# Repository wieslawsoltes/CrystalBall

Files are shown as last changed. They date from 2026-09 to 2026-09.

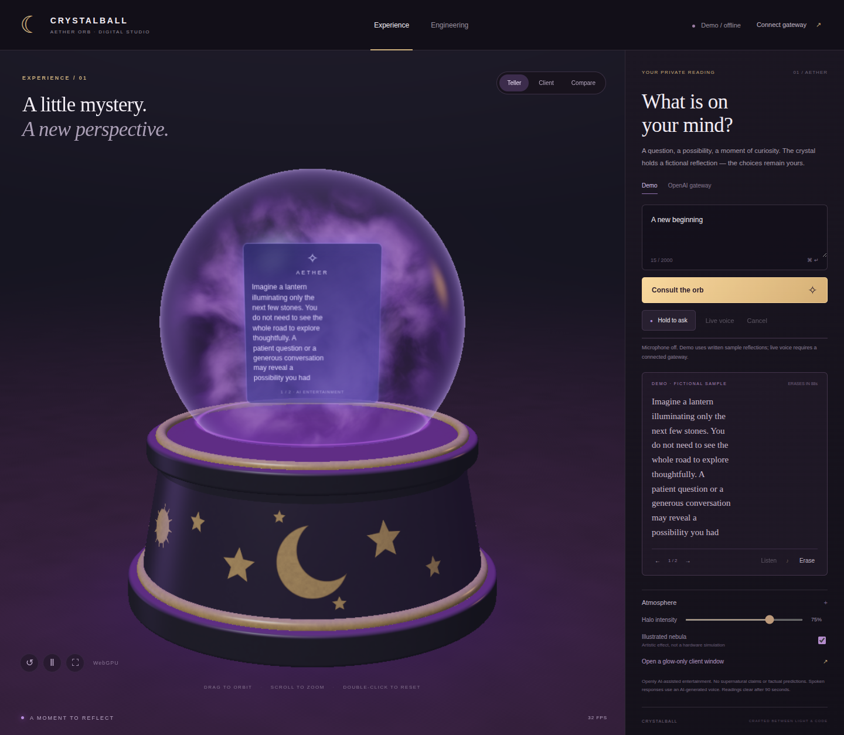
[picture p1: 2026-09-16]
verification/pages/teller.png

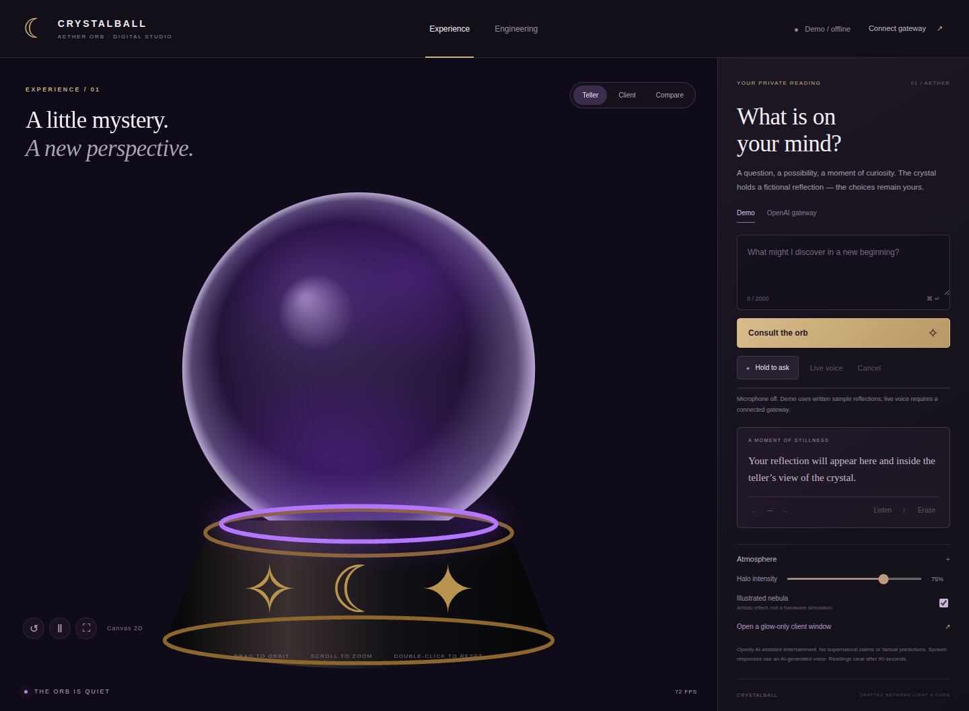
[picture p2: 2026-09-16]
verification/browser/06-fallback.png

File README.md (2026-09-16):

# CrystalBall

**Aether Orb — hardware, firmware, manufacturing engineering and a WebGPU digital studio.**

A tabletop AI-assisted entertainment prop with a hollow optical globe, an operator-facing reflected display, push-to-talk audio and a decorative illuminated base. The browser recreates the concept's sphere, purple illumination, black/gold celestial base and private teller display; the Engineering view loads the actual CAD tessellation.

**Release: engineering candidate. Not approved for production manufacture or sale.** Physical fit, optical privacy/readability, supplier selection, thermal/electrical qualification, production security and market compliance remain release gates. The browser's volumetric nebula is artistic, not a claim that LEDs create a cloud inside an empty globe. Exact visual identity has not been accepted.

## Browser prototype online

**[Open CrystalBall on GitHub Pages](https://wieslawsoltes.github.io/CrystalBall/)** — offline demo by default, including the WebGPU experience and CAD inspector. The Python gateway is hosted separately. [Pages deployment and pairing](docs/github-pages.md) explains the repository-path checks, publication manifest and CORS configuration.

## Rendering and input hardening

The renderer now caps surface area and adapter dimensions, allows only one outstanding GPU frame, suspends redundant paused/CAD submissions, and adapts resolution with hysteresis. Device loss/disposal releases GPU resources and aborts stale initialization or CAD uploads. Two-finger pinch, focused-canvas arrow keys, +/- zoom and Home reset complement mouse controls. See [resource ownership and validation](docs/renderer-lifecycle.md). These are bounded-work/resource improvements, not measured hardware FPS claims.

## Start the browser without an API key

```sh
git clone https://github.com/wieslawsoltes/CrystalBall.git
cd CrystalBall
python -m http.server 8088 --directory web
```

Open `http://localhost:8088`. No build or CDN dependencies are needed. Demo readings are explicitly fictional samples. WebGPU is preferred; Canvas 2D is a fallback. The application includes teller/client/comparison modes, orbit/zoom, a separate glow-only client window, a CAD part inspector with explosion/isolation, text paging, cancellation and timed erasure. The client display mode is a presentation feature, not an authentication boundary.

## Use your OpenAI key for text and voice

The project API key stays on your trusted gateway host. The browser receives a separate device token; it does not ask for or persist an OpenAI project key.

```sh
python factory/configure_gateway.py --unit orb-0001 --url https://orb-gateway.home.arpa --speech
cd gateway
docker compose up --build -d
```

The tool prompts for the project key without echo and creates `gateway/.env` plus `factory/private/orb-0001.json` with restrictive POSIX permissions. It refuses to overwrite existing credentials. Windows deployments need corresponding NTFS ACLs.

Configure LAN DNS to point `orb-gateway.home.arpa` at the gateway machine. The supplied Caddy configuration uses a local CA: export and explicitly trust its **public root certificate** on your clients. Do not disable certificate verification or distribute CA private keys. Open the HTTPS site, select **Connect gateway**, enter its origin and the device token from the private JSON, then ask a question or hold the microphone button.

Text generation, transcription and synthesized speech use paid OpenAI APIs. Set model names in `.env` for models available to your account. No live paid provider test has been performed in this repository's CI. Speech requires `--speech`; the voice is disclosed as AI-generated. Experimental native WebRTC voice additionally requires `--realtime`. Leave it disabled for production until live provider/device and fault-injection qualification is completed. Known calls now have durable SQLite lifecycle recovery; ambiguous creates block new voice admission until an operator reconciles them. See [recovery and cancellation design](docs/runtime-recovery.md).

The gateway runs as UID 10001 on a read-only root filesystem, uses a persistent SQLite request-admission database, enforces bounded requests and permits a single worker. Request quotas are not exact monetary caps. The browser unlocks Web Audio in the user gesture, stops microphone tracks on cancellation and uses no local/session storage for credentials or transcripts. Actual Safari/iPhone audio and microphone behavior still require representative-device testing.

## Engineering and manufacturing files

| Area | Entry point |
|---|---|
| Manufacturing handbook | [Editable guide](manufacturing/handbook.md) / [PDF](manufacturing/generated/CrystalBall-RevB-Handbook.pdf) / [HTML](manufacturing/generated/handbook.html) |
| BOM, harness, inspection and fixture tables | [Generated manufacturing package](manufacturing/generated/) |
| Native KiCad CAM | [cam-native](manufacturing/cam-native/) — read the hold notice; do not mix export sets |
| ECAD project | [KiCad project](hardware/aether-carrier.kicad_pro), [PCB](hardware/aether-carrier.kicad_pcb), [schematic](hardware/aether-carrier.kicad_sch) |
| Mechanical source | [CadQuery generator](mechanical/model.py), [Rev B assembly STEP](mechanical/Aether_Orb_RevB_Assembly.step), individual [STEP](mechanical/step/) and [STL](mechanical/stl/) |
| Firmware | [ESP-IDF project](firmware/) |
| Gateway and browser | [gateway](gateway/) / [web](web/) |
| Commissioning | [Factory tools](factory/) |
| Release evidence gate | [Requirements](manufacturing/release-plan.json) / [checker](factory/release_gate.py) / [signed evidence](factory/evidence.py) |
| First-article data evaluator | [Draft plan](manufacturing/qualification-plan.json) / [measurement tool](factory/measurements.py) |
| Test provenance | [Verification notes](verification/README.md) and [validated screenshots](preview/validated/) |

The original **63 Rev A files** are preserved byte-for-byte at commit `f430900c5269cbada520c0550a1a0a9df75eb3ed`, checked by `provenance/reva/SHA256.json`. Subsequent revisions are separate commits. `parameters.json` is generated documentation; edit the mechanical generator's `P` dictionary, not that JSON, to change geometry.

## Build firmware and provision a development unit

Use ESP-IDF **v5.5.2** with the specified ESP32-S3-DevKitC-1-N8R8. Copy only your gateway's trusted public CA certificate to `firmware/main/gateway_ca.pem` and then:

```sh
cd firmware
idf.py set-target esp32s3
idf.py build
```

Before connecting DevKit USB: remove product power, allow and verify discharge, then **remove the DevKit from both carrier sockets**. Removing the RUN shunt alone does not isolate signal paths. Do not dual-power an installed DevKit.

```sh
# From repository root, in an activated ESP-IDF environment:
python factory/provision.py --device factory/private/orb-0001.json --generate
# Explicit NVS-only flash, with the DevKit already removed from both sockets:
python factory/provision.py --device factory/private/orb-0001.json --flash --port /dev/ttyUSB0 --devkit-detached
```

Use one provisioning invocation for a unit: the tool deliberately refuses to reuse its private output folder. The passphrase is prompted without echo. NVS offsets come from the checked-in partition table. **This is plaintext development provisioning, not production secure storage.** No eFuses are automatically changed. Production signing/encryption, key custody, recovery and update policy require an approved security workflow. The three network-capable CI profiles use disposable build-only CAs and are not deployable customer firmware. The separate offline diagnostic artifact below needs no CA, but remains bench-only and physically unqualified.

## Offline first-article diagnostics

The fourth firmware profile, **factory-diagnostics**, has a separate entry point and does not initialize application networking or read device credentials. It provides ten button-driven pages: instructions, optical alignment grid, black, white, RGB bars, checkerboard, gray ramp, a 16-pixel RGB walk, a held-button 1 kHz test tone and microphone digital statistics. Capture is not saved or uploaded. Driver success and digital levels never become automatic manufacturing passes.

Read [the complete bench procedure](docs/bench-diagnostics.md) before using the diagnostic build. The same detached-DevKit programming rule applies. From an activated ESP-IDF 5.5.2 environment, in `firmware/`:

```sh
idf.py -B build-diagnostics \
  -D SDKCONFIG="$PWD/build-diagnostics/sdkconfig" \
  -D SDKCONFIG_DEFAULTS="sdkconfig.defaults;sdkconfig.diagnostics" \
  -D IDF_TARGET=esp32s3 build
```

CI inspects the linked diagnostic image and exact flash-image addresses before producing **factory-diagnostics-bench-only-NOT-CUSTOMER-FIRMWARE**. That artifact contains only the bootloader, partition table, diagnostic application, flashing metadata and a source/hash manifest. No NVS provisioning image, gateway CA or credential is included. Do not flash it to a security-enrolled production controller or mistake it for an approved customer release.

## Verify and regenerate

```sh
python -m pip install './gateway[test]' reportlab
python -m pytest gateway/tests factory/tests -q
npm --prefix web test
python tools/manufacturing.py
python factory/release_gate.py --output manufacturing/generated/release-status.json
```

The final command currently exits **1 / BLOCKED** because physical qualification and owner approvals are absent. That is intentional. Without a trust policy it validates structure only. With an independently pinned reviewer policy, it verifies Ed25519 signatures, scoped reviewer quorums, expiry/revocation and both source and manufacturing-output fingerprints. No trusted reviewer ships with the project. Neither mode certifies the product or authorizes production. See [signed evidence and measured qualification](docs/qualification-evidence.md).

GitHub Actions also compiles all four firmware profiles, runs KiCad 9.0.9 ERC/DRC/schematic parity, exports native CAM, tests a read-only Docker deployment and exercises the browser on a software WebGPU adapter with mocked OpenAI responses. See [Actions](https://github.com/wieslawsoltes/CrystalBall/actions) for the exact commit under test. Archived evidence is dated, not automatically promoted to cover later design changes.

The [bench/renderer batch record](verification/bench-renderer/summary.json) links the exact engineering, browser and public Pages runs and distinguishes their source commits. It is an engineering evidence index, not a signed release authorization.

## Remaining production gates

The handbook and generated tables distinguish selected ordering codes from unresolved suppliers, proposed assembly lengths/torques/acceptance limits from measured limits, and envelope models from real components. Optical viewing-volume tests, a fitted first article, power/inrush/fault/thermal tests, radio/EMC/ESD and market assessment, secure provisioning/recovery, real OpenAI/mobile-device validation, assembly capability and transport qualification are still required. No conformity mark or production authorization is implied by this repository.

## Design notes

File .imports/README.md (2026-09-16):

# Byte-identical Rev A baseline import

These seven consecutive binary pieces constitute an XZ-compressed tar of the supplied engineering source files, cached PCB routes, original reports, SHA-256 manifest, and STEP presentation records. This is a file-transfer container, not encrypted content. Combined archive SHA-256: `1949999319f49bb6eb79f5541bd68453d9aae72ab17f88fe3aad5c4ecf256c3f`.

`ci/import_reva.py` extracts only regular in-repository paths, runs the supplied deterministic PCB/schematic/CAD generators, restores the original STEP timestamp and presentation ordering, and verifies all 63 original files against their SHA-256 hashes. The workflow refuses to commit on any mismatch. Local reconstruction of the STEP was checked byte-for-byte: SHA-256 `f9fd1863567ffd259ce29d91b40138dd55b617014c063486c2b0213de5262db6`.

Reconstruction is only transport normalization. The original Rev A design and original validation limitations are unchanged; this is not a new production release. Subsequent engineering changes belong in separate commits.

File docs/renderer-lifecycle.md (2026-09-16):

# Browser rendering and resource ownership

The browser keeps the existing crystal/glass WGSL and artistic design. This change is resource scheduling/input hardening, not a claim of measured hardware FPS or exact physical optics.

A surface is bounded by 1.2 million pixels, 1000 px height, DPR 1.5 and the adapter's texture limit. This prevents ultra-wide or high-DPI windows from allocating unbounded swap/depth surfaces. Dynamic resolution uses submission-completion latency with hysteresis, from quality 1.0 down to 0.5; it is not a GPU timestamp-query measurement. At most one frame is outstanding. Paused scenes and stationary CAD do not submit redundant GPU frames. Scene time excludes pauses and hidden-tab intervals and clamps large scheduler discontinuities.

Renderer initialization, device acquisition, queue completion and CAD upload carry a generation identity. Disposal invalidates that generation, aborts outstanding fetches and removes observers/listeners. A late acquired device is destroyed. Lost-device fallback releases GPU buffers/textures, replaces the formerly WebGPU-bound canvas, and installs input on the replacement. Concurrent CAD requests share one transaction. Bounded streaming reads and full structural validation precede allocation; partial allocation failures destroy every owned resource. Uploaded meshes retain only metadata, GPU buffers and reusable uniforms rather than the large source geometry arrays.

Pointer capture supports orbit and two-touch pinch zoom. Cancellation/lost capture stops the gesture. Wheel units are normalized, keyboard arrows orbit, +/- zoom, and Home resets. These controls apply only to the focused canvas, preserving normal form keyboard behavior. Ctrl/Alt/Meta modified keys are not intercepted. Motion pause state is reflected in the accessible button label.

The engineering viewer renders actual tessellation in opaque/transparent passes. Its simple material shading is not a physically refractive CAD optical solver; transparent meshes are not depth-sorted per triangle. Low-resolution adaptive beauty rendering is a tradeoff, not a substitute for physical-device performance qualification.

Validation includes network-free policy/input/lifetime tests plus an actual Chromium WebGPU fixture for concurrent upload, idle redraw suppression, keyboard control, deliberate device loss and idempotent disposal. The fixture uses shipped modules with the production CSP active. The separate integration suite covers text/audio through a mocked provider, and Pages tests exercise `/CrystalBall/` before public SHA-256 verification.

Browser GPU contract: https://www.w3.org/TR/webgpu/ (reviewed 2026-09-16).

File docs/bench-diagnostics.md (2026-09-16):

# Offline first-article bench diagnostics

The `factory-diagnostics` ESP32-S3 profile runs the real display, LED and audio drivers without loading device credentials, initializing the application network, or contacting any gateway. It is **bench-only engineering firmware, not customer firmware or a manufacturing acceptance pass**. Existing automatic release gates remain blocked pending independently reviewed physical evidence.

## Power and programming boundary

Disconnect carrier power and **remove the DevKit from both carrier sockets before connecting either DevKit USB connector**. Do not attempt in-circuit USB programming or dual-power the controller. Program the removed development board, disconnect its USB cable, reinstall with the marked orientation and only then power the carrier from the reviewed 5 V source. Use the already defined current-limited first-power procedure. Do not attach a UART fixture to an unknown or powered interface. This mode deliberately needs no host serial connection while installed.

The image is for ESP32-S3-DevKitC-1-N8R8 and the Rev B module wiring. It does not burn eFuses, encrypt NVS, sign production firmware, override secure boot, or establish hardware safety. Do not use an unsigned bench image on a controller already enrolled in an irreversible production security policy. Never use a power adapter or PD jumper configuration that could deliver more than the specified input voltage.

## Build without a gateway certificate

Use ESP-IDF 5.5.2 and a clean, isolated build/config directory. From `firmware/`:

```bash
. "$IDF_PATH/export.sh"
idf.py -B build-diagnostics \
  -D SDKCONFIG="$PWD/build-diagnostics/sdkconfig" \
  -D SDKCONFIG_DEFAULTS="sdkconfig.defaults;sdkconfig.diagnostics" \
  -D IDF_TARGET=esp32s3 build
```

No `main/gateway_ca.pem` is required for this profile. `CONFIG_ORB_FACTORY_DIAGNOSTICS=y` selects a separate `factory_main.c`, excluding `app_main.c`, `network.c`, `config.c` and the CA embedding from the application. Framework dependency discovery remains unconditional because ESP-IDF expands component requirements before Kconfig values are available. Link-time checks inspect the actual ELF for absence of the application network/configuration functions and `esp_wifi_start`; this is not a claim that the SDK dependency graph contains no Wi-Fi components.

Review the generated `flasher_args.json` and all image addresses before using the standard IDF flash command, with the board physically removed as above. Do not invoke `erase-flash`: bench programming should not intentionally erase a separately provisioned NVS partition. The diagnostic application never reads that NVS content, but leaving it present does not provide confidentiality. Reinstall the intended application and requalify its provisioning before returning a board to use.

The CI bench artifact contains only the bootloader, partition table and diagnostic application, with exact addresses, a source commit and SHA-256 hashes. It contains **no NVS image, API key, gateway token, Wi-Fi password or CA**. Verify the artifact provenance and hashes before use. The hashes detect mismatched files; they do not replace a firmware-signing policy or physical inspection.

## Local controls and ten pages

Release both buttons after boot. **PAGE** advances one page per debounced press. **TALK** activates the selected LED, tone or microphone test. A held button at boot cannot trigger sound. Releasing and pressing again is required to repeat an action; none of the tests auto-repeat.

| Page | Operation | Required human observation |
|---|---|---|
| Help | Instructions; microphone and amplifier off | Correct boot/profile, legible text |
| Optical grid | Existing asymmetric orientation/calibration chart | Teller orientation, readable viewing zone, client-side leakage |
| Black | Exact RGB565 zero field, decorative pixels off | Leakage, lit/stuck pixels, ambient reflections |
| White | Exact RGB565 `0xffff`, no overlay text | Uniformity, dark/stuck pixels, optical contamination |
| Color bars | Eight vertical 40-pixel RGB565 bars | RGB/BGR assignment, column order, uniform color |
| Checker | Eight-pixel black/white cells | Pixel addressing, edge sharpness, interference patterns |
| Gray ramp | 32 horizontal intensity steps | Clipping, banding and contrast |
| Pixel walk | TALK advances one of 16 pixels in red, green then blue | Correct physical index, GRB wiring and missing/swapped pixels |
| Test tone | Hold TALK; release cancels | Speaker path, buzz/rattle, qualified acoustic measurements |
| Microphone | Hold TALK to capture; release displays statistics | Record indicator, usable signal and clipping with controlled stimulus |

Flat fields deliberately have no labels that would invalidate a uniformity/black-level test. The physical LCD's configured optical mirror transform still applies. PAGE extinguishes the pixel walk before leaving it. Driver success only means the driver accepted/completed the operation; the firmware has no optical or acoustic feedback sensor that could confirm a visible or audible pass.

The pixel walk uses one active channel at 12/255, further bounded by the global 32/255-per-channel driver cap. It is not a full-brightness power/thermal test. The 1 kHz tone is synthesized from a 24-sample table at nominal 24 kHz, with a peak digital amplitude of 2048/32768 and 10 ms start/end ramps. At most 24,000 tone frames are queued; the driver loop also checks a one-second monotonic deadline. Cancellation is checked at bounded write boundaries (100 ms write timeout), not by an independent hardware safety interrupt. Keep the speaker away from ears. Actual frequency, sound pressure, latency and amplifier startup behavior require instruments; none are certified by the digital sample values.

Microphone capture uses the same selected channel, configured sample shift, settling interval and high-pass processing as the application. The result shows sample count, integer RMS including residual DC, absolute peak, signed mean, rail-clipped sample count, zero crossings and free internal heap. These are **post-processing digital counts**, not raw converter values, dB SPL or calibrated microphone sensitivity. A zero clipping count cannot prove that the analog microphone or earlier digital stages did not saturate. The maximum retained sample count is 128,000 (eight seconds at 16 kHz), plus the driver's initial settling interval. Silence and malformed/short capture never become automatic passes. Captured WAV and scratch statistics are wiped and freed after display; no audio is saved or transmitted by this mode.

## Evidence, qualification and remaining scope

Record the exact source/artifact hash, unit serial, component lots, test setup, environment, instrument IDs, calibration status, uncertainty and observation in the existing first-article records. Use a controlled acoustic stimulus rather than customer speech. Do not store sensitive microphone recordings in repository artifacts. The factory first-article evaluator and externally authenticated release-evidence tooling remain the acceptance mechanisms; this diagnostic image only makes measurements and observations possible.

Host C tests exercise exact color pixels, bounds/canaries, PCM sign extension, RMS/peak/clipping arithmetic, and tone frequency/envelope using AddressSanitizer/UndefinedBehaviorSanitizer. CI additionally compiles the real ESP32-S3 diagnostic target without a CA and checks the linked symbol/flash-image contract. These checks do not establish actual display SPI timing, microphone I2S alignment, power integrity, optics, EMC, acoustic output, or first-article acceptance.

References reviewed 2026-09-16:
- ESP-IDF 5.5.2 build system: https://docs.espressif.com/projects/esp-idf/en/v5.5.2/esp32s3/api-guides/build-system.html
- ESP-IDF 5.5.2 I2S blocking APIs/timeouts: https://docs.espressif.com/projects/esp-idf/en/v5.5.2/esp32s3/api-reference/peripherals/i2s.html
- DevKitC-1 v1.1 mutually exclusive power options: https://docs.espressif.com/projects/esp-dev-kits/en/latest/esp32s3/esp32-s3-devkitc-1/user_guide_v1.1.html

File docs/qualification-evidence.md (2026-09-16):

# Signed release evidence and measured first articles

These tools close software integrity/authentication gaps. They do not close the product's physical, supplier, regulatory or production-security qualification gates. The repository contains no trusted reviewer, no physical measurement results and no manufacturing approval. Test keys and values are ephemeral/synthetic test fixtures only.

## Prepare a measured unit record

```sh
python factory/measurements.py template --serial orb-0001 --out factory/private/orb-0001-measurements.json
```

The generated record is `NOT_TESTED`; every value is null. The six checkpoints in `manufacturing/qualification-plan.json` are explicitly **DRAFT** and are not safety standards. Qualify the fixture, test method, instruments, operating conditions, viewing grid, numerical limits and uncertainty budget before marking a controlled plan approved. A single nominal contrast reading is not a viewing-volume privacy assessment.

Enter actual decimal values as strings, a strictly positive expanded uncertainty U, declared coverage factor k, instrument ID and its calibration validity interval, fixture ID/revision, UTC acquisition time, and an in-project relative path plus SHA-256 for the raw acquisition file. Unit conversion is deliberately not implicit. Mark the acquisition `MEASURED` only for real measurements, never to promote synthetic examples.

```sh
python factory/measurements.py evaluate --run factory/private/orb-0001-measurements.json --out factory/private/orb-0001-evaluation.json
```

The evaluator uses decimal arithmetic with bounded magnitudes/exponents. It returns PASS only when `[value-U,value+U]` lies entirely inside the declared specification interval, FAIL when disjoint, and INDETERMINATE for overlap. This is an explicit numerical guard-band decision rule, not a guarantee about a distribution or coverage probability. Any missing/duplicate reading, nonfinite value, zero uncertainty, invalid calibration interval, wrong unit, future/stale acquisition, changed plan/source fingerprint, altered attachment, draft plan or synthetic record blocks the run. Valid numerical results remain `WITHIN_DECLARED_LIMITS_REQUIRES_REVIEW`, not production approval.

## Enroll reviewers outside the source repository

Install the security extra in the controlled quality-station environment:

```sh
python -m pip install './gateway[security]'
python factory/evidence.py keygen --private-key factory/private/reviewer-a.private.pem --public-key factory/private/reviewer-a-public.json
python factory/evidence.py policy-template --out factory/private/reviewer-policy.json
```

Key generation prompts for an encryption passphrase, produces encrypted PKCS8 Ed25519 private material with restrictive POSIX permissions, and refuses replacement. Key files must be excluded from commits and distribution packages. Windows needs equivalent NTFS ACLs. Python memory copies, swap/core dumps and the operator workstation require separate security controls; encrypted files do not solve endpoint compromise. Public keys are not secret but must be authenticated during enrollment.

The policy template has **zero keys** and a two-reviewer threshold per requirement; it cannot approve anything. An authorized release authority must independently verify each reviewer's identity/public key, assign narrow requirement scopes, set UTC key validity dates and revocation state, and approve the policy through the organization's quality process. One enrolled key entry has the following shape:

```json
{
  "key_id": "SHA256_OF_RAW_PUBLIC_KEY",
  "public_key": "BASE64_OF_RAW_32_BYTE_PUBLIC_KEY",
  "reviewer": "Independently verified reviewer identity",
  "requirements": ["optical_readability_privacy"],
  "revoked": false,
  "not_before_utc": "2026-09-16T00:00:00Z",
  "expires_utc": "2026-12-16T00:00:00Z"
}
```

Those strings are placeholders, not an enrolled reviewer. Preserve the reviewed policy's exact-file SHA-256 in an independent trusted release configuration; reading a hash from beside an untrusted replacement policy is not pinning. A policy with no keys, missing requirement thresholds, duplicate key IDs or invalid scope/lifetime is rejected. Quorums count distinct enrolled reviewer identities, not how many keys one person owns.

## Bind and sign a review statement

Freeze the evaluated source checkout and regenerated manufacturing outputs before collecting approvals. Obtain both fingerprints:

```sh
python factory/release_gate.py --fingerprint
python factory/release_gate.py --materials-fingerprint
```

Create one review record per requirement with `requirement`, `status`, `reviewer`, `reviewed_utc`, `valid_until_utc`, `source_fingerprint`, `materials_fingerprint`, and `report` containing relative `path` and file `sha256`. A PASS must reflect the reviewer's actual assessment. Failed or unperformed reviews must not be rewritten as PASS. Include raw acquisition and calibration references in the reviewed report under the quality-system retention policy.

```sh
python factory/evidence.py sign --record factory/private/optics-review.json --private-key factory/private/reviewer-a.private.pem --out factory/private/optics-a.signed.json
python factory/evidence.py sign --record factory/private/optics-a.signed.json --private-key factory/private/reviewer-b.private.pem --out factory/private/optics-ab.signed.json
```

The second command adds a distinct reviewer's signature to the same immutable payload. Each signature is Ed25519 over a domain-separated restricted canonical JSON payload bound to product, revision and release-plan hash. This project encoding is explicitly **not RFC 8785/JCS**: it uses sorted keys, ASCII escapes, no floats, no duplicate keys. Decimal measurements belong in hash-bound attachments or string-valued fields. Do not swap encoding implementations without a versioned migration.

Assemble a JSON array containing exactly one completed signed envelope per requirement. Verify it against the independently pinned policy:

```sh
python factory/release_gate.py --evidence factory/private/release-envelopes.json --trust-policy factory/private/reviewer-policy.json --policy-sha256 INDEPENDENTLY_PINNED_64_HEX_DIGEST --output factory/private/signed-release-status.json
```

Invalid signatures, unauthorized/revoked/expired keys, insufficient quorums, duplicate requirements/signatures, plan/product/revision mismatch, stale source/manufacturing outputs, missing/altered reports or evidence expiry all block the check. Reports cannot be empty, exceed 64 MiB, escape the controlled root, or traverse symbolic links. Design fingerprints include build files, container configuration, factory tools and CI workflows; material fingerprints separately cover CAD, native CAM and generated manufacturing documents.

Without a pinned policy, the checker labels its result unauthenticated. Even `AUTHENTICATED_EVIDENCE_COMPLETE_REQUIRES_AUTHORIZED_SIGNOFF` is not authorization to manufacture: an authorized owner must complete the separate controlled release process. Signatures attest to who signed a statement; they do not make false data true, qualify instruments or confer certification.

References reviewed 2026-09-16: the cryptography Ed25519/PKCS8 serialization documentation, Python decimal documentation, and the project's explicit interval decision rule. No regulatory decision rule is claimed.

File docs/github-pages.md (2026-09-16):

# GitHub Pages browser deployment

The public address is `https://wieslawsoltes.github.io/CrystalBall/` after the Pages deployment succeeds. This is the HTML/JavaScript/WebGPU application, not the Python gateway or a device-control server. It opens in explicitly labeled offline demo mode and makes no AI API calls until the operator pairs a gateway and chooses a live feature.

The Pages workflow stages only tracked `web/index.html`, `web/style.css` and allowed source/assets, never the whole repository. It scans for obvious key material, writes a source-commit and per-file SHA-256 manifest to `build.json`, runs JavaScript tests and eight browser checks at `/CrystalBall/`, then publishes through the official Pages artifact/deployment actions. CSP remains enabled. No service worker, transcript persistence, analytics or third-party frontend CDN is installed. The scanner is a secondary guard, not a substitute for source review.

## Pairing a gateway from Pages

For a new gateway installation, the commissioning tool can configure the explicit Pages origin:

```sh
python factory/configure_gateway.py --unit orb-0001 --url https://orb-gateway.home.arpa --speech --browser-origin https://wieslawsoltes.github.io
```

It prompts for your project key without echo and refuses to replace existing credentials. On an already configured gateway, update only `CORS_ORIGINS` in its private environment file; do not regenerate the device token accidentally.

Deploy the gateway at an HTTPS origin with a certificate your browser trusts. Add exactly `https://wieslawsoltes.github.io` to the gateway's `CORS_ORIGINS` environment setting and restart it. The CORS entry is an **origin**: do not add `/CrystalBall/` or a trailing slash, and do not use `*`. Keep your API project key in the gateway environment. Use the separate device token in the browser's Connect gateway dialog. CORS is not authentication; bearer-token validation still applies. All projects on this GitHub Pages hostname share an origin. Use the gateway-hosted application on a dedicated trusted origin for sensitive operation.

Pages cannot host Python, keep an API key secret, reach a private gateway on behalf of a remote visitor, or bypass browser private-network/mixed-content restrictions. For a LAN gateway, the client device must be on the appropriate network and explicitly trust its public CA; browsers may require a local-network permission. Never disable TLS or browser security. When the browser's network policy prevents cross-origin LAN pairing, open the gateway-hosted HTTPS application instead.

## Repository configuration

The repository's Pages source must be **GitHub Actions**. The workflow uses `pages: write` and an OIDC deployment token, not a project API key. If Pages has never been enabled, an owner/maintainer must select Settings > Pages > Build and deployment > Source > GitHub Actions. Normal workflow tokens cannot enable a previously disabled Pages site. Then run **Publish browser to GitHub Pages** from Actions. Subsequent changes under `web/` trigger testing and deployment automatically.

The test evidence uses Chromium's software WebGPU adapter; it does not qualify actual mobile graphics performance or physical optics. The generated `build.json` identifies the actual published source independently of the newer project `main` commit.

References: GitHub's custom Pages workflow documentation and `actions/starter-workflows/pages/static.yml` (reviewed 2026-09-16).

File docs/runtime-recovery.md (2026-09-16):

# Live voice: durable lifecycle and cancellation

## Persistence and the ambiguous-create boundary

Live voice remains opt-in and requires a writable durable journal. Set `REALTIME_DATABASE=/var/lib/orb/voice.sqlite`. For existing environments without that variable, the gateway uses `BUDGET_DATABASE + '.realtime'`. Preserve the same file and mounted volume across upgrades. Do not change paths to make a cleanup warning disappear.

Before a provider POST, the supervisor commits a `RESERVED` record. After receiving a valid OpenAI call-resource Location header, it commits `ACTIVE` with the provider ID before reading the SDP response. Metadata only is stored: local handle, unit ID, provider ID, timestamps, state and cleanup status. SDP, audio, transcripts and credentials are not journaled. SQLite uses WAL and `synchronous=FULL`; the actual filesystem/storage must honor sync operations. A kernel-owned process lock rejects a second worker and releases on process exit.

After restart, every known unfinished call is sent to provider hangup before new voice admission. An interrupted reservation without a provider ID becomes `UNKNOWN`, never a retry of create. A server cannot atomically commit a local database and a remote API transaction: a crash between provider creation and receipt/persistence of its ID is fundamentally ambiguous without a provider-supported reconciliation contract. We do not assume undocumented idempotency or call-list APIs. Those records stay blocked until an operator investigates provider-side termination and records an explicit reconciliation.

Hangup attempts are serialized per call. Only HTTP 200/204 confirms cleanup. In particular, 404/410 are not automatically treated as proof of termination. Failed known cleanup stays on disk, blocks new voice admission and is retried by the running supervisor every five seconds with three bounded attempts per sweep. A storage fault latches admission closed. Text and push-to-talk do not depend on voice readiness. Authenticated capabilities include counts and reason flags, not provider call IDs.

A monotonic timer bounds the intended running voice interval; provider/network outages can prevent remote hangup. Neither this timer nor persistent request admission is an exact spending cap. Pending unresolved records are never age-deleted; closed/reconciled operational records older than seven days are pruned at startup.

## Offline operator workflow

Stop the gateway; the CLI deliberately takes the same exclusive worker lock. In the activated gateway Python environment:

```sh
PYTHONPATH=gateway python -m app.voice_admin --database /path/to/voice.sqlite inspect
```

Investigate the listed provider sessions externally. Save a nonempty report of the investigation. Reconcile one known local handle only after provider termination has been confirmed:

```sh
PYTHONPATH=gateway python -m app.voice_admin --database /path/to/voice.sqlite reconcile \
  --handle LOCAL_HANDLE_FROM_INSPECTION \
  --reviewer 'Named operator' \
  --report /path/to/termination-review.txt \
  --confirmed-provider-closed
```

The journal retains the reviewer, timestamp and report SHA-256, not its contents. This command records an operator attestation, not an independent provider observation or cryptographically authenticated release review. Keep the report under the organization's audit policy. Restart the gateway against the SAME journal. Do not delete SQLite/WAL/SHM/lock files as a recovery procedure.

## Browser cancellation ownership

Each `LiveVoice` attempt owns its media tracks, peer connection, data channel, text buffer, timer and a gateway-credential snapshot. Every awaited boundary checks that the attempt is still current. Late microphone permission, SDP response, remote-description completion and data-channel callbacks cannot reactivate an erased session. A late successful create is terminated using the original gateway credentials, even after the UI is paired elsewhere.

Local cancellation closes capture immediately. The bounded setup request may finish solely to acquire a cleanup handle; it cannot send user audio after tracks are closed. A page/process crash falls back to the durable server lifecycle. The client is still not a financial or optical-privacy security boundary.

## Verification scope

Fault-injection tests exercise persistent reservations, known/unknown restart paths, failed SDP download, malformed provider IDs, worker exclusion, disk failure, concurrent hangup/admission and missing provider confirmation. JavaScript lifecycle tests control each async boundary and assert no stale text or media restoration. Provider traffic is mocked. Actual OpenAI WebRTC connectivity, network failure behavior, Safari/iPhone media policy and physical hardware remain acceptance gates.

## Primary implementation references (accessed 2026-09-16)

- OpenAI Realtime create-call contract: https://developers.openai.com/api/reference/resources/realtime/subresources/calls/methods/create
- OpenAI Realtime hangup: https://developers.openai.com/api/reference/resources/realtime/subresources/calls/methods/hangup
- SQLite synchronous/WAL durability semantics: https://www.sqlite.org/pragma.html#pragma_synchronous

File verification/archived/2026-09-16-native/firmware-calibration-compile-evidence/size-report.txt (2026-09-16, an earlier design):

Executing action: size
Running ninja in directory /__w/CrystalBall/CrystalBall/firmware/build
Executing "ninja all"...
[1/4] cd /__w/CrystalBall/CrystalBall/firmware/build/esp-idf/esptool_py && /opt/esp/python_env/idf5.5_py3.12_env/bin/python /opt/esp/idf/components/partition_table/check_sizes.py --offset 0x8000 partition --type app /__w/CrystalBall/CrystalBall/firmware/build/partition_table/partition-table.bin /__w/CrystalBall/CrystalBall/firmware/build/aether_orb.bin
aether_orb.bin binary size 0x3b930 bytes. Smallest app partition is 0x300000 bytes. 0x2c46d0 bytes (92%) free.
[2/4] Performing build step for 'bootloader'
[1/1] cd /__w/CrystalBall/CrystalBall/firmware/build/bootloader/esp-idf/esptool_py && /opt/esp/python_env/idf5.5_py3.12_env/bin/python /opt/esp/idf/components/partition_table/check_sizes.py --offset 0x8000 bootloader 0x0 /__w/CrystalBall/CrystalBall/firmware/build/bootloader/bootloader.bin
Bootloader binary size 0x57e0 bytes. 0x2820 bytes (31%) free.
[3/4] No install step for 'bootloader'
[4/4] Completed 'bootloader'
Running ninja in directory /__w/CrystalBall/CrystalBall/firmware/build
Executing "ninja size"...
[0/1] cd /__w/CrystalBall/CrystalBall/firmware/build && /opt/esp/tools/cmake/3.30.2/bin/cmake -D "IDF_SIZE_TOOL=/opt/esp/python_env/idf5.5_py3.12_env/bin/python;-m;esp_idf_size" -D MAP_FILE=/__w/CrystalBall/CrystalBall/firmware/build/aether_orb.map -D OUTPUT_JSON= -P /opt/esp/idf/tools/cmake/run_size_tool.cmake
                            Memory Type Usage Summary                             
┏━━━━━━━━━━━━━━━━━━━━━┳━━━━━━━━━━━━━━┳━━━━━━━━━━┳━━━━━━━━━━━━━━━━┳━━━━━━━━━━━━━━━┓
┃ Memory Type/Section ┃ Used [bytes] ┃ Used [%] ┃ Remain [bytes] ┃ Total [bytes] ┃
┡━━━━━━━━━━━━━━━━━━━━━╇━━━━━━━━━━━━━━╇━━━━━━━━━━╇━━━━━━━━━━━━━━━━╇━━━━━━━━━━━━━━━┩
│ Flash Code          │       105668 │          │                │               │
│    .text            │       105668 │          │                │               │
│ DIRAM               │        70131 │    20.52 │         271629 │        341760 │
│    .text            │        54159 │    15.85 │                │               │
│    .data            │        11988 │     3.51 │                │               │
│    .bss             │         3984 │     1.17 │                │               │
│ Flash Data          │        55676 │          │                │               │
│    .rodata          │        55420 │          │                │               │
│    .appdesc         │          256 │          │                │               │
│ IRAM                │        16384 │    100.0 │              0 │         16384 │
│    .text            │        15356 │    93.73 │                │               │
│    .vectors         │         1028 │     6.27 │                │               │
│ RTC SLOW            │           32 │     0.39 │           8160 │          8192 │
│    .force_slow      │           32 │     0.39 │                │               │
│ RTC FAST            │           24 │     0.29 │           8168 │          8192 │
│    .rtc_reserved    │           24 │     0.29 │                │               │
└─────────────────────┴──────────────┴──────────┴────────────────┴───────────────┘

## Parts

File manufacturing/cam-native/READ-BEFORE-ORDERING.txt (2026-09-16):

ENGINEERING CAM CANDIDATE. NOT RELEASED FOR PRODUCTION.
Native KiCad exports: do not mix with hardware/fabrication custom exports.
Hand assembly only. Position data is a reference, not a qualified placement recipe.
Verify supplier footprints, copper weight, polarity, drill plating, legend and tolerances.

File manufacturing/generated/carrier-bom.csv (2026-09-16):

Reference | Qty | Value | Candidate ordering code | Fitted | Footprint | Qualification | Notes | Source
J1 | 1 | DevKitC-1 socket J1 | Samtec SSQ-122-03-G-S | True | Aether:Socket_1x22_P2.54_J1 | CANDIDATE; supplier drawing/FAI required | Use genuine ESP32-S3-DevKitC-1-N8R8 v1.1. Remove module before USB flashing. | https://docs.espressif.com/projects/esp-dev-kits/en/latest/esp32s3/esp32-s3-devkitc-1/user_guide_v1.1.html
J2 | 1 | DevKitC-1 socket J3 | Samtec SSQ-122-03-G-S | True | Aether:Socket_1x22_P2.54_J2 | CANDIDATE; supplier drawing/FAI required | Use genuine ESP32-S3-DevKitC-1-N8R8 v1.1. Remove module before USB flashing. | https://docs.espressif.com/projects/esp-dev-kits/en/latest/esp32s3/esp32-s3-devkitc-1/user_guide_v1.1.html
J3 | 1 | 5V INPUT | Phoenix Contact 1729128 | True | Aether:Terminal_1x02_P5.08_J3 | CANDIDATE; supplier drawing/FAI required | 5.08 mm 2-position terminal; 5 V only. + pin 1; - pin 2. Verify exact holder body. | https://www.phoenixcontact.com/en-us/products/pcb-terminal-block-mkds-15-2-508-1729128
F1 | 1 | PTC 2.5A | Littelfuse RXEF250 | True | Aether:PTC_P5.08_F1 | CANDIDATE; supplier drawing/FAI required | Thermal resettable fuse, not a precise electronic current limiter. Check hold-current derating. | https://www.littelfuse.com/products/polyswitch-resettable-ptcs/radial-leaded/rxef
Q1 | 1 | AO3401A | AO3401A | True | Aether:SOT-23_Q1 | CANDIDATE; supplier drawing/FAI required | P-channel reverse-input protection. Pin 1 G, pin 2 S, pin 3 D. NOT reverse-current blocking while on. | https://www.aosmd.com/res/data_sheets/AO3401A.pdf
R1 | 1 | 100k | RC0805FR-07100KL | True | Aether:R_0805_2012Metric_R1 | CANDIDATE; supplier drawing/FAI required
C1 | 1 | 1000uF 10V | Panasonic EEU-FR1A102 | True | Aether:CP_Radial_D10_P5_C1 | CANDIDATE; supplier drawing/FAI required | Polarized; + pin 1. Measure PD startup/inrush with this bulk capacitance. | https://industrial.panasonic.com/ww/products/pt/aluminum-cap/models/EEUFR1A102
JP1 | 1 | RUN POWER | Samtec TSW-102-07-G-S + 2.54mm shunt | True | Aether:PinHeader_1x02_P2.54_JP1 | CANDIDATE; supplier drawing/FAI required | Fitted shunt for RUN. Remove DevKit completely for USB flashing; do not dual-power.
J4 | 1 | LCD | JST B8B-XH-A(LF)(SN) | True | Aether:XH_1x08_P2.50_J4 | CANDIDATE; supplier drawing/FAI required | Vertical keyed XH header; pin 1 is square; qualify exact supplier drawing. | https://www.jst-mfg.com/product/pdf/eng/eXH.pdf
R2 | 1 | 33R | RC0805FR-0733RL | True | Aether:R_0805_2012Metric_R2 | CANDIDATE; supplier drawing/FAI required
R3 | 1 | 33R | RC0805FR-0733RL | True | Aether:R_0805_2012Metric_R3 | CANDIDATE; supplier drawing/FAI required
J5 | 1 | MIC 3V3 | JST B6B-XH-A(LF)(SN) | True | Aether:XH_1x06_P2.50_J5 | CANDIDATE; supplier drawing/FAI required | Vertical keyed XH header; pin 1 is square; qualify exact supplier drawing. | https://www.jst-mfg.com/product/pdf/eng/eXH.pdf
J6 | 1 | AMP 5V | JST B6B-XH-A(LF)(SN) | True | Aether:XH_1x06_P2.50_J6 | CANDIDATE; supplier drawing/FAI required | Vertical keyed XH header; pin 1 is square; qualify exact supplier drawing. | https://www.jst-mfg.com/product/pdf/eng/eXH.pdf
R4 | 1 | 10k | RC0805FR-0710KL | True | Aether:R_0805_2012Metric_R4 | CANDIDATE; supplier drawing/FAI required
U1 | 1 | SN74AHCT1G125 | SN74AHCT1G125DBVR | True | Aether:SOT-23-5_U1 | CANDIDATE; supplier drawing/FAI required | 5V TTL input buffer; /OE grounded. Qualify TI DBV footprint before ordering. | https://www.ti.com/lit/ds/symlink/sn74ahct1g125.pdf
C2 | 1 | 100nF | GRM21BR71H104KA01L | True | Aether:C_0805_2012Metric_C2 | CANDIDATE; supplier drawing/FAI required
R5 | 1 | 100k | RC0805FR-07100KL | True | Aether:R_0805_2012Metric_R5 | CANDIDATE; supplier drawing/FAI required
R6 | 1 | 330R | RC0805FR-07330RL | True | Aether:R_0805_2012Metric_R6 | CANDIDATE; supplier drawing/FAI required
J7 | 1 | RING 5V | JST B3B-XH-A(LF)(SN) | True | Aether:XH_1x03_P2.50_J7 | CANDIDATE; supplier drawing/FAI required | Vertical keyed XH header; pin 1 is square; qualify exact supplier drawing. | https://www.jst-mfg.com/product/pdf/eng/eXH.pdf
J8 | 1 | PTT | JST B2B-XH-A(LF)(SN) | True | Aether:XH_1x02_P2.50_J8 | CANDIDATE; supplier drawing/FAI required | Vertical keyed XH header; pin 1 is square; qualify exact supplier drawing. | https://www.jst-mfg.com/product/pdf/eng/eXH.pdf
J9 | 1 | PAGE | JST B2B-XH-A(LF)(SN) | True | Aether:XH_1x02_P2.50_J9 | CANDIDATE; supplier drawing/FAI required | Vertical keyed XH header; pin 1 is square; qualify exact supplier drawing. | https://www.jst-mfg.com/product/pdf/eng/eXH.pdf
J10 | 1 | REC LED | JST B2B-XH-A(LF)(SN) | True | Aether:XH_1x02_P2.50_J10 | CANDIDATE; supplier drawing/FAI required | Vertical keyed XH header; pin 1 is square; qualify exact supplier drawing. | https://www.jst-mfg.com/product/pdf/eng/eXH.pdf
R7 | 1 | 1k | RC0805FR-071KL | True | Aether:R_0805_2012Metric_R7 | CANDIDATE; supplier drawing/FAI required
R8 | 1 | 10k | RC0805FR-0710KL | True | Aether:R_0805_2012Metric_R8 | CANDIDATE; supplier drawing/FAI required
R9 | 1 | 10k | RC0805FR-0710KL | True | Aether:R_0805_2012Metric_R9 | CANDIDATE; supplier drawing/FAI required
C3 | 1 | 100nF | GRM21BR71H104KA01L | True | Aether:C_0805_2012Metric_C3 | CANDIDATE; supplier drawing/FAI required
TP1 | 1 | 5V_SYS | Keystone 5000 test loop | True | Aether:TestPoint_THT_D2_TP1 | CANDIDATE; supplier drawing/FAI required
TP2 | 1 | GND | Keystone 5000 test loop | True | Aether:TestPoint_THT_D2_TP2 | CANDIDATE; supplier drawing/FAI required
TP3 | 1 | 3V3 | Keystone 5000 test loop | True | Aether:TestPoint_THT_D2_TP3 | CANDIDATE; supplier drawing/FAI required
TP4 | 1 | LED_DIN | Keystone 5000 test loop | True | Aether:TestPoint_THT_D2_TP4 | CANDIDATE; supplier drawing/FAI required

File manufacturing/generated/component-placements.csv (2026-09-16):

Reference | X_mm | Y_mm | Rotation_deg | Side | Coordinate convention
J1 | 14.0 | 16 | 0 | TOP | PCB origin upper-left; X right; Y down
J2 | 36.86 | 16 | 0 | TOP | PCB origin upper-left; X right; Y down
J3 | 72 | 82 | 0 | TOP | PCB origin upper-left; X right; Y down
F1 | 57 | 78 | 0 | TOP | PCB origin upper-left; X right; Y down
Q1 | 59 | 67 | 0 | TOP | PCB origin upper-left; X right; Y down
R1 | 54 | 67 | 0 | TOP | PCB origin upper-left; X right; Y down
C1 | 80 | 70 | 0 | TOP | PCB origin upper-left; X right; Y down
JP1 | 42 | 77 | 0 | TOP | PCB origin upper-left; X right; Y down
J4 | 92 | 15 | 0 | TOP | PCB origin upper-left; X right; Y down
R2 | 72 | 21 | 0 | TOP | PCB origin upper-left; X right; Y down
R3 | 72 | 27 | 0 | TOP | PCB origin upper-left; X right; Y down
J5 | 53 | 16 | 0 | TOP | PCB origin upper-left; X right; Y down
J6 | 92 | 44 | 0 | TOP | PCB origin upper-left; X right; Y down
R4 | 81 | 54 | 0 | TOP | PCB origin upper-left; X right; Y down
U1 | 63 | 44 | 0 | TOP | PCB origin upper-left; X right; Y down
C2 | 59 | 40 | 0 | TOP | PCB origin upper-left; X right; Y down
R5 | 57 | 48 | 0 | TOP | PCB origin upper-left; X right; Y down
R6 | 70 | 42 | 0 | TOP | PCB origin upper-left; X right; Y down
J7 | 77 | 40 | 0 | TOP | PCB origin upper-left; X right; Y down
J8 | 9 | 77 | 0 | TOP | PCB origin upper-left; X right; Y down
J9 | 20 | 77 | 0 | TOP | PCB origin upper-left; X right; Y down
J10 | 31 | 77 | 0 | TOP | PCB origin upper-left; X right; Y down
R7 | 48 | 62 | 0 | TOP | PCB origin upper-left; X right; Y down
R8 | 46 | 53 | 0 | TOP | PCB origin upper-left; X right; Y down
R9 | 46 | 58 | 0 | TOP | PCB origin upper-left; X right; Y down
C3 | 54 | 35 | 0 | TOP | PCB origin upper-left; X right; Y down
TP1 | 69 | 61 | 0 | TOP | PCB origin upper-left; X right; Y down
TP2 | 76 | 61 | 0 | TOP | PCB origin upper-left; X right; Y down
TP3 | 46 | 36 | 0 | TOP | PCB origin upper-left; X right; Y down
TP4 | 71 | 49 | 0 | TOP | PCB origin upper-left; X right; Y down

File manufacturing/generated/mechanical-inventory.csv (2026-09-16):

Part | Modeled_qty | Role | Material | Process | BBox_mm | Notes
01_base_shell | 1 | FABRICATED/OPTICAL PART | Black PETG or PA12 | FDM/SLS, no optical surfaces | 148.0 x 137.0 x 65.0 | 3 mm wall; 4.2 mm heat-set pilot must be tuned using fit coupon. No metal-filled finish near antenna.
02_bottom_cover | 1 | FABRICATED/OPTICAL PART | Black PETG / PA12 | FDM/SLS | 147.4 x 136.7 x 9.0 | M3 body screws through counterbores; independent PCB M3x6 self-tap screws enter separate posts from above.
03_optical_deck | 1 | FABRICATED/OPTICAL PART | Black PETG / PA12 | FDM/SLS | 147.4 x 136.7 x 8.8 | Screen plane nominal Z68.5. Display stand-off length is adjustable using washers; measure actual LCD revision.
04_optical_globe | 1 | FABRICATED/OPTICAL PART | Optical PMMA, clear, UV-stabilized | Optical forming/polishing - NOT FDM | 120.0 x 120.0 x 100.0 | 120 OD, 2 nominal wall, cut at 40 mm below centre. Opening OD89.443 / ID84.000. Supplier optical qualification required.
05_globe_bond_flange | 1 | FABRICATED/OPTICAL PART | Clear cast PMMA | CNC/laser cut; supplier-bond to globe | 100.0 x 100.0 x 2.0 | 100 OD / 84 ID / 2 thick. Bond is structural: test pull-off. No cyanoacrylate vapour near clear surfaces.
06_globe_gasket | 1 | FABRICATED/OPTICAL PART | Black silicone, 40-50 Shore A | Die-cut 0.8 mm sheet | 100.0 x 100.0 x 0.8
07_retainer_left | 1 | FABRICATED/OPTICAL PART | Gold-painted PETG / PA12 | FDM/SLS then nonconductive finish | 55.85 x 112.0 x 2.0
08_retainer_right | 1 | FABRICATED/OPTICAL PART | Gold-painted PETG / PA12 | FDM/SLS then nonconductive finish | 55.85 x 112.0 x 2.0
09_mirror_frame | 1 | FABRICATED/OPTICAL PART | Matte black PA12 / PETG | FDM/SLS; smooth glass-contact pads | 74.0 x 49.819 x 69.956 | Glass rests on edge lip with 0.2 mm silicone pads. Rotation 45-55 deg normal use; clamp with M3 pivot screws.
10_mirror_retainer | 1 | FABRICATED/OPTICAL PART | Matte black PA12 / PETG | FDM/SLS | 74.0 x 49.163 x 69.497
11_beamsplitter_OPTICAL | 1 | FABRICATED/OPTICAL PART | 70R/30T coated optical glass, rear AR | Optical fabrication - NOT FDM | 70.0 x 46.705 x 66.106 | 70x80x1 mm, visible band, specify usable incidence 45-55 degrees. Coating uniformity, wedge/ghosting and polarization to vendor review.
12_upright_left | 1 | FABRICATED/OPTICAL PART | Matte black PA12 / PETG | FDM/SLS | 4.0 x 14.0 x 44.0 | M2x6 foot screws, M3 pivot clamp. No overlong screws into LCD envelope.
12_upright_right | 1 | FABRICATED/OPTICAL PART | Matte black PA12 / PETG | FDM/SLS | 4.0 x 14.0 x 44.0 | M2x6 foot screws, M3 pivot clamp. No overlong screws into LCD envelope.
13_halo_rail | 1 | FABRICATED/OPTICAL PART | Black PETG / PA12 | FDM/SLS | 118.0 x 118.0 x 10.0 | Use flexible strip, not a 60 mm rigid ring: that would obstruct the display. Locate the no-LED gap on +Y.
14_halo_diffuser | 1 | FABRICATED/OPTICAL PART | Opal silicone or translucent TPU | Cast/mould or FDM optical trial | 112.4 x 112.4 x 8.0 | Only peripheral glow; no mist, lasers or true volumetric image. Black out operator-facing quadrant after optical calibration.
15_speaker_cradle | 1 | FABRICATED/OPTICAL PART | Black PETG / PA12 | FDM/SLS | 54.5 x 44.0 x 33.0 | 40 mm speaker envelope; strap retention. Mount to matching blind deck holes at (-8,-40) and (37,-38) with M3x6 self-tapping screws. Strap through cradle secures speaker; qualify purchased speaker envelope.
16_pd_module_sled | 1 | FABRICATED/OPTICAL PART | Black PETG / PA12 | FDM/SLS | 26.0 x 31.0 x 6.0 | Tray screws at (19/39,57) to case bosses. Foam tape plus cable tie retains PD board; adjust strip thickness to align USB centre Z32.0 with 12x7 case slot. Vendor PCB hole pattern is NOT claimed exact.
17_fit_coupon | 1 | PROCESS COUPON; not an assembly part | Same material and print profile as enclosure | FDM/SLS | 68.0 x 28.0 x 6.0 | Not an assembly part. Print first. Verify inserts, M2/M3 holes and beamsplitter thickness slots.
REF_carrier_PCB | 1 | REFERENCE ONLY; procure via electrical/module BOM | FR-4 2 oz copper | Purchased PCB | 100.0 x 90.0 x 1.6 | Board outline/mounting holes only. Pads and copper in KiCad/Gerbers.
REF_esp32_devkit | 1 | REFERENCE ONLY; procure via electrical/module BOM | Purchased module | Envelope proxy | 25.4 x 62.74 x 4.6 | Envelope orientation only; board antenna keepout is authoritative in PCB files.
REF_LCD_1770 | 1 | REFERENCE ONLY; procure via electrical/module BOM | Adafruit 1770 | Envelope proxy | 81.28 x 62.484 x 6.1 | LCD optical plane and connector clearance require measurement. Display is 320x240 landscape.
REF_LCD_active | 1 | REFERENCE ONLY; procure via electrical/module BOM | TFT active area | Envelope proxy | 57.6 x 43.2 x 0.2
REF_speaker_40mm | 1 | REFERENCE ONLY; procure via electrical/module BOM | 8 ohm 2W speaker | Envelope proxy | 40.0 x 40.0 x 20.0
REF_amp_module | 1 | REFERENCE ONLY; procure via electrical/module BOM | Adafruit 3006 | Envelope proxy | 20.0 x 18.0 x 2.0
REF_mic_module | 1 | REFERENCE ONLY; procure via electrical/module BOM | Adafruit 3421 | Envelope proxy | 16.7 x 2.0 x 12.7 | Mount bottom acoustic port facing +Y at (-27,60,52), using a 1.3 mm closed-cell foam gasket to panel. Do not cover port with adhesive. Secure board with nonconductive tie through carrier.
18_microphone_clip | 1 | FABRICATED/OPTICAL PART | Black PETG / PA12 | FDM/SLS | 22.0 x 4.5 x 17.0 | Foam tape to panel; guide the microphone port to the 2 mm panel bore. Clip supports board edges, not MEMS package. Insulate back side; no conductive screws near microphone pins.
REF_PD_HUSB238 | 1 | REFERENCE ONLY; procure via electrical/module BOM | Adafruit 5807 | Envelope proxy | 18.0 x 31.5 x 3.4 | USB mouth centre is adjusted to the case Z32 slot with thin foam shims after measuring delivered module. No assumed mounting-hole pattern.

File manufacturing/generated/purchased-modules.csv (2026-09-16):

ID | Qty | Candidate part/specification | Supplier | Qualification notes
M01 | 1 | ESP32-S3-DevKitC-1-N8R8 v1.1 | Espressif | Verify board revision, PSRAM, pinout and seating height
M02 | 1 | 1770 ILI9341 2.8-inch TFT breakout | Adafruit | IM1/IM2/IM3 closed; IM0 open; verify active optical plane
M03 | 1 | 3421 SPH0645 I2S microphone | Adafruit | SEL to ground; microphone port unobstructed
M04 | 1 | 3006 MAX98357A amplifier | Adafruit | BTL speaker pair; neither lead to ground
M05 | 1 | 5807 HUSB238 PD breakout | Adafruit | 5 V jumper closed; 3 A current request; verify unloaded voltage
M06 | 1 | 16 x WS2812B on flexible strip | Supplier selection required | Pitch, width, bend radius and power qualification required
M07 | 1 | 40 mm envelope / 8 ohm / 2 W speaker | Supplier selection required | Exact part, depth, lugs and acoustic response unqualified
M08 | 1 | USB-C external 5 V / 3 A capable supply | Supplier selection required | Market-compliant finished adapter; PD/cable qualification
M09 | 1 | USB-C cable for selected supply | Supplier selection required | Connector, current, bend and strain relief qualification
M10 | 2 | 12 mm nominal panel momentary NO switch | Supplier selection required | Hole 12.2; rear depth and contact quality unqualified
M11 | 1 | M6 nominal panel master switch | Supplier selection required | DC switching rating and contact heating qualification
M12 | 1 | 3 mm red panel recording LED | Supplier selection required | 3.2 hole; colour/current/retention qualification
M13 | 1 | 120 mm OD / 2 mm wall optical PMMA globe | Custom optical supplier | Open-bottom sphere; flange bond and optical quality qualification
M14 | 1 | 70 x 80 x 1 mm visible beamsplitter | Custom optical supplier | Nominal 70R/30T front coating; rear AR; angle/polarization review
M15 | 1 | Optical edge pads / gasket / non-shedding foam | Supplier selection required | Compatibility, compression, ageing and retention qualification

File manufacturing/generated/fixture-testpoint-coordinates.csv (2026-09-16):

TP | Net | PCB_X | PCB_Y_down | Template_X | Template_Y_up | Interface
TP1 | 5V_SYS | 69 | 61 | 79 | 39 | Loop contact; fixture/sleeve selection unqualified
TP2 | GND | 76 | 61 | 86 | 39 | Loop contact; fixture/sleeve selection unqualified
TP3 | 3V3 | 46 | 36 | 56 | 64 | Loop contact; fixture/sleeve selection unqualified
TP4 | LED_DIN | 71 | 49 | 81 | 51 | Loop contact; fixture/sleeve selection unqualified

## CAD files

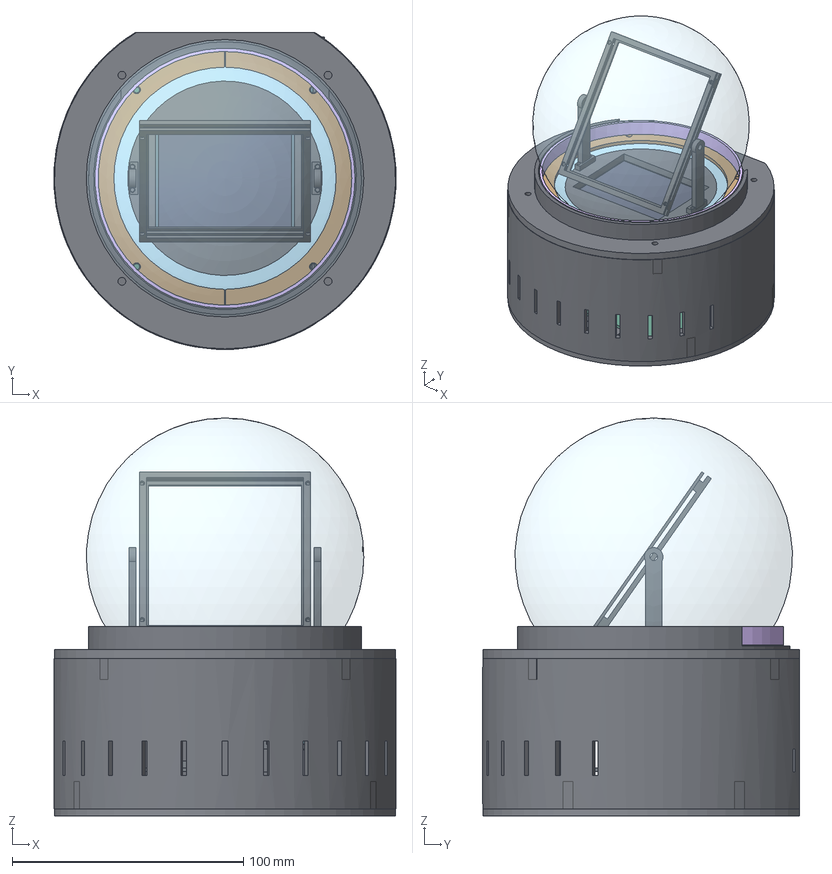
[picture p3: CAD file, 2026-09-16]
mechanical/Aether_Orb_RevB_Assembly.step
147.8 x 137.0 x 172.0 mm
01_base_shell
02_bottom_cover
03_optical_deck
04_optical_globe
05_globe_bond_flange
06_globe_gasket
07_retainer_left
08_retainer_right
09_mirror_frame
10_mirror_retainer
11_beamsplitter_OPTICAL
12_upright_left
12_upright_right
13_halo_rail
14_halo_diffuser
15_speaker_cradle
16_pd_module_sled
REF_carrier_PCB
REF_esp32_devkit
REF_LCD_1770
REF_LCD_active
REF_speaker_40mm
REF_amp_module
REF_mic_module
18_microphone_clip
REF_PD_HUSB238

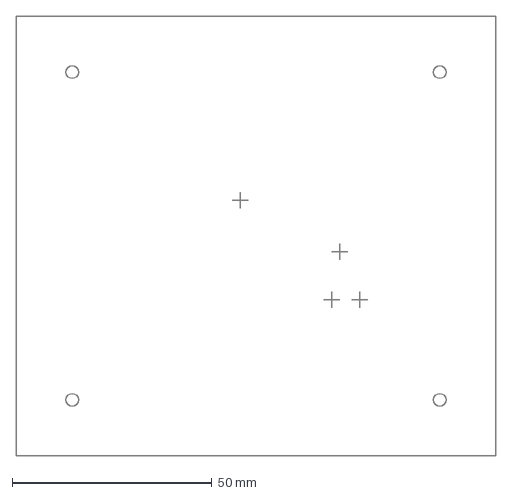
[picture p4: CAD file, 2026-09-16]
manufacturing/generated/fixture-alignment-only.dxf
120.0 x 110.0 mm

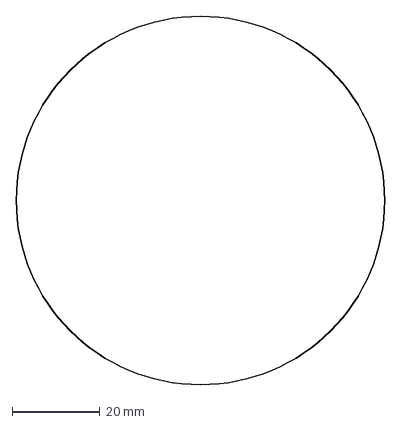
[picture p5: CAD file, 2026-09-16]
mechanical/dxf/globe_flange_100-84-2mm.dxf
84.0 x 84.0 mm

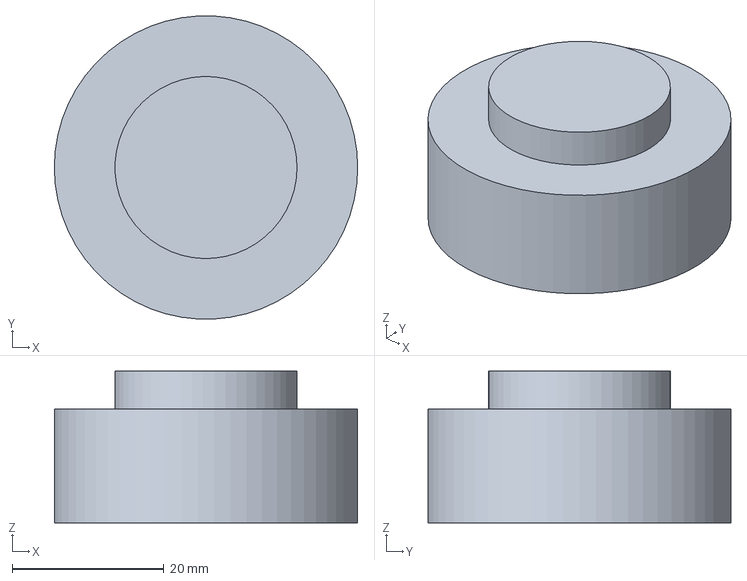
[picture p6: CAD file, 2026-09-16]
mechanical/step/REF_speaker_40mm.step
40.0 x 39.9 x 20.0 mm

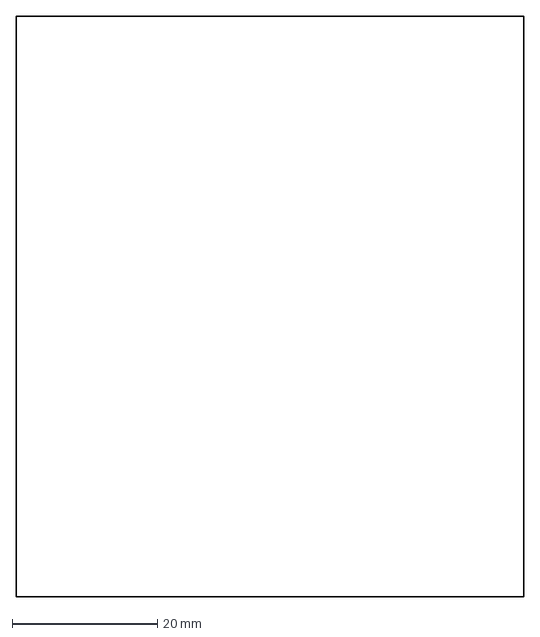
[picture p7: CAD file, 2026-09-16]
mechanical/dxf/beamsplitter_70x80x1mm.dxf
70.0 x 80.0 mm

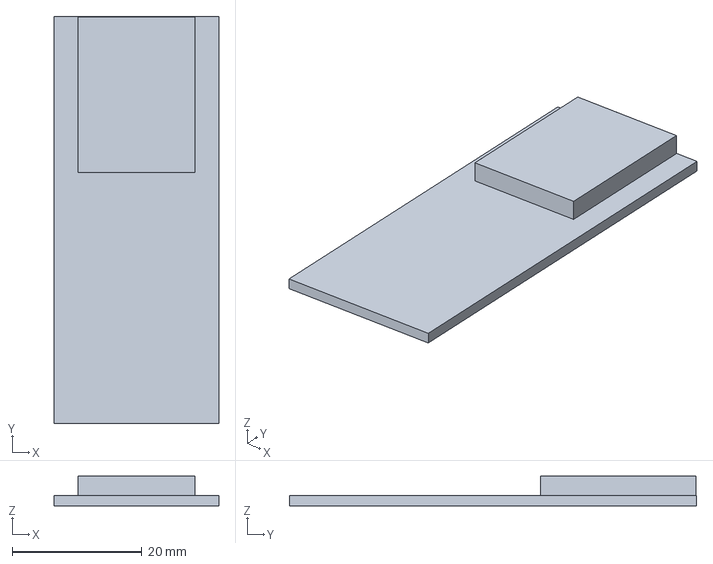
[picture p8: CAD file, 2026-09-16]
mechanical/step/REF_esp32_devkit.step
25.4 x 62.7 x 4.60 mm

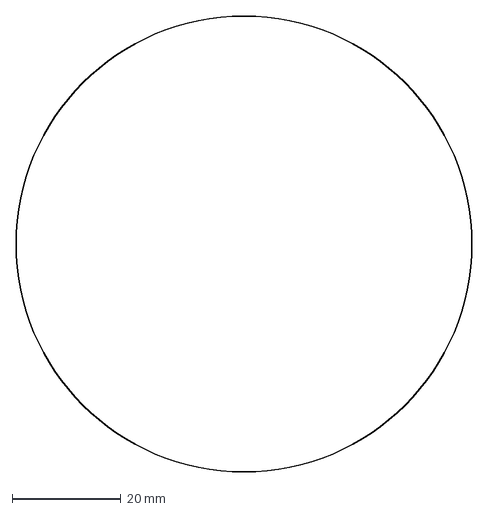
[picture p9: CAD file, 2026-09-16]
mechanical/dxf/globe_gasket_100-84-0.8mm.dxf
84.0 x 84.0 mm

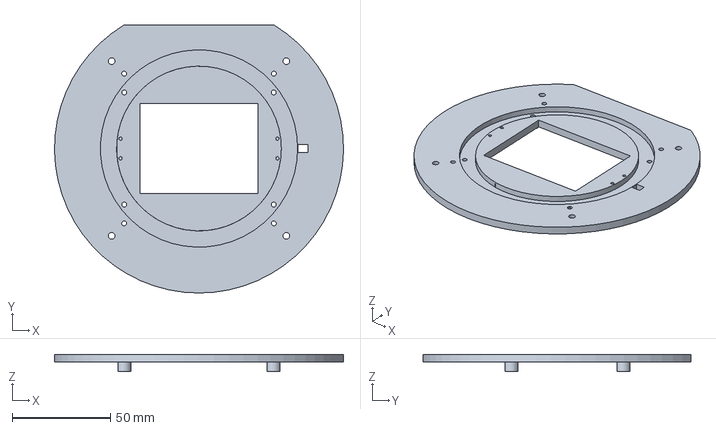
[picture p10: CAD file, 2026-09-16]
mechanical/step/03_optical_deck.step
147.4 x 136.7 x 8.80 mm

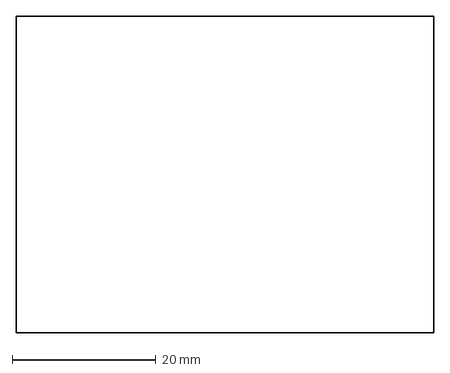
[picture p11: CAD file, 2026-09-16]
mechanical/dxf/LCD_privacy_film_58x44mm.dxf
58.0 x 44.0 mm

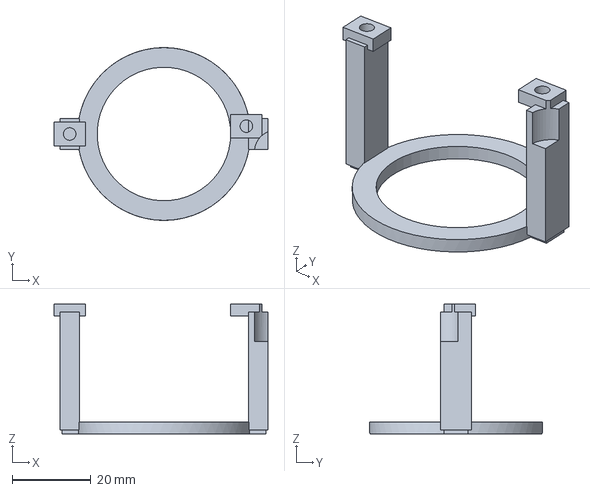
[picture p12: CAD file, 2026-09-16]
mechanical/step/15_speaker_cradle.step
54.5 x 44.0 x 33.0 mm

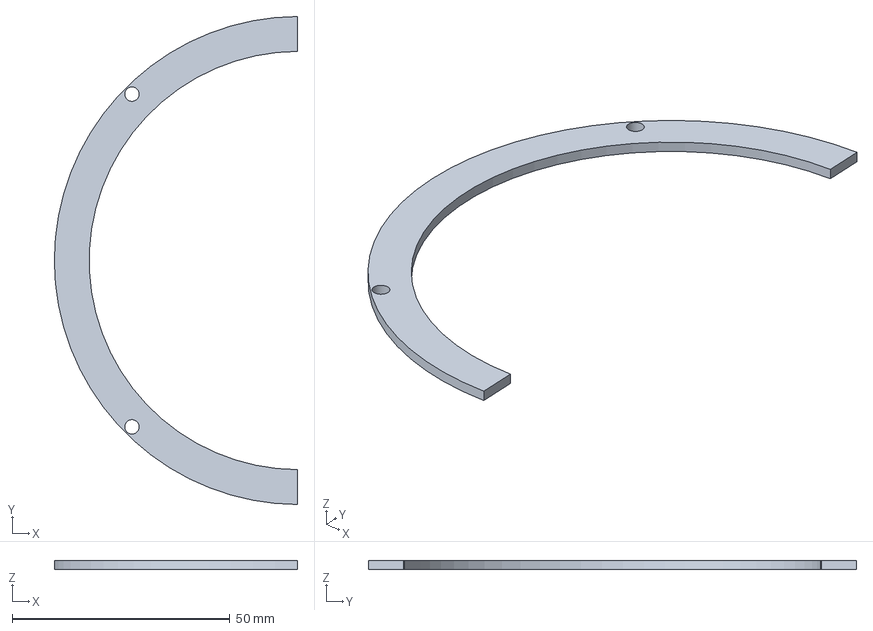
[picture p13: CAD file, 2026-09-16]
mechanical/step/07_retainer_left.step
55.9 x 112.0 x 2.00 mm

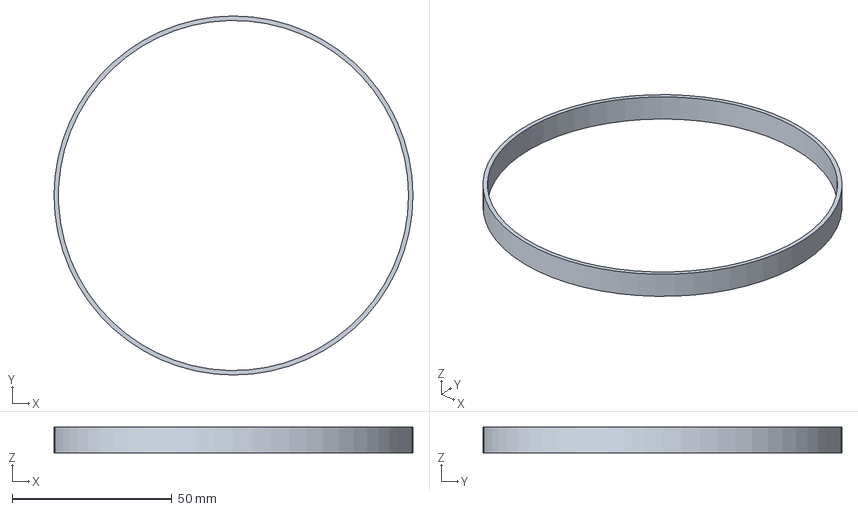
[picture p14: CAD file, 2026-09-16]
mechanical/step/14_halo_diffuser.step
112.4 x 112.4 x 8.00 mm

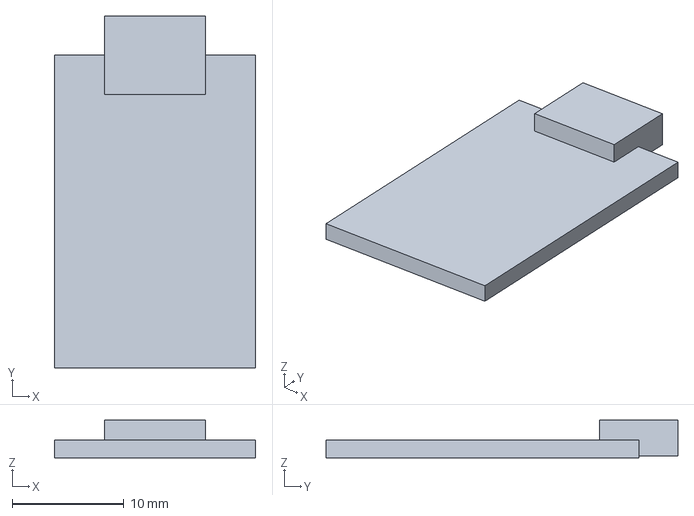
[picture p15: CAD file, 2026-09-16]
mechanical/step/REF_PD_HUSB238.step
18.0 x 31.5 x 3.40 mm

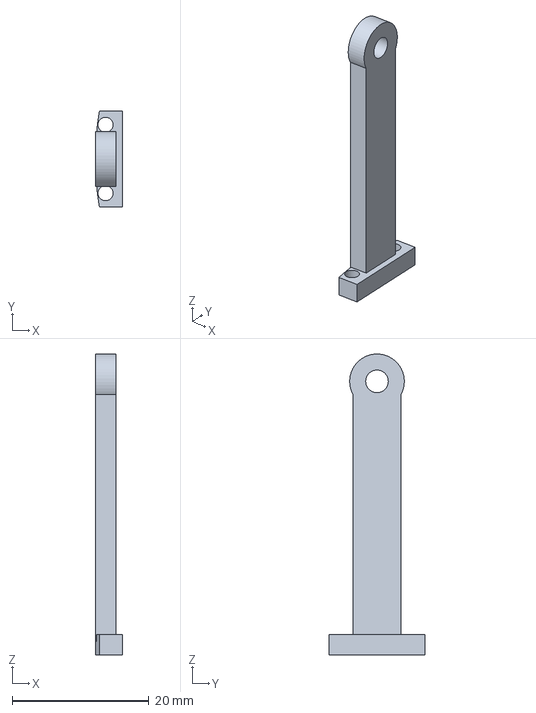
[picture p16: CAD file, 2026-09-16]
mechanical/step/12_upright_left.step
4.00 x 14.0 x 44.0 mm

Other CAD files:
mechanical/step/12_upright_right.step
mechanical/step/REF_mic_module.step
mechanical/step/06_globe_gasket.step
mechanical/step/05_globe_bond_flange.step
mechanical/Aether_Orb_RevA_Assembly.step
mechanical/step/01_base_shell.step
mechanical/step/02_bottom_cover.step
mechanical/step/04_optical_globe.step
mechanical/step/08_retainer_right.step
mechanical/step/09_mirror_frame.step
mechanical/step/10_mirror_retainer.step
mechanical/step/11_beamsplitter_OPTICAL.step
mechanical/step/13_halo_rail.step
mechanical/step/16_pd_module_sled.step
mechanical/step/17_fit_coupon.step
mechanical/step/18_microphone_clip.step
mechanical/step/REF_LCD_1770.step
mechanical/step/REF_LCD_active.step
mechanical/step/REF_amp_module.step
mechanical/step/REF_carrier_PCB.step
mechanical/stl/01_base_shell.stl
mechanical/stl/02_bottom_cover.stl
mechanical/stl/03_optical_deck.stl
mechanical/stl/04_optical_globe.stl
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

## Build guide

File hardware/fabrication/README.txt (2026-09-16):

ENGINEERING FABRICATION CANDIDATE - NOT PRODUCTION RELEASED
100 x 90 mm, 1.60 mm FR-4, 2 layers, 2 oz (70 um) finished outer copper.
Lead-free HASL or ENIG; green mask both sides; white top legend.
Profile is nominal finished outline. Drill units mm, decimal format, common origin lower-left.
PTH holes plated; four 3.20 mm NPTH mounting holes NOT plated. Vias tented.
No controlled impedance. Smallest route 0.30 mm, clearance 0.20 mm.
No stencil included: Rev B is hand-assembled. No panelization or tooling rails authorized.
Run independent KiCad DRC/ERC, supplier footprint review and CAM review before releasing even a prototype order.

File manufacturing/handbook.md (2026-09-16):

# CrystalBall / Aether Orb
## Rev B manufacturing engineering handoff

**Status: ENGINEERING CANDIDATE. Not authorized for production or sale.**

This package is a buildable design and verification starting point, not a certificate of conformity. Native ECAD checks, nominal mechanical checks, firmware compilation and mocked software tests are different evidence classes. None establishes optical privacy, physical fit, safe temperature, radio performance or regulatory compliance. Production requires all requirements in release-plan.json, a qualified bill of materials and an authorized manufacturing release.

The original 63-file Rev A baseline is preserved byte-for-byte at Git commit f430900c5269cbada520c0550a1a0a9df75eb3ed. Rev B changes are separate commits. Do not mix Rev A mechanical parts with Rev B parts. Preserve the full commit identifier and archive SHA-256 with every supplier request, first article and engineering change.

## 1. Product definition and configuration

The device is a tabletop, openly AI-assisted entertainment prop. The operator presses TALK, records up to eight seconds, releases the button and reads a bounded fictional reflection on an LCD reflected through a coated plate inside a hollow globe. The client-facing viewing zone is intended to show a decorative glow rather than legible text. This viewing-zone goal is unvalidated. The design is not an invisible screen, omnidirectionally private display or security boundary.

The physical globe is nominally 120 mm outside diameter, 2 mm wall optical PMMA. A solid acrylic sphere is incompatible with the internal mirror. The base is nominally 148 mm wide, 137 mm deep at the flattened operator panel, with overall product height approximately 172 mm. The curved globe will refract and distort display light. The browser's artistic purple cloud volume is an aesthetic simulation; LEDs in an empty clear globe do not create that volumetric nebula. Use the browser's non-artistic mode when explaining the physical lighting target.

Rev B is a module-based, hand-assembled carrier design. Controller: genuine ESP32-S3-DevKitC-1-N8R8 v1.1. Display: Adafruit 1770 ILI9341 SPI configuration. Microphone: Adafruit 3421 SPH0645. Amplifier: Adafruit 3006 MAX98357A. Input: Adafruit 5807 HUSB238 breakout, explicitly configured for 5 V, 3 A. Illumination: sixteen WS2812B pixels in a perimeter arrangement. Speaker: 40 mm envelope, 8 ohm, 2 W target; exact part has not been qualified.

The external power adapter, cable, speaker, switches, LED strip, inserts, screws, optical supplier and coatings still need exact part numbers and incoming qualification. A generic envelope or material description is not an approved vendor list. Do not substitute DevKit variants, LCD controllers, XH-compatible clones or a different optical plate without engineering review.

## 2. Deliverables and source of truth

hardware/aether-carrier.kicad_pro opens the carrier, its root schematic and three hierarchical child sheets. Project-local Aether.kicad_sym, sym-lib-table, fp-lib-table and Aether.pretty must remain alongside the project. hardware/design.json is the generated component/pad/net contract. tools/design.py is its authoring source. tools/pcb.py and tools/schematic.py regenerate ECAD outputs; cached routes remain under version control.

mechanical/model.py is the parametric mechanical authoring source. Its P dictionary is the input configuration. parameters.json and parts.json are generated documentation, not live configuration files. mechanical/step contains individual assembly-coordinate solids; mechanical/stl contains print-oriented meshes. The assembled Rev B STEP and per-part STEPs are nominal geometry; REF components are purchased-module envelopes, not certified vendor models. Optical DXFs are nominal outlines, not optical-quality fabrication processes.

web/assets/assembly.json is the CAD tessellation used in the Engineering viewer. The Experience renderer is a separate artistic real-time shader, not an optical solver. Firmware pins are generated from the same electrical source. gateway hosts the browser and proxies bounded requests to OpenAI; project API keys never belong in firmware or browser storage.

manufacturing/generated contains machine-readable carrier BOM, component placements, all pad/net connections, harness table, mechanical inventory, fastener schedule, proposed acceptance plan, blank first-article records, and fixture alignment geometry. Native KiCad CAM is produced by the engineering verification workflow and delivered separately as cam-native. Never combine individual layers from different export sets or commits.

## 3. PCB fabrication and incoming inspection

Specify a 100 x 90 mm nominal finished profile, two-layer 1.60 mm FR-4, 2 oz nominal finished outer copper, green solder mask both sides and white top legend. Confirm copper weight, board-thickness tolerance, dielectric grade, surface finish and fabricator capability in writing. ENIG or lead-free HASL must be selected and recorded for the lot; the design does not authorize an arbitrary change after qualification. No controlled impedance is specified. This does not remove the requirement to measure SPI/I2S/LED timing and return-current behavior.

Nominal routing is 0.30 mm signal, 0.50 mm 3.3 V, 0.60 mm GND and 0.80 mm main 5 V, with 0.20 mm minimum clearance and 0.70/0.35 mm via diameter/drill. Actual minimum clearances and connectivity must come from the same revision's native DRC. Trace width alone is not a current-capacity qualification. The design has no continuous ground plane; evaluate return paths, radio coexistence and radiated/conducted behavior before accepting production routing.

There are four 3.20 mm non-plated mounting holes at PCB coordinates (4,4), (96,4), (4,86), (96,86). All coordinates in generated electrical tables are component-side X-right, Y-down, millimetres from the PCB's upper-left origin. The nominal antenna keepout spans X=7..44, Y=0..13.5. Do not put copper, conductive paint, cables, metallic labels or hardware into the antenna region without RF review.

Use native KiCad Gerbers and separate plated/non-plated Excellon drill outputs from one job. Check the Gerber job, outline closure, units, origin, hole plating, mask openings, legend polarity marks and annular rings in an independent CAM viewer. The IPC-D-356 netlist supports bare-board electrical testing. All bare boards require continuity/isolation testing against the released netlist. Supplier DFM review and accepted land-pattern drawings are release inputs, not replaced by ERC/DRC.

Incoming checks: record supplier, purchase order, PCB revision, date/lot, thickness and finish. Inspect under magnification for copper defects, solder-mask slivers, blocked holes and incorrect legend. Dry-fit sockets, terminal and keyed headers before soldering. The custom footprints were generated from the circuit contract; independently compare every pad pitch, pin number, hole diameter and body envelope with the exact purchased part's drawing.

Rev B assembly is manual. No stencil process, placement-machine centroid convention, reflow recipe, panelization, tooling rails or automated optical-inspection programme is qualified. positions-reference.csv is an assembly reference, not permission to run an automated PCBA line. Such a process requires its own NPI validation.

## 4. Carrier assembly and electrical precautions

Work on an ESD-controlled bench. Use an isolated, current-limited low-voltage bench supply for commissioning and a compliant external USB-C adapter for intended operation. Do not construct or modify mains circuitry. Keep the globe and optical coatings away from soldering fumes, adhesive vapour and conductive debris.

Populate SMD resistors/capacitors, U1 and Q1 first; inspect pin orientation, wetting and bridges before adding tall through-hole parts. Q1 AO3401A has gate pin 1, source pin 2, drain pin 3. It provides reverse-input protection only. It is not an eFuse, precise current limiter, overvoltage protector or guaranteed reverse-current blocker while on. F1 RXEF250 is a temperature-dependent resettable fuse; hold-current derating and thermal interaction must be measured. C1 is polarized, 1000 uF, 10 V, positive pin 1. Its inrush can upset a USB-C source and must be tested.

U1 must be SN74AHCT1G125 at 5 V with the specified pinout. Do not replace AHCT with HC: input threshold compatibility is part of the design. R6 limits LED data edge current; it is not LED power protection. The amplifier shutdown pull-down must be present so audio is muted during reset. Both speaker terminals are active bridge outputs. Never connect either speaker wire to ground, USB shield or an earth-referenced oscilloscope clip. Use a suitable differential measurement method.

Install the J1/J2 sockets parallel using an unpowered alignment fixture, then remove the fixture. Verify 22.86 mm row separation and actual seating height. Populate keyed XH headers with square-pad pin 1 matching the harness table. XH pitch is 2.50 mm, not 2.54 mm. Inspect C1, fuse and terminal body clearances. Fit the RUN shunt only when ready for powered carrier tests.

Configure the HUSB238 board for 5 V and a 3 A current request. Keep the 5 V voltage-select jumper closed and follow the manufacturer's current-jumper table. All voltage-select jumpers open is not the specified safe configuration. Independently measure the PD board output, unloaded and under the approved load, before connecting it to J3. A 3 A request does not by itself prove the source or cable can supply 3 A; approved adapter/cable behaviour is an acceptance test.

USB service rule: switch off and unplug product power, allow C1 to discharge and verify it with a meter, then remove the DevKit from BOTH carrier sockets before connecting either DevKit USB port. Removing only JP1 does not isolate signal-pin paths. Never have USB and carrier power connected to the installed DevKit at once. Reinsert only after USB is disconnected and orientation has been checked.

## 5. Harness specification and routing

Use genuine XH housings and compatible contacts qualified to the wire conductor area and insulation diameter. Candidate family: XHP-2/3/6/8 housing and SXH-001T-P0.6 contact; the supplier must validate these against the exact header and crimp drawing. The generated harness table specifies net-to-labelled-module-pad connections, not an assumed order on a generic breakout. Verify labelled pad identity on each purchased module.

Proposed wire: flexible stranded 26 AWG for short signal/module harnesses; 24 AWG for the LED branch; 22 AWG for the PD-to-switch-to-J3 input circuit. These are engineering selections pending contact fit, voltage-drop, temperature and handling tests. Use red for positive supply, black for GND, distinct colours for signal functions. Label both ends with harness ID and pin 1. Record final cut length, strip length and crimp tooling after the first article. The provided lengths are starting estimates with service slack, not released production cut lengths.

Route LCD and microphone/I2S harnesses separately from speaker leads and high-current LED wiring. Keep supply and return conductors adjacent. Keep the speaker pair twisted and away from the microphone. Do not bundle an I2S clock beside the acoustic port. Retain harnesses to the base with nonconductive ties or qualified adhesive mounts; no sharp bends, tension on module solder pads or pinch points under the deck. Respect the RF keepout. Use strain relief on the USB breakout and master switch. A cable must not support the globe or mirror frame.

Harness acceptance: inspect crimp conductor/insulation wings under magnification; confirm terminal latch engagement; perform continuity and pin-to-pin short tests with electronics disconnected; perform supplier-specified pull tests on representative coupons. Do not tin conductors before crimping. Supplier crimp height, strip length and pull-force limits must be recorded; do not invent a universal value.

## 6. Mechanical production, fits and optical assembly

Coordinate datums: +Z is up; +Y is the operator; -Y is the client. The base/bottom interface defines datum A at Z=0; the globe/optical axis defines X=Y=0. PCB conversion is mechanical X=PCB X-50 and mechanical Y=45-PCB Y. PCB underside is at Z=9. The deck top is Z=72. Verify actual assembled heights because sockets, terminals and module connectors are represented incompletely.

Printed structural parts are black PETG for iterative FDM or PA12 for a qualified SLS process. Start FDM trials at 0.20 mm layer height, four perimeters and 35% infill, then determine the final process from strength, creep, fit and thermal coupons. These settings are not validated process parameters. Do not print the optical globe as a transparent FDM part. Gold decoration must remain nonconductive near the antenna. Protect the mirror aperture and acoustic port from paint, flocking fibres and adhesive.

Proposed first-article tolerances, subject to supplier capability approval: general non-optical printed dimensions +/-0.30 mm, drilled/reamed fastener holes +/-0.10 mm, relative optical mounting positions +/-0.20 mm. Do not apply these values blindly to optical curvature, surface finish or coatings. Print the fit coupon before heat-setting inserts. The nominal 4.2 mm insert pilots must be adjusted to the selected insert manufacturer's installation requirements and verified for pull-out and rotation resistance.

The base and deck each use four main fastener locations. Main shell bosses lie on R=67 mm at 30,150,210,330 degrees; deck supports on R=63 mm at 45,135,225,315 degrees. Fastener lengths in the generated schedule are initial selections, not approved engagements. Confirm each screw does not bottom, break through, foul wiring or load an optical element. Establish torque by testing the exact material/insert/screw combination, not a steel fastener table alone.

The LCD mounting pilots are currently round 2.5 mm holes at +/-38.1, +/-28.575 mm. Despite an older model comment about slots, the CAD does not provide an adjustable slot at those pilots. Dry-fit the real LCD board and quantify alignment before modifying geometry. The speaker cradle attaches at (-8,-40) and (37,-38). Rev B relieves its corner around the southeast deck support. The microphone and clip moved to X=-27; do not reuse the earlier X=-37 panel position.

Panel interfaces are nominal envelopes: TALK and PAGE holes diameter 12.2 mm at X=-22 and X=0, Z=39; REC LED diameter 3.2 mm at X=18,Z=39; master switch diameter 6.4 mm at X=-22,Z=22; USB opening 12 x 7 mm centred X=29,Z=32; microphone aperture diameter 2.0 mm at X=-27,Z=52. All are on the +Y operator side. Select actual parts and verify rear body depth, nut access, panel thickness and cable bends before release.

Globe procurement: nominal OD 120 mm, optical PMMA wall 2 mm, concentricity and optical zone to supplier-agreed inspection limits. The nominal spherical cut at Z=72 gives approximately 89.44 mm outside and 84.00 mm inside opening diameter. Bond a separate 100 OD / 84 ID / 2 mm PMMA flange using a supplier-qualified PMMA process. Inspect for crazing, stress, residual solvent, bond integrity and optical contamination. Do not prescribe a generic solvent adhesive without compatibility trials.

Globe support uses the 100/84 mm silicone gasket, nominal 0.8 mm, and split retaining rings. Clamp loads act on the flange/gasket, not on the unsupported sphere. Verify compression and retention under the intended carry/transport cases. Mirror specification: 70 x 80 x 1 mm plate, nominal 70% reflection / 30% transmission in the visible range, front beamsplitter coating and rear antireflection treatment, reviewed at the actual incidence angles and LCD polarization. Supplier quality limits for wedge, scratch/dig, flatness and spectral balance are required before purchase release.

The Rev B mirror frame has relieved pivots and hard stops separating the glass and retainer. Fit qualified compliant edge pads; do not force the plate into a printed pocket or use the glass as a load-bearing spacer. The retainer must not contact optical glass hard-to-hard. Verify actual pad thickness/compression, edge support, thermal expansion allowance and handling retention. Tighten only to the qualified process limit. Wear suitable eye protection when handling thin glass.

## 7. Optical bench acceptance

Begin without the decorative globe or LEDs, using the LCD calibration pattern and matte-black surroundings. Fit the coated face in the direction specified by the optical supplier. Adjust the mirror through its intended 45-55 degree range, set the operator position and record angle, eye distance and eye height. In a simplified central-ray construction, 45 degrees redirects a vertical ray horizontally; 55 degrees gives roughly 20 degrees elevation. That construction does not include globe refraction, off-axis LCD emission or polarization.

Set firmware MIRROR_X/MIRROR_Y from the actual reflected LEFT/RIGHT/TOP pattern, not a photograph of a direct LCD. Check full character legibility, corner clipping, double images and colour fringes. Install the globe and repeat. Then add the diffuser/LEDs gradually and measure contrast. Do not accept a brightness setting that makes the operator strain or exposes legible text to the client zone.

Define operator and client viewing volumes before testing. Proposed characterization grid: distances 0.4,0.6,0.8 m; azimuth steps of 15 degrees around both sides; seated and standing eye heights; ambient illuminance 10,100,500 lux. Record coordinates, meter calibration, displayed randomized strings, readable-character fraction and luminance/contrast for each position. A proposed target is at least 95% operator character recognition and at most 5% client character recognition in the owner-approved zones. Those are engineering goals, not measured results or a universal privacy guarantee.

Direct sight of the upward-facing LCD from standing or side positions may require additional louvers, masking or a revised geometry. Rear-surface reflections, transmitted light, shiny fasteners and globe caustics must be considered. No current software test can close this item. When the target fails, revise the optics and corresponding mechanical model, regenerate the meshes and repeat the whole viewing-volume test. Do not change a report threshold to turn a failed design into a pass.

## 8. Power-up and first-article functional procedure

Before controller installation, inspect polarity and verify supply-to-ground is not shorted after capacitors settle. Record the meter and test method; a charged capacitor can make a resistance reading misleading. Energize through a current-limited 5 V source with a conservative initial limit and no display/LED/amplifier loads. Stop immediately on current limiting, incorrect rail voltage, unexpected heating or smell. Increase load only in planned steps within the source and component ratings.

Proposed rail acceptance targets: 5 V system steady state 4.75-5.25 V; 3.3 V 3.135-3.465 V. Verify at the DevKit and far-end modules during Wi-Fi transmit, full permitted LED pattern, capture and speaker operation. Record startup/inrush and brownout waveforms with appropriate probing; minimum transient voltage must meet the actual module data-sheet requirements. No nominal wattage calculation replaces these measurements.

Test buttons, REC indicator and amplifier shutdown first. The REC indicator should illuminate only during deliberate capture. Confirm the microphone clock stops outside capture. Hold TALK beyond eight seconds: recording must stop and not restart until release/re-press. Hold PAGE during the entire auto-erase interval: text must still be cleared. Disconnect Wi-Fi while an answer is displayed: the previous answer must disappear. Use the calibration firmware to verify SPI orientation and geometry before the operational firmware.

Acquire a known acoustic tone/speech sample and inspect amplitude, polarity, sample alignment, clipping and noise. Default MIC_SHIFT=14 is not qualified by compilation. Validate against the SPH0645 timing and ESP32 receive format on the actual board. Check amplifier mute transitions and pop/noise at power, reset and cancellation. Speaker gain is intentionally limited, but acoustic output must still be measured.

Run at the maximum permitted combination of radio activity, LED brightness and audio. Record ambient temperature and stabilized case/component temperatures, supply current and voltage drop for at least a two-hour engineering soak. A proposed external accessible-surface goal is <=45 C at 25 C ambient; applicable safety requirements and actual intended ambient range must govern final limits. Do not perform destructive short/fault tests without a reviewed method, protected supply and suitable equipment.

## 9. Gateway and browser commissioning

The project key is configured on the trusted gateway host using factory/configure_gateway.py. The tool writes a per-device token file and gateway/.env with restrictive POSIX permissions and refuses overwrite. Browser pairing uses the device token, not the OpenAI project key. On Windows, apply equivalent NTFS ACLs. Keep private files, backups, swap and crash dumps under the owner's security controls. The archive intentionally excludes these files.

Start Docker Compose from gateway. It builds from the repository root using the explicit .dockerignore allowlist, serves the browser and API together, runs the application as UID 10001 with a read-only root filesystem and writes admission metadata to a dedicated SQLite volume. Use a single application worker. The budget is request-admission control, not an exact monetary cap. Provider account limits and operational spending alerts remain necessary.

Configure LAN DNS for the chosen hostname. Caddy uses its local certificate authority in the bundled configuration. Export only the Caddy root certificate to trusted clients and firmware; keep its private signing keys private. Trust that certificate explicitly on each intended device. HTTPS certificate verification must stay enabled. A certificate issued for another hostname will not work. A public deployment requires an independently reviewed authentication, reverse-proxy and TLS configuration.

Speech and Realtime are off unless explicitly enabled. Text and push-to-talk transcription use the gateway key and may incur API charges. Public speech must be disclosed as AI-generated. The browser resumes Web Audio in the button gesture before waiting for the network. Test actual Safari/iPhone audio, mute-switch behavior, microphone permissions, interruption, backgrounding and Bluetooth routing on representative devices. Desktop Chromium software rendering does not prove mobile behavior.

Realtime uses native WebRTC and a server-created session. The gateway limits session duration and active slots and attempts cleanup on close/timeout. The current call ledger is process-local; crash recovery of provider sessions needs further qualification or a durable ledger before enabling it in production. Keep REALTIME_ENABLED=false until that gate is closed. Browser tabs clear stored credentials only in application memory; language-runtime string copies are not a secure-memory guarantee.

## 10. Firmware commissioning and production security

Use ESP-IDF v5.5.2 and the selected N8R8 hardware target. Copy the trusted gateway public root certificate to firmware/main/gateway_ca.pem. Never copy a private CA key into the firmware directory. Build with idf.py set-target esp32s3 and idf.py build. CI uses a disposable one-day test root only to prove compilation; it is not a deployable image and must not be flashed to a customer unit.

The development partition table places NVS at 0x9000, size 0x6000, PHY at 0xf000 and the factory app at 0x10000. factory/provision.py reads the actual table instead of assuming those offsets. It prompts for the Wi-Fi passphrase without echo, generates a correctly quoted NVS CSV and optionally calls the official ESP-IDF generator. Flashing NVS requires an explicit port and --devkit-detached acknowledgement. It does not erase the whole chip, flash an application or alter eFuses.

This NVS path is plaintext development provisioning. Secure Boot v2, flash/NVS encryption, production signing-key custody, anti-rollback/update policy, recovery, credential rotation, debug/JTAG policy and manufacturing station hardening are not completed production features. eFuse operations are irreversible and must be implemented under the owner's approved security workflow on sacrificial qualification units first. Never automate fuse burning merely to obtain a green software gate.

Record firmware source commit, build toolchain, sdkconfig, certificate fingerprint, binary digest, unit serial and provisioning outcome in a private manufacturing record. Do not put raw tokens or passwords in public test evidence. Use a separate non-secret record for the product archive. Initial configuration failure and loss of network must fail visibly, keep the microphone inactive and avoid queueing recordings for later upload.

## 11. Release control, packaging and service

release-plan.json defines eighteen release requirements. factory/release_gate.py computes a source fingerprint and requires one PASS record per requirement, reviewer, timezone-qualified timestamp, matching fingerprint and an accessible report whose SHA-256 matches. Missing, failed, duplicated, stale or altered evidence blocks release. The default mode checks structure only. Supplying an independently pinned reviewer policy enables Ed25519 evidence authentication, per-requirement reviewer quorums, expiry/revocation checks, plan binding and separate manufacturing-output fingerprints. No reviewer keys are trusted by default. Signatures authenticate statements, not the truth of measurements; organizational production sign-off is still mandatory. See docs/qualification-evidence.md for the complete signing and policy-enrollment procedure.

Supplier approval must include exact ordering codes, revision/lot traceability, no-substitution rules, measured fit, crimp process, optical inspection and material/process changes. Establish assembly torque, fixture setup, leak/retention limits if applicable, functional limits and process capability on first articles before freezing the traveler. Keep deviations separate and explicitly dispositioned. Defective units must be quarantined, not silently reworked without a record.

For the target markets, obtain a competent assessment of radio/EMC/ESD, product safety, chemicals/material restrictions, environmental obligations, privacy and labeling. No conformity mark or certificate is authorized by this package. Define intended users, indoor environment, supply specification, duty cycle and handling restrictions before selecting test standards. The external adapter's compliance does not automatically qualify the assembled radio product.

Package the globe supported by its flange/base, not by direct point loads on the optical sphere. Use a clean protective optical sleeve, non-shedding cushioning, no adhesive on coated glass and an inner restraint that prevents the base and globe striking each other. Qualify packaging dimensions, cushioning density and transport/drop procedures with the actual finished unit. Do not ship an assembled globe without retention and transport evidence. Include power/service restrictions and the AI-entertainment/voice disclosure in user instructions.

Unplug before service. Clean only with optical-supplier-approved materials; PMMA and coatings can be damaged by unsuitable solvents. Do not direct sunlight through the globe onto flammable surfaces. Revalidate optical alignment and viewing-zone leakage after any globe, mirror, display, firmware orientation or mechanical change. Retire or reprovision a unit when its per-device token is revoked.

## 12. Measurement evaluation and live-voice recovery

factory/measurements.py creates a blank NOT_TESTED unit record from manufacturing/qualification-plan.json. The six supplied checkpoints are draft engineering limits, not qualified safety or optical acceptance criteria. Record actual values, positive expanded uncertainty, coverage factor, instrument identity, calibrated interval, fixture revision, UTC acquisition time and the hash of a raw acquisition attachment. Missing, stale, synthetic, mismatched or uncalibrated data blocks the evaluator.

A value passes the numerical interval rule only when the entire value-plus/minus-uncertainty interval is within declared limits. A fully disjoint interval fails; overlap is INDETERMINATE. A DRAFT plan blocks acceptance even when all numerical intervals pass. Computational evaluation does not acquire measurements, verify a claimed instrument calibration, establish statistical confidence or authorize manufacture. Expand the plan to every approved operating condition and optical viewing point before qualification.

Experimental browser live voice commits call reservations before the provider request and persists known provider IDs before consuming the SDP answer. On restart, known unfinished calls are terminated before new admission. A lost response without a persisted ID is UNKNOWN and requires operator reconciliation; it is not silently retried or age-deleted. The single-worker process lock, durable journal and cleanup retries are software safeguards, not guaranteed spending caps or proof of real-provider behavior. Keep the same persistent database volume across upgrades and follow docs/runtime-recovery.md for offline inspection/reconciliation.

The GitHub Pages browser is a separate static presentation deployment. Permit only an explicitly approved frontend origin in CORS, retain bearer-token authentication and TLS verification, and never publish project keys in web assets. Prefer the gateway-hosted application on an isolated trusted origin for sensitive operation.

## 13. Primary technical references

The following sources informed interfaces and workflows. Verify the exact part revision and current applicability during supplier qualification; no claim of certification is derived from these links.

- ESP32-S3 DevKitC-1 v1.1: https://docs.espressif.com/projects/esp-dev-kits/en/latest/esp32s3/esp32-s3-devkitc-1/user_guide_v1.1.html
- ESP-IDF 5.5.2 NVS generator: https://docs.espressif.com/projects/esp-idf/en/v5.5.2/esp32s3/api-reference/storage/nvs_partition_gen.html
- Espressif security enablement workflows: https://docs.espressif.com/projects/esp-idf/en/stable/esp32s3/security/security-features-enablement-workflows.html
- ILI9341 display module: https://www.adafruit.com/product/1770
- HUSB238 configuration: https://learn.adafruit.com/adafruit-husb238-usb-type-c-power-delivery-breakout/pinouts
- I2S microphone: https://learn.adafruit.com/adafruit-i2s-mems-microphone-breakout/pinouts
- MAX98357A interfaces: https://learn.adafruit.com/adafruit-max98357-i2s-class-d-mono-amp/pinouts
- TI AHCT buffer: https://www.ti.com/product/SN74AHCT1G125
- KiCad 9 CLI: https://docs.kicad.org/9.0/en/cli/cli.html
- Official KiCad CI images: https://hub.docker.com/r/kicad/kicad
- OpenAI key safety: https://help.openai.com/en/articles/5112595-best-practices-for-api-key-safety
- OpenAI speech output: https://developers.openai.com/api/docs/guides/text-to-speech
- OpenAI Realtime: https://developers.openai.com/api/docs/guides/realtime
- Plate beamsplitter fundamentals: https://www.thorlabs.com/beamsplitter-guide

- Ed25519 signing API: https://cryptography.io/en/latest/hazmat/primitives/asymmetric/ed25519/
- SQLite WAL durability: https://www.sqlite.org/pragma.html#pragma_synchronous

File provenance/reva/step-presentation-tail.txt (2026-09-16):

#39672 = MECHANICAL_DESIGN_GEOMETRIC_PRESENTATION_REPRESENTATION('',(
    #39673),#37169);
#39673 = STYLED_ITEM('color',(#39674),#36981);
#39674 = PRESENTATION_STYLE_ASSIGNMENT((#39675));
#39675 = SURFACE_STYLE_USAGE(.BOTH.,#39676);
#39676 = SURFACE_SIDE_STYLE('',(#39677));
#39677 = SURFACE_STYLE_FILL_AREA(#39678);
#39678 = FILL_AREA_STYLE('',(#39679));
#39679 = FILL_AREA_STYLE_COLOUR('',#39680);
#39680 = COLOUR_RGB('',7.999999887273E-02,7.999999887273E-02,
  8.999999692505E-02);
#39681 = MECHANICAL_DESIGN_GEOMETRIC_PRESENTATION_REPRESENTATION('',(
    #39682),#16156);
#39682 = STYLED_ITEM('color',(#39683),#11950);
#39683 = PRESENTATION_STYLE_ASSIGNMENT((#39684));
#39684 = SURFACE_STYLE_USAGE(.BOTH.,#39685);
#39685 = SURFACE_SIDE_STYLE('',(#39686));
#39686 = SURFACE_STYLE_FILL_AREA(#39687);
#39687 = FILL_AREA_STYLE('',(#39688));
#39688 = FILL_AREA_STYLE_COLOUR('',#39689);
#39689 = COLOUR_RGB('',0.139999997847,0.1599999992,0.199999998682);
#39690 = MECHANICAL_DESIGN_GEOMETRIC_PRESENTATION_REPRESENTATION('',(
    #39691),#28517);
#39691 = STYLED_ITEM('color',(#39692),#27362);
#39692 = PRESENTATION_STYLE_ASSIGNMENT((#39693));
#39693 = SURFACE_STYLE_USAGE(.BOTH.,#39694);
#39694 = SURFACE_SIDE_STYLE('',(#39695));
#39695 = SURFACE_STYLE_FILL_AREA(#39696);
#39696 = FILL_AREA_STYLE('',(#39697));
#39697 = FILL_AREA_STYLE_COLOUR('',#39698);
#39698 = COLOUR_RGB('',7.999999887273E-02,9.999999991362E-02,
  0.130000001093);
#39699 = MECHANICAL_DESIGN_GEOMETRIC_PRESENTATION_REPRESENTATION('',(
    #39700),#37518);
#39700 = STYLED_ITEM('color',(#39701),#37188);
#39701 = PRESENTATION_STYLE_ASSIGNMENT((#39702));
#39702 = SURFACE_STYLE_USAGE(.BOTH.,#39703);
#39703 = SURFACE_SIDE_STYLE('',(#39704));
#39704 = SURFACE_STYLE_FILL_AREA(#39705);
#39705 = FILL_AREA_STYLE('',(#39706));
#39706 = FILL_AREA_STYLE_COLOUR('',#39707);
#39707 = COLOUR_RGB('',7.999999887273E-02,0.309999994343,0.350000000377
  );
#39708 = MECHANICAL_DESIGN_GEOMETRIC_PRESENTATION_REPRESENTATION('',(
    #39709),#20962);
#39709 = STYLED_ITEM('color',(#39710),#20436);
#39710 = PRESENTATION_STYLE_ASSIGNMENT((#39711));
#39711 = SURFACE_STYLE_USAGE(.BOTH.,#39712);
#39712 = SURFACE_SIDE_STYLE('',(#39713));
#39713 = SURFACE_STYLE_FILL_AREA(#39714);
#39714 = FILL_AREA_STYLE('',(#39715));
#39715 = FILL_AREA_STYLE_COLOUR('',#39716);
#39716 = COLOUR_RGB('',0.580000000354,0.389999993588,0.149999997808);
#39717 = MECHANICAL_DESIGN_GEOMETRIC_PRESENTATION_REPRESENTATION('',(
    #39718),#37867);
#39718 = STYLED_ITEM('color',(#39719),#37537);
#39719 = PRESENTATION_STYLE_ASSIGNMENT((#39720));
#39720 = SURFACE_STYLE_USAGE(.BOTH.,#39721);
#39721 = SURFACE_SIDE_STYLE('',(#39722));
#39722 = SURFACE_STYLE_FILL_AREA(#39723);
#39723 = FILL_AREA_STYLE('',(#39724));
#39724 = FILL_AREA_STYLE_COLOUR('',#39707);
#39725 = MECHANICAL_DESIGN_GEOMETRIC_PRESENTATION_REPRESENTATION('',(
    #39726),#19679);
#39726 = STYLED_ITEM('color',(#39727),#19497);
#39727 = PRESENTATION_STYLE_ASSIGNMENT((#39728));
#39728 = SURFACE_STYLE_USAGE(.BOTH.,#39729);
#39729 = SURFACE_SIDE_STYLE('',(#39730));
#39730 = SURFACE_STYLE_FILL_AREA(#39731);
#39731 = FILL_AREA_STYLE('',(#39732));
#39732 = FILL_AREA_STYLE_COLOUR('',#39733);
#39733 = COLOUR_RGB('',0.580000000354,0.819999987296,0.940000008746);
#39734 = MECHANICAL_DESIGN_GEOMETRIC_PRESENTATION_REPRESENTATION('',(
    #39735),#29683);
#39735 = STYLED_ITEM('color',(#39736),#28536);
#39736 = PRESENTATION_STYLE_ASSIGNMENT((#39737));
#39737 = SURFACE_STYLE_USAGE(.BOTH.,#39738);
#39738 = SURFACE_SIDE_STYLE('',(#39739));
#39739 = SURFACE_STYLE_FILL_AREA(#39740);
#39740 = FILL_AREA_STYLE('',(#39741));
#39741 = FILL_AREA_STYLE_COLOUR('',#39698);
#39742 = MECHANICAL_DESIGN_GEOMETRIC_PRESENTATION_REPRESENTATION('',(
    #39743),#20417);
#39743 = STYLED_ITEM('color',(#39744),#19899);
#39744 = PRESENTATION_STYLE_ASSIGNMENT((#39745));
#39745 = SURFACE_STYLE_USAGE(.BOTH.,#39746);
#39746 = SURFACE_SIDE_STYLE('',(#39747));
#39747 = SURFACE_STYLE_FILL_AREA(#39748);
#39748 = FILL_AREA_STYLE('',(#39749));
#39749 = FILL_AREA_STYLE_COLOUR('',#39716);
#39750 = MECHANICAL_DESIGN_GEOMETRIC_PRESENTATION_REPRESENTATION('',(
    #39751),#35942);
#39751 = STYLED_ITEM('color',(#39752),#35290);
#39752 = PRESENTATION_STYLE_ASSIGNMENT((#39753));
#39753 = SURFACE_STYLE_USAGE(.BOTH.,#39754);
#39754 = SURFACE_SIDE_STYLE('',(#39755));
#39755 = SURFACE_STYLE_FILL_AREA(#39756);
#39756 = FILL_AREA_STYLE('',(#39757));
#39757 = FILL_AREA_STYLE_COLOUR('',#39758);
#39758 = COLOUR_RGB('',0.130000001093,0.170000001676,0.199999998682);
#39759 = MECHANICAL_DESIGN_GEOMETRIC_PRESENTATION_REPRESENTATION('',(
    #39760),#19331);
#39760 = STYLED_ITEM('color',(#39761),#16175);
#39761 = PRESENTATION_STYLE_ASSIGNMENT((#39762));
#39762 = SURFACE_STYLE_USAGE(.BOTH.,#39763);
#39763 = SURFACE_SIDE_STYLE('',(#39764));
#39764 = SURFACE_STYLE_FILL_AREA(#39765);
#39765 = FILL_AREA_STYLE('',(#39766));
#39766 = FILL_AREA_STYLE_COLOUR('',#39767);
#39767 = COLOUR_RGB('',0.130000001093,0.149999997808,0.190000001765);
#39768 = MECHANICAL_DESIGN_GEOMETRIC_PRESENTATION_REPRESENTATION('',(
    #39769),#38844);
#39769 = STYLED_ITEM('color',(#39770),#37886);
#39770 = PRESENTATION_STYLE_ASSIGNMENT((#39771));
#39771 = SURFACE_STYLE_USAGE(.BOTH.,#39772);
#39772 = SURFACE_SIDE_STYLE('',(#39773));
#39773 = SURFACE_STYLE_FILL_AREA(#39774);
#39774 = FILL_AREA_STYLE('',(#39775));
#39775 = FILL_AREA_STYLE_COLOUR('',#39776);
#39776 = COLOUR_RGB('',0.120000001395,0.149999997808,0.190000001765);
#39777 = MECHANICAL_DESIGN_GEOMETRIC_PRESENTATION_REPRESENTATION('',(
    #39778),#36613);
#39778 = STYLED_ITEM('color',(#39779),#35961);
#39779 = PRESENTATION_STYLE_ASSIGNMENT((#39780));
#39780 = SURFACE_STYLE_USAGE(.BOTH.,#39781);
#39781 = SURFACE_SIDE_STYLE('',(#39782));
#39782 = SURFACE_STYLE_FILL_AREA(#39783);
#39783 = FILL_AREA_STYLE('',(#39784));
#39784 = FILL_AREA_STYLE_COLOUR('',#39785);
#39785 = COLOUR_RGB('',9.999999991362E-02,0.250000000672,0.329999997244
  );
#39786 = MECHANICAL_DESIGN_GEOMETRIC_PRESENTATION_REPRESENTATION('',(
    #39787),#32925);
#39787 = STYLED_ITEM('color',(#39788),#30407);
#39788 = PRESENTATION_STYLE_ASSIGNMENT((#39789));
#39789 = SURFACE_STYLE_USAGE(.BOTH.,#39790);
#39790 = SURFACE_SIDE_STYLE('',(#39791));
#39791 = SURFACE_STYLE_FILL_AREA(#39792);
#39792 = FILL_AREA_STYLE('',(#39793));
#39793 = FILL_AREA_STYLE_COLOUR('',#39794);
#39794 = COLOUR_RGB('',9.999999991362E-02,0.130000001093,0.170000001676
  );
#39795 = MECHANICAL_DESIGN_GEOMETRIC_PRESENTATION_REPRESENTATION('',(
    #39796),#26994);
#39796 = STYLED_ITEM('color',(#39797),#25980);
#39797 = PRESENTATION_STYLE_ASSIGNMENT((#39798));
#39798 = SURFACE_STYLE_USAGE(.BOTH.,#39799);
#39799 = SURFACE_SIDE_STYLE('',(#39800));
#39800 = SURFACE_STYLE_FILL_AREA(#39801);
#39801 = FILL_AREA_STYLE('',(#39802));
#39802 = FILL_AREA_STYLE_COLOUR('',#39803);
#39803 = COLOUR_RGB('',7.000000150072E-02,7.999999887273E-02,
  9.999999991362E-02);
#39804 = MECHANICAL_DESIGN_GEOMETRIC_PRESENTATION_REPRESENTATION('',(
    #39805),#11931);
#39805 = STYLED_ITEM('color',(#39806),#133);
#39806 = PRESENTATION_STYLE_ASSIGNMENT((#39807));
#39807 = SURFACE_STYLE_USAGE(.BOTH.,#39808);
#39808 = SURFACE_SIDE_STYLE('',(#39809));
#39809 = SURFACE_STYLE_FILL_AREA(#39810);
#39810 = FILL_AREA_STYLE('',(#39811));
#39811 = FILL_AREA_STYLE_COLOUR('',#39812);
#39812 = COLOUR_RGB('',8.999999692505E-02,0.109999998779,0.149999997808
  );
#39813 = MECHANICAL_DESIGN_GEOMETRIC_PRESENTATION_REPRESENTATION('',(
    #39814),#30388);
#39814 = STYLED_ITEM('color',(#39815),#30206);
#39815 = PRESENTATION_STYLE_ASSIGNMENT((#39816));
#39816 = SURFACE_STYLE_USAGE(.BOTH.,#39817);
#39817 = SURFACE_SIDE_STYLE('',(#39818));
#39818 = SURFACE_STYLE_FILL_AREA(#39819);
#39819 = FILL_AREA_STYLE('',(#39820));
#39820 = FILL_AREA_STYLE_COLOUR('',#39821);
#39821 = COLOUR_RGB('',0.709999997415,0.569999999601,0.950000001282);
#39822 = MECHANICAL_DESIGN_GEOMETRIC_PRESENTATION_REPRESENTATION('',(
    #39823),#19478);
#39823 = STYLED_ITEM('color',(#39824),#19350);
#39824 = PRESENTATION_STYLE_ASSIGNMENT((#39825));
#39825 = SURFACE_STYLE_USAGE(.BOTH.,#39826);
#39826 = SURFACE_SIDE_STYLE('',(#39827,#39831));
#39827 = SURFACE_STYLE_FILL_AREA(#39828);
#39828 = FILL_AREA_STYLE('',(#39829));
#39829 = FILL_AREA_STYLE_COLOUR('',#39830);
#39830 = COLOUR_RGB('',0.620000000292,0.850000012718,0.969999999008);
#39831 = SURFACE_STYLE_RENDERING_WITH_PROPERTIES(.NORMAL_SHADING.,#39830
  ,(#39832));
#39832 = SURFACE_STYLE_TRANSPARENT(0.840000003576);
#39833 = MECHANICAL_DESIGN_GEOMETRIC_PRESENTATION_REPRESENTATION('',(
    #39834),#27343);
#39834 = STYLED_ITEM('color',(#39835),#27013);
#39835 = PRESENTATION_STYLE_ASSIGNMENT((#39836));
#39836 = SURFACE_STYLE_USAGE(.BOTH.,#39837);
#39837 = SURFACE_SIDE_STYLE('',(#39838,#39842));
#39838 = SURFACE_STYLE_FILL_AREA(#39839);
#39839 = FILL_AREA_STYLE('',(#39840));
#39840 = FILL_AREA_STYLE_COLOUR('',#39841);
#39841 = COLOUR_RGB('',0.45000000386,0.760000013601,0.879999997771);
#39842 = SURFACE_STYLE_RENDERING_WITH_PROPERTIES(.NORMAL_SHADING.,#39841
  ,(#39843));
#39843 = SURFACE_STYLE_TRANSPARENT(0.59999999404);
#39844 = MECHANICAL_DESIGN_GEOMETRIC_PRESENTATION_REPRESENTATION('',(
    #39845),#30187);
#39845 = STYLED_ITEM('color',(#39846),#29702);
#39846 = PRESENTATION_STYLE_ASSIGNMENT((#39847));
#39847 = SURFACE_STYLE_USAGE(.BOTH.,#39848);
#39848 = SURFACE_SIDE_STYLE('',(#39849));
#39849 = SURFACE_STYLE_FILL_AREA(#39850);
#39850 = FILL_AREA_STYLE('',(#39851));
#39851 = FILL_AREA_STYLE_COLOUR('',#39852);
#39852 = COLOUR_RGB('',7.999999887273E-02,9.999999991362E-02,
  0.139999997847);
#39853 = MECHANICAL_DESIGN_GEOMETRIC_PRESENTATION_REPRESENTATION('',(
    #39854),#25961);
#39854 = STYLED_ITEM('color',(#39855),#20981);
#39855 = PRESENTATION_STYLE_ASSIGNMENT((#39856));
#39856 = SURFACE_STYLE_USAGE(.BOTH.,#39857);
#39857 = SURFACE_SIDE_STYLE('',(#39858));
#39858 = SURFACE_STYLE_FILL_AREA(#39859);
#39859 = FILL_AREA_STYLE('',(#39860));
#39860 = FILL_AREA_STYLE_COLOUR('',#39861);
#39861 = COLOUR_RGB('',5.500000063064E-02,6.500000082754E-02,
  7.999999887273E-02);
#39862 = MECHANICAL_DESIGN_GEOMETRIC_PRESENTATION_REPRESENTATION('',(
    #39863),#35271);
#39863 = STYLED_ITEM('color',(#39864),#34573);
#39864 = PRESENTATION_STYLE_ASSIGNMENT((#39865));
#39865 = SURFACE_STYLE_USAGE(.BOTH.,#39866);
#39866 = SURFACE_SIDE_STYLE('',(#39867));
#39867 = SURFACE_STYLE_FILL_AREA(#39868);
#39868 = FILL_AREA_STYLE('',(#39869));
#39869 = FILL_AREA_STYLE_COLOUR('',#39870);
#39870 = COLOUR_RGB('',3.999999888241E-02,0.36000000506,0.250000000672);
#39871 = MECHANICAL_DESIGN_GEOMETRIC_PRESENTATION_REPRESENTATION('',(
    #39872),#19880);
#39872 = STYLED_ITEM('color',(#39873),#19698);
#39873 = PRESENTATION_STYLE_ASSIGNMENT((#39874));
#39874 = SURFACE_STYLE_USAGE(.BOTH.,#39875);
#39875 = SURFACE_SIDE_STYLE('',(#39876));
#39876 = SURFACE_STYLE_FILL_AREA(#39877);
#39877 = FILL_AREA_STYLE('',(#39878));
#39878 = FILL_AREA_STYLE_COLOUR('',#39879);
#39879 = COLOUR_RGB('',0.180000002302,0.199999998682,0.230000002338);
#39880 = MECHANICAL_DESIGN_GEOMETRIC_PRESENTATION_REPRESENTATION('',(
    #39881),#34554);
#39881 = STYLED_ITEM('color',(#39882),#32944);
#39882 = PRESENTATION_STYLE_ASSIGNMENT((#39883));
#39883 = SURFACE_STYLE_USAGE(.BOTH.,#39884);
#39884 = SURFACE_SIDE_STYLE('',(#39885));
#39885 = SURFACE_STYLE_FILL_AREA(#39886);
#39886 = FILL_AREA_STYLE('',(#39887));
#39887 = FILL_AREA_STYLE_COLOUR('',#39794);
#39888 = MECHANICAL_DESIGN_GEOMETRIC_PRESENTATION_REPRESENTATION('',(
    #39889),#36962);
#39889 = STYLED_ITEM('color',(#39890),#36632);
#39890 = PRESENTATION_STYLE_ASSIGNMENT((#39891));
#39891 = SURFACE_STYLE_USAGE(.BOTH.,#39892);
#39892 = SURFACE_SIDE_STYLE('',(#39893));
#39893 = SURFACE_STYLE_FILL_AREA(#39894);
#39894 = FILL_AREA_STYLE('',(#39895));
#39895 = FILL_AREA_STYLE_COLOUR('',#39896);
#39896 = COLOUR_RGB('',3.499999902211E-02,6.500000082754E-02,
  0.190000001765);
#39897 = MECHANICAL_DESIGN_GEOMETRIC_PRESENTATION_REPRESENTATION('',(
    #39898),#39661);
#39898 = STYLED_ITEM('color',(#39899),#38863);
#39899 = PRESENTATION_STYLE_ASSIGNMENT((#39900));
#39900 = SURFACE_STYLE_USAGE(.BOTH.,#39901);
#39901 = SURFACE_SIDE_STYLE('',(#39902));
#39902 = SURFACE_STYLE_FILL_AREA(#39903);
#39903 = FILL_AREA_STYLE('',(#39904));
#39904 = FILL_AREA_STYLE_COLOUR('',#39707);
ENDSEC;
END-ISO-10303-21;

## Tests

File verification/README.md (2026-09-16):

# Verification provenance

These are executed software/CAD checks, not physical qualification or production authorization.

| Evidence | Tested revision | Run |
|---|---|---|
| Byte-identical 63-file Rev A import | f430900c5269cbada520c0550a1a0a9df75eb3ed | 35095459001 |
| Rev B nominal geometry and native ECAD closure | ee7636b41c1c5ce633bbcd893e3255e46b586d81 | 35102824577 |
| WebGPU/browser: 12 checks, no reported browser errors | be296449f793c9a6d6da068ecc2f755bf9f3d23c | 35122015818 |
| KiCad 9.0.9, native CAM, 3 firmware profiles, units, Docker boot | e75e8cbf9ed599b46090f04b0eb5d466797816f7 | 35122549355 |

Run 35122549355 passed all six jobs: unit tests, KiCad, container and firmware default/public-voice/calibration. Run 35122015818 uses the actual production CSP and a software WebGPU adapter. OpenAI text, STT and TTS are mocked; no live API key was used. Hardware FPS, physical optics, Safari/iPhone behavior and production security are not established.

Earlier browser verification incorrectly allowed a failed process behind `tee` to leave a green job. The pipeline was corrected to use explicit Bash/pipefail, required report/screenshot outputs, and report generation on failure. Do not use run 35119366382 as browser-pass evidence. Later failures led to software-adapter selection and a bounded one-frame GPU submission queue; these checks now pass.

An earlier KiCad job unexpectedly ran KiCad 7 despite a PPA installation. The current job uses `kicad/kicad:9.0.9`, verifies the version and fails rather than silently relaxing CLI or DRC requirements.

`archived/2026-09-16-native/` contains outputs downloaded from run 35122549355. `preview/validated/` contains screenshots and the report from run 35122015818. Each keeps its own tested commit. Do not treat archived reports as evidence for changed design sources without review.

The handoff workflow re-runs Python/JavaScript tests when generating documentation. Source fingerprints and SHA-256 manifests bind the generated files and release records to their inputs. Blank first-article records are deliberately NOT TESTED.

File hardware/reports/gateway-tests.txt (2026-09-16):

.....................                                                    [100%]
21 passed in 0.34s

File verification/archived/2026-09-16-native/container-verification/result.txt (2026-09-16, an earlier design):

PASS: read-only root; UID 10001; SQLite volume; web assets; no paid API calls.

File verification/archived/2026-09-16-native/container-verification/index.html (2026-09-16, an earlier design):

☾CRYSTALBALLAETHER ORB · DIGITAL STUDIO

Demo / offlineConnect gateway ↗

EXPERIENCE / 01

# A little mystery. A new perspective.

TellerClientCompare

✧

AETHER

DRAG TO ORBIT · SCROLL TO ZOOM · DOUBLE-CLICK TO RESET

↺Ⅱ⛶Initializing renderer

THE ORB IS QUIET

AI-ASSISTED ENTERTAINMENT · THE GLOW IS A DIGITAL VISUAL EFFECT

YOUR PRIVATE READING01 / AETHER

## What is on your mind?

A question, a possibility, a moment of curiosity. The crystal holds a fictional reflection — the choices remain yours.

DemoOpenAI gateway

Your question

0 / 2000⌘ ↵

Consult the orb✧

● Hold to askLive voiceCancel

Microphone off. Demo uses written sample reflections; live voice requires a connected gateway.

A MOMENT OF STILLNESS

Your reflection will appear here and inside the teller’s view of the crystal.

←—→Listen ♪Erase

Atmosphere +

Halo intensity 75%Illustrated nebula Artistic effect, not a hardware simulationOpen a glow-only client window ↗

Openly AI-assisted entertainment. No supernatural claims or factual predictions. Spoken responses use an AI-generated voice. Readings clear after 90 seconds.

ENGINEERING / REV B1 : 1 GEOMETRY

## Behind the illusion.

The exact CAD tessellation, in millimetres. Purchased electronics are envelope proxies, not vendor-qualified models.

120mmPMMA globe

55°Mirror angle

148mmBase diameter

172mmOverall height

Exploded assembly 0%

Isolate selectedShow all

Select a component to highlight it. Uncheck to hide.

ENGINEERING VALIDATION BUILD

Digital checks do not qualify optical privacy, component fit, thermal safety, EMC or production readiness. Manufacturing release remains gated.

CRYSTALBALLCRAFTED BETWEEN LIGHT & CODE

×PRIVATE BY DESIGN

## Connect your gateway.

The OpenAI project key belongs on your server, never in this browser or in a public repository. Run the configuration assistant from the repository:

python factory/configure_gateway.py
cd gateway
docker compose up --build

Paste the generated device token below. It is kept only in this tab’s memory and forgotten when the tab closes. Voice and questions are sent to your gateway and OpenAI only after you ask.

Gateway originDevice token Not an OpenAI API key

Forget credentialsConnect securely ↗

For production, deploy behind trusted HTTPS. Localhost HTTP is for local development only. Realtime voice is an opt-in development feature; the 90-second hangup timer is not a guaranteed spending cap.

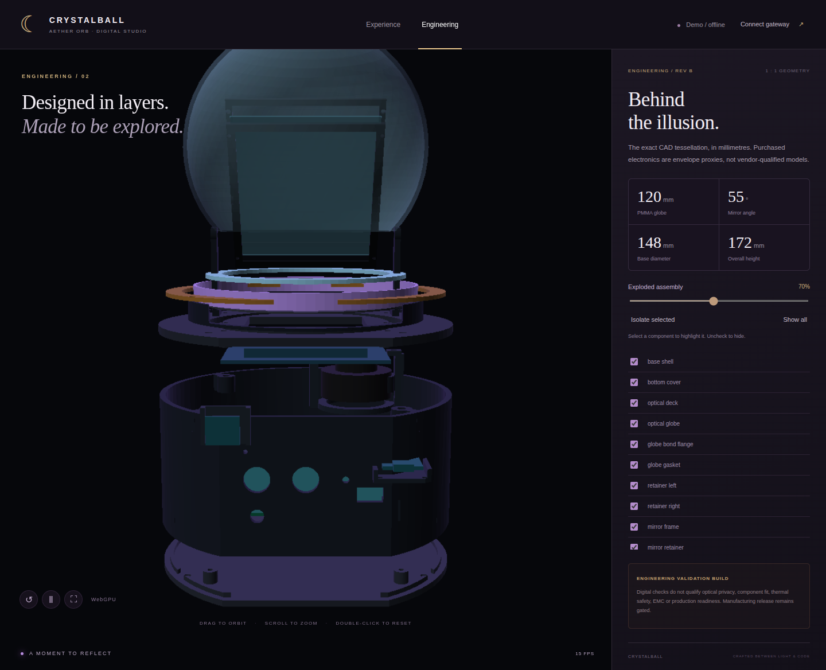
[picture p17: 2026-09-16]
verification/browser/04-cad-exploded.png

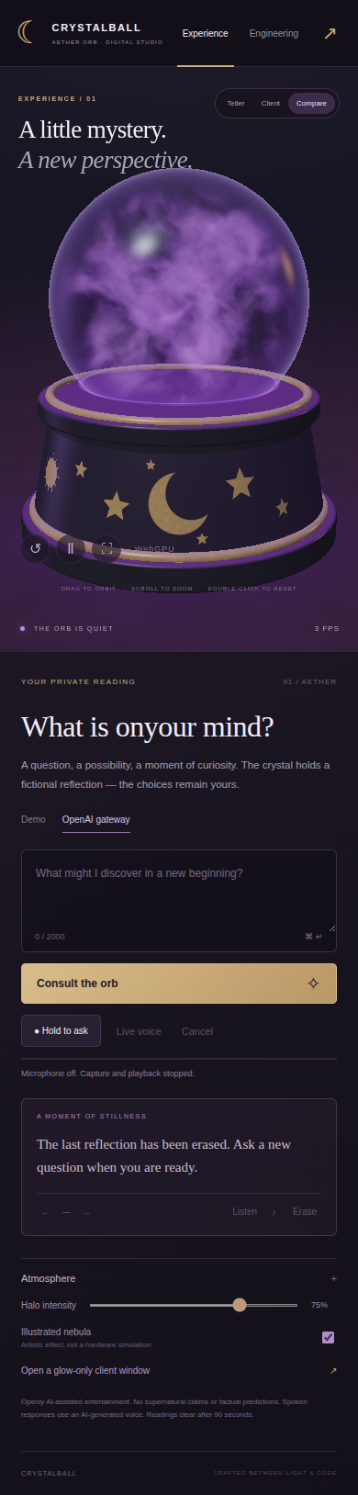
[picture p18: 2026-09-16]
verification/browser/05-mobile.png

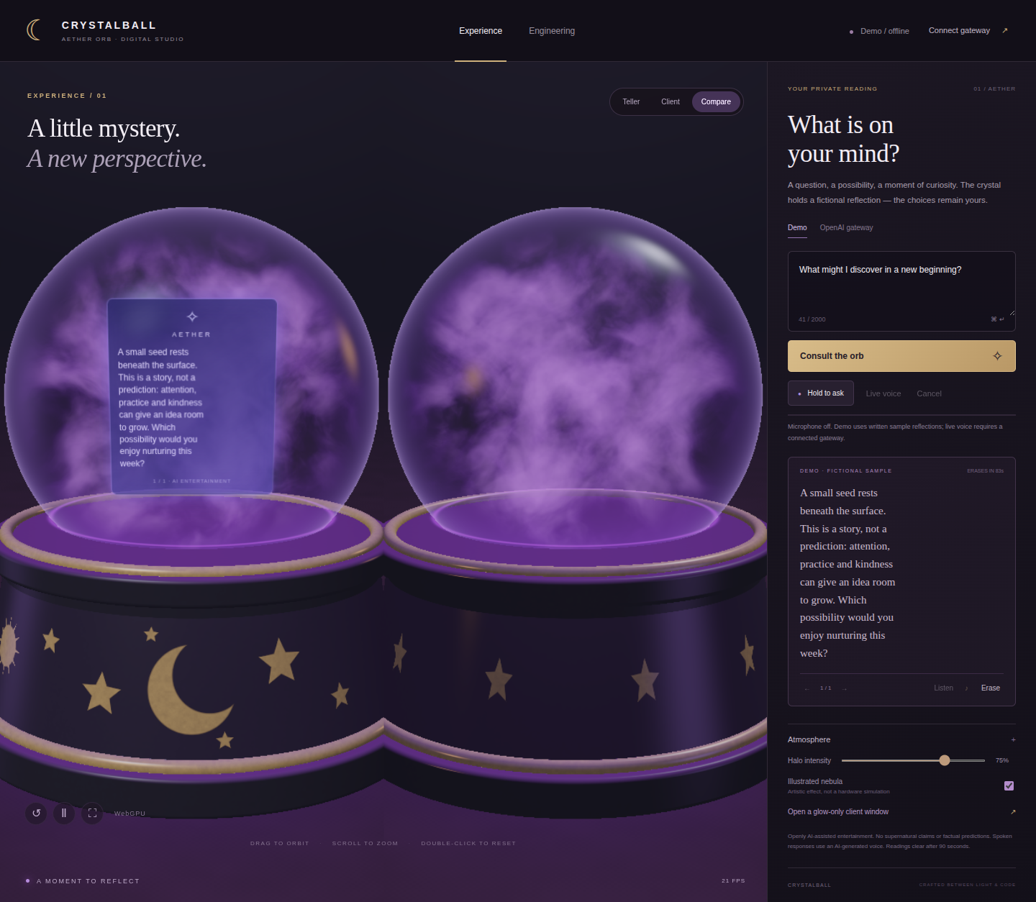
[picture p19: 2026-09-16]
verification/browser/03-compare.png

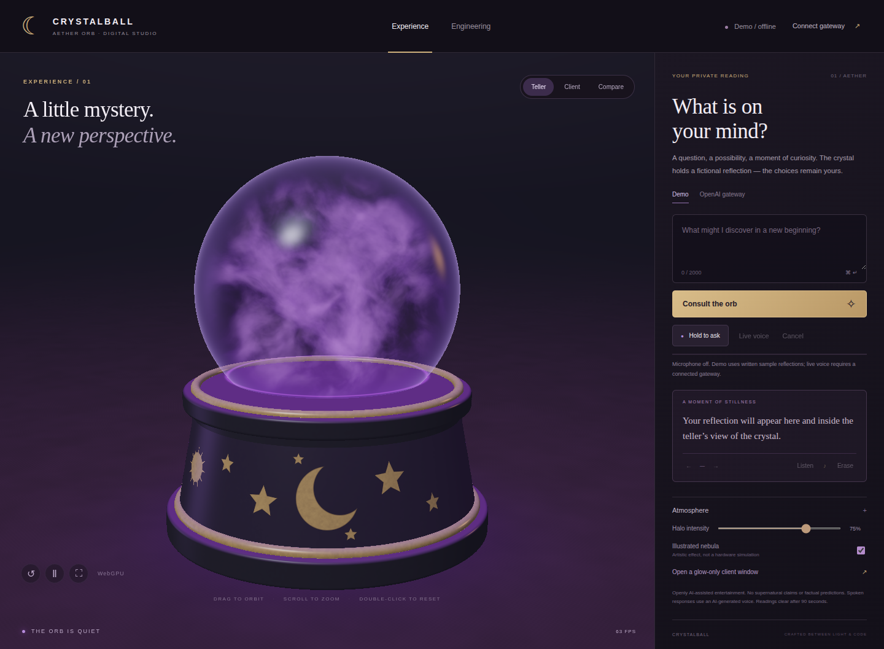
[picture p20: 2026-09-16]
verification/browser/01-studio.png

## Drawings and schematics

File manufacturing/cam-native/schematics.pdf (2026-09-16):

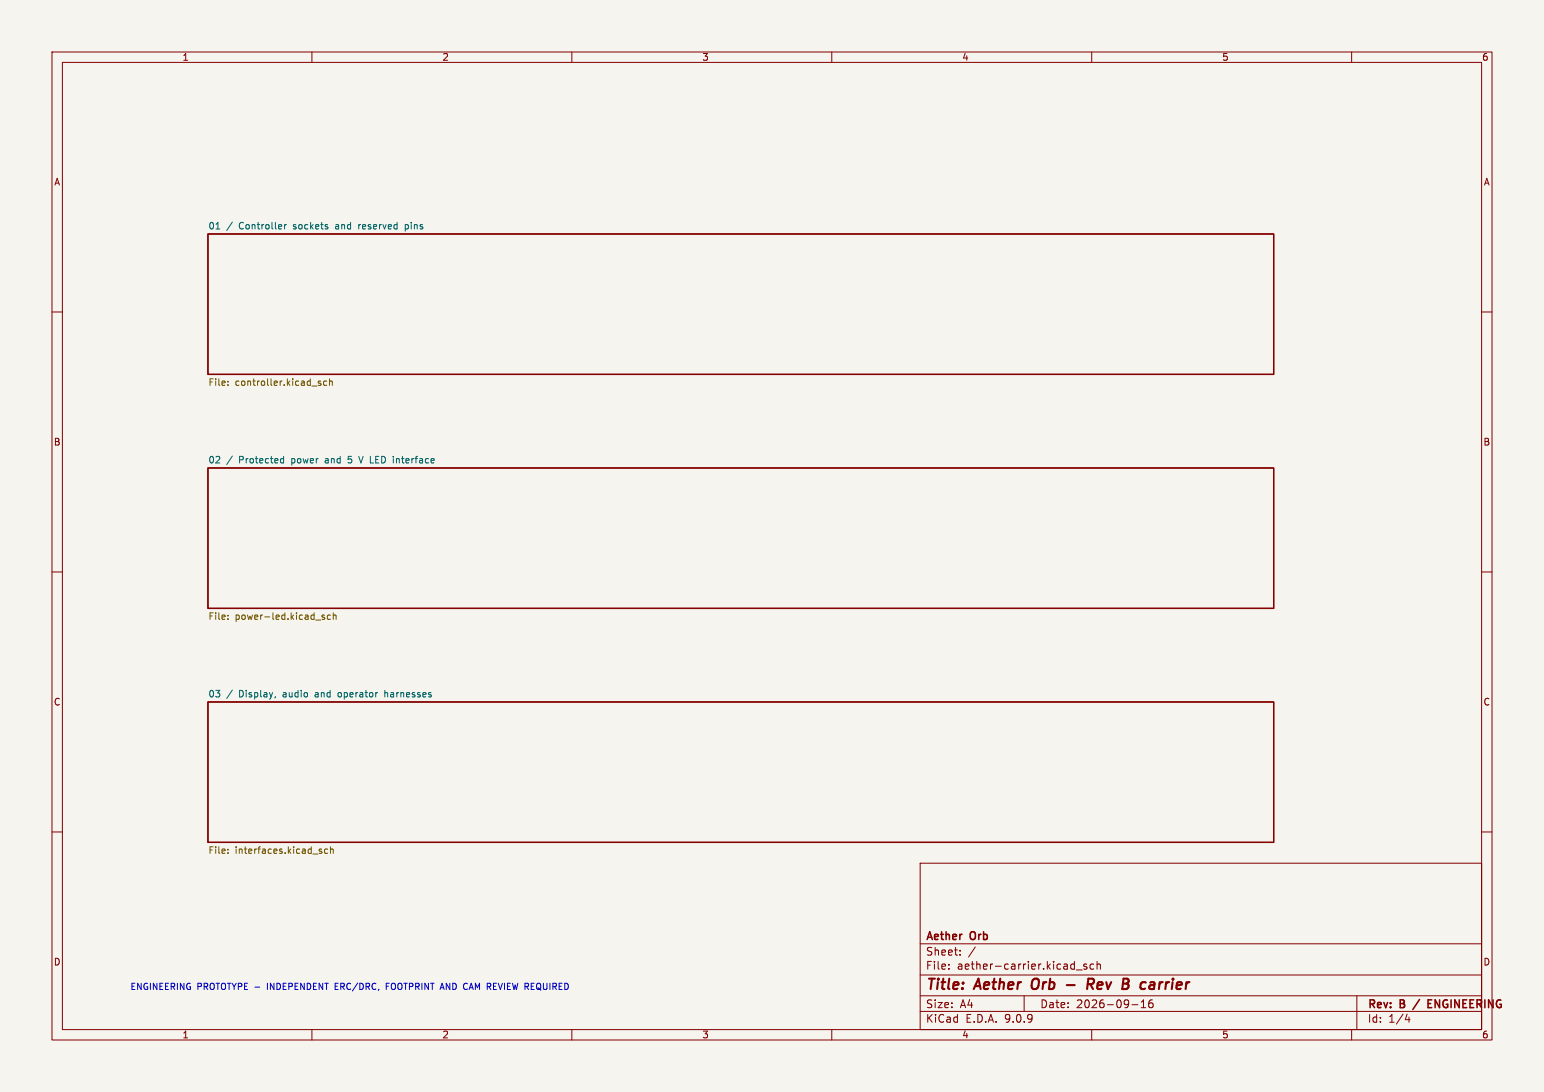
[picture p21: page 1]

Id: 1/4 Title: Aether Orb - Rev B carrier File: aether-carrier.kicad_sch Sheet: / Aether Orb

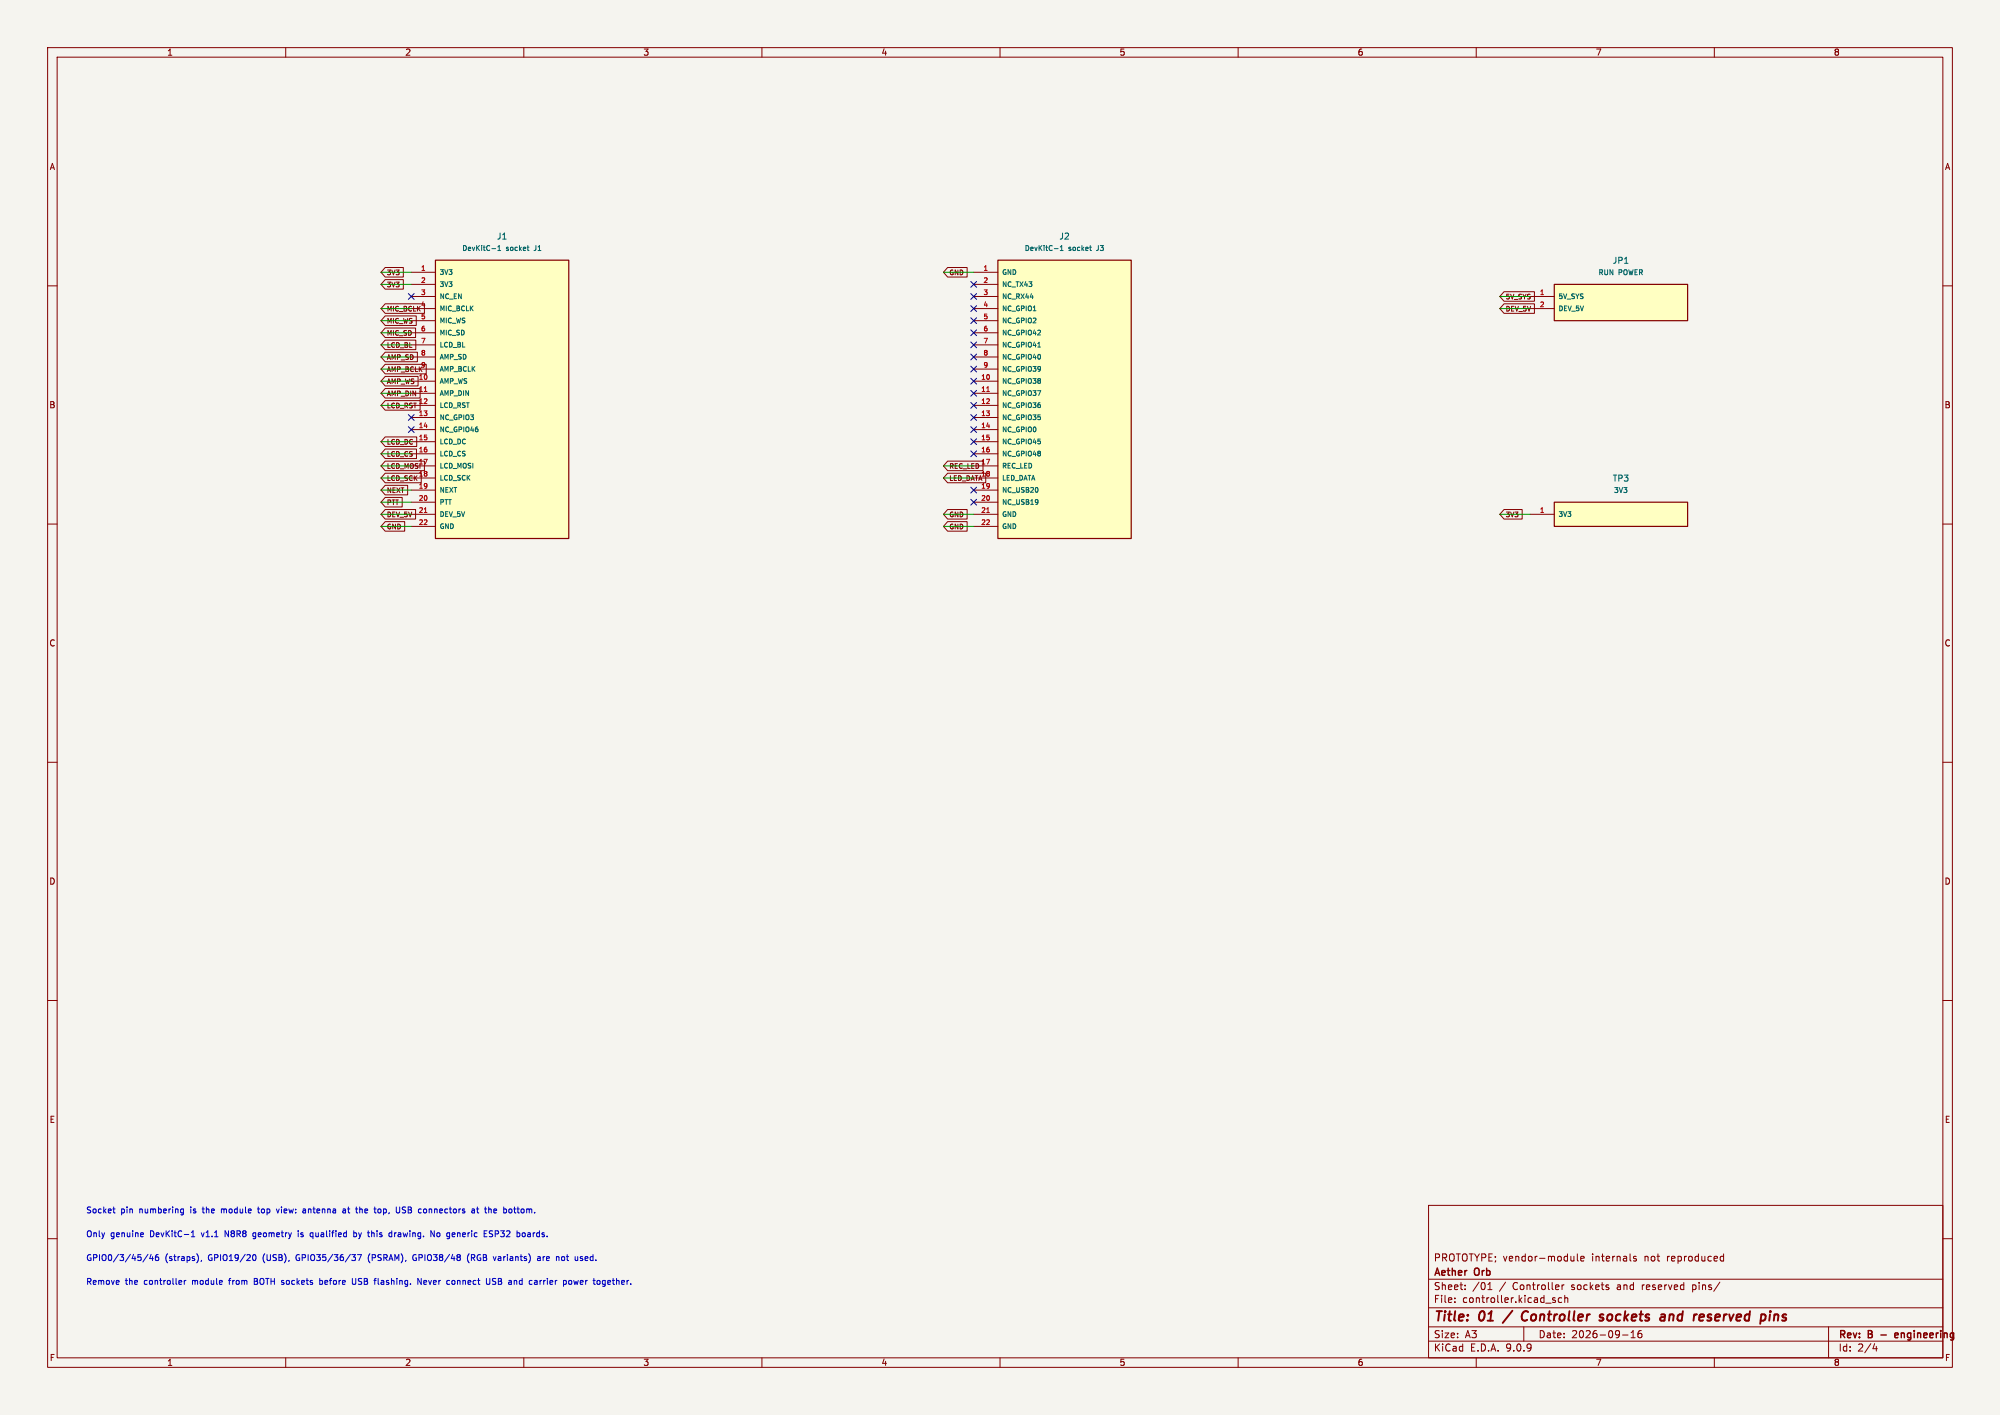
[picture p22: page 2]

Id: 2/4 Title: 01 / Controller sockets and reserved pins

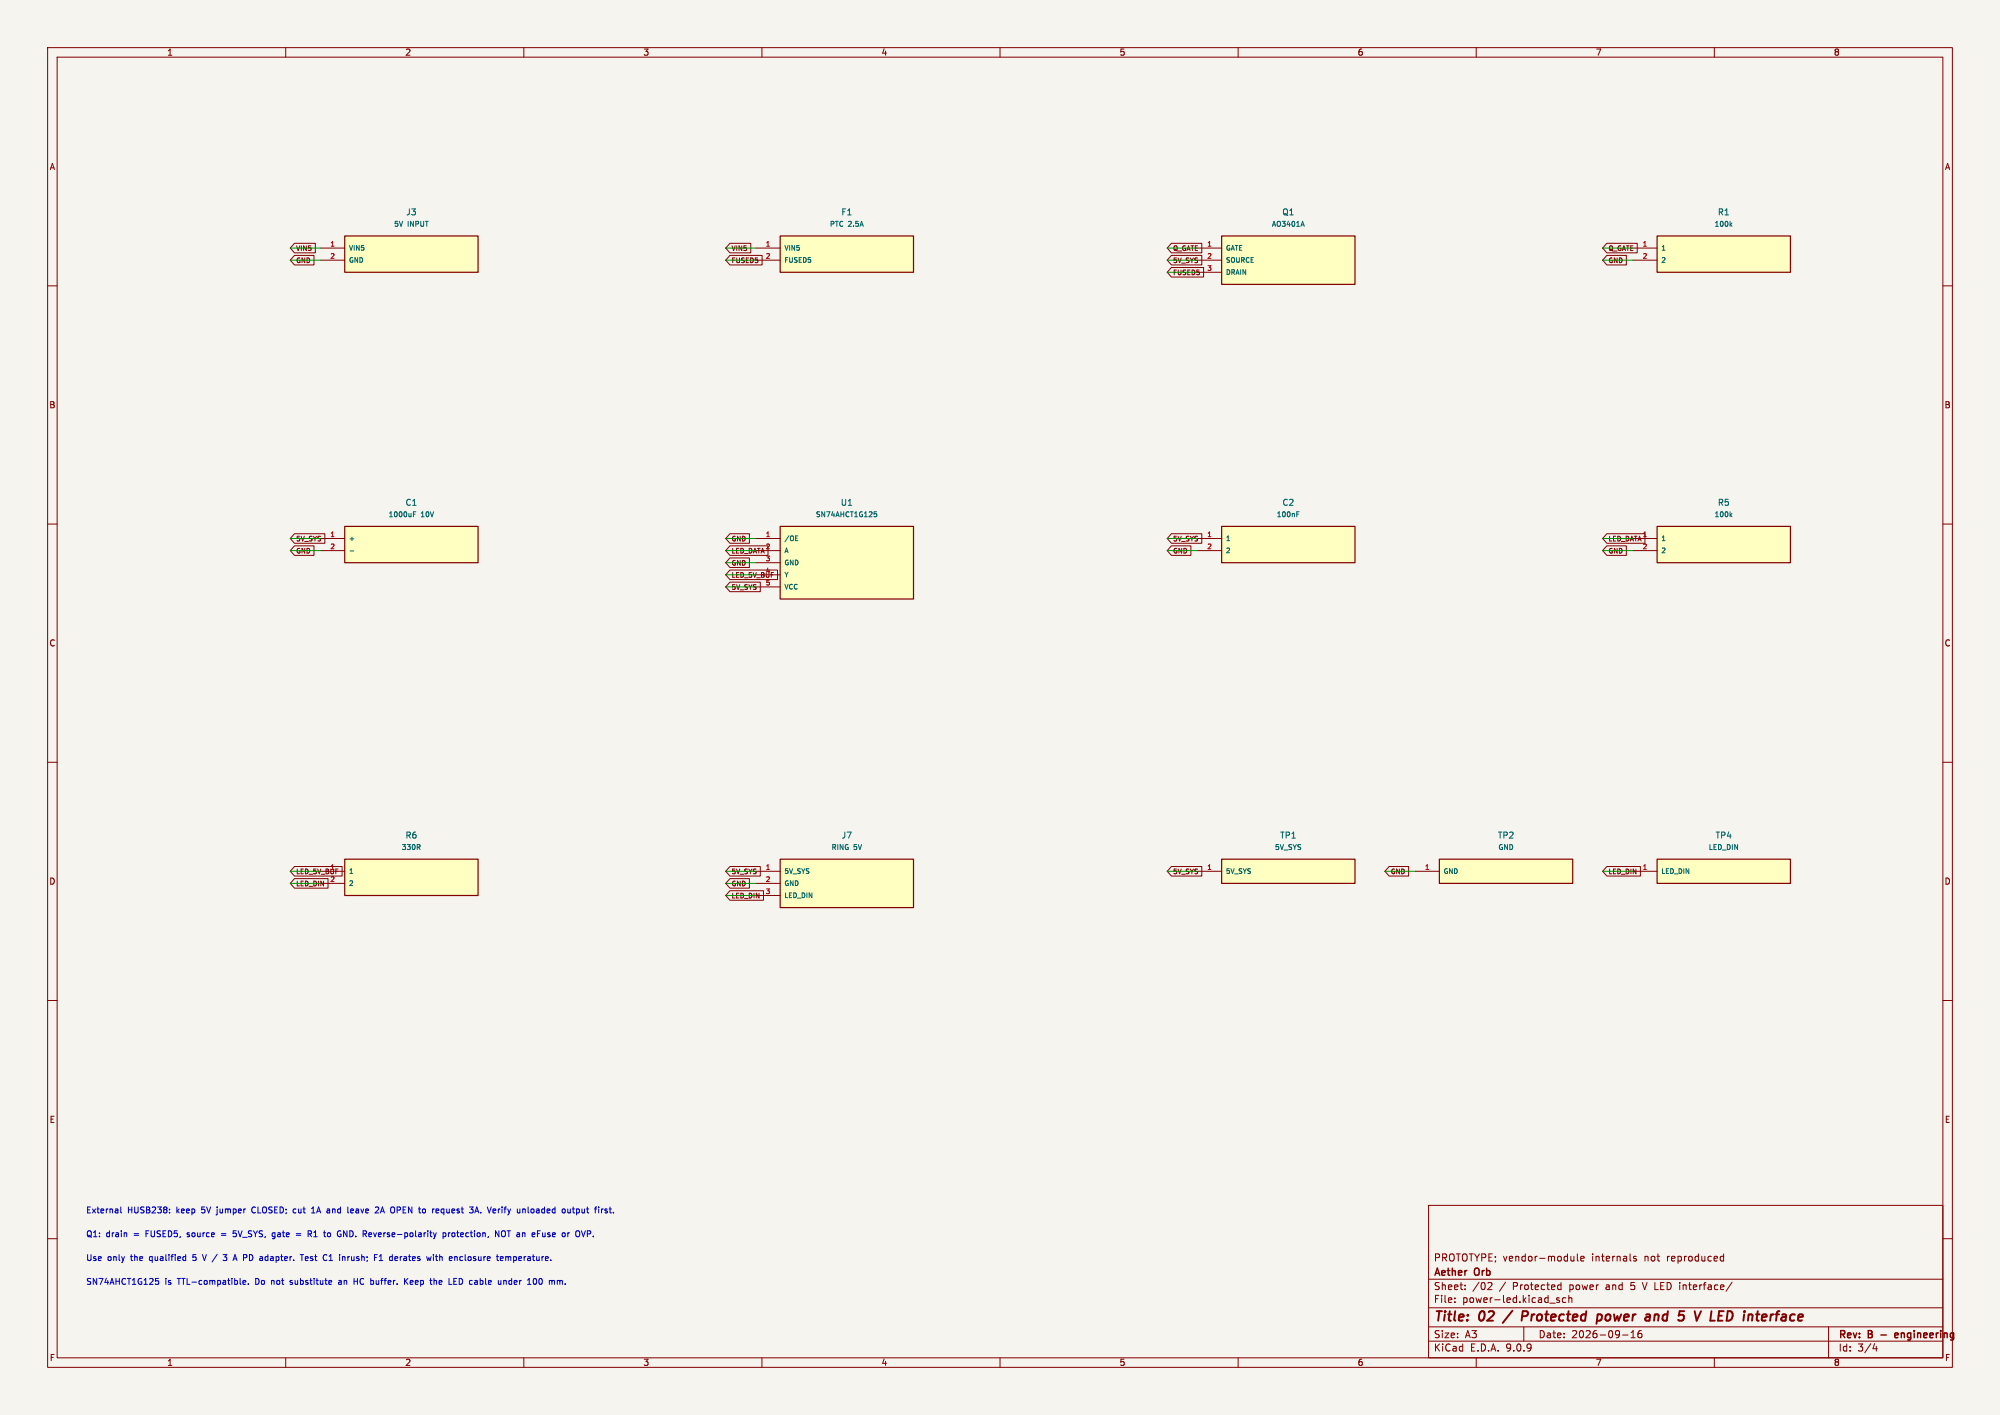
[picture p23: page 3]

Id: 3/4 Title: 02 / Protected power and 5 V LED interface

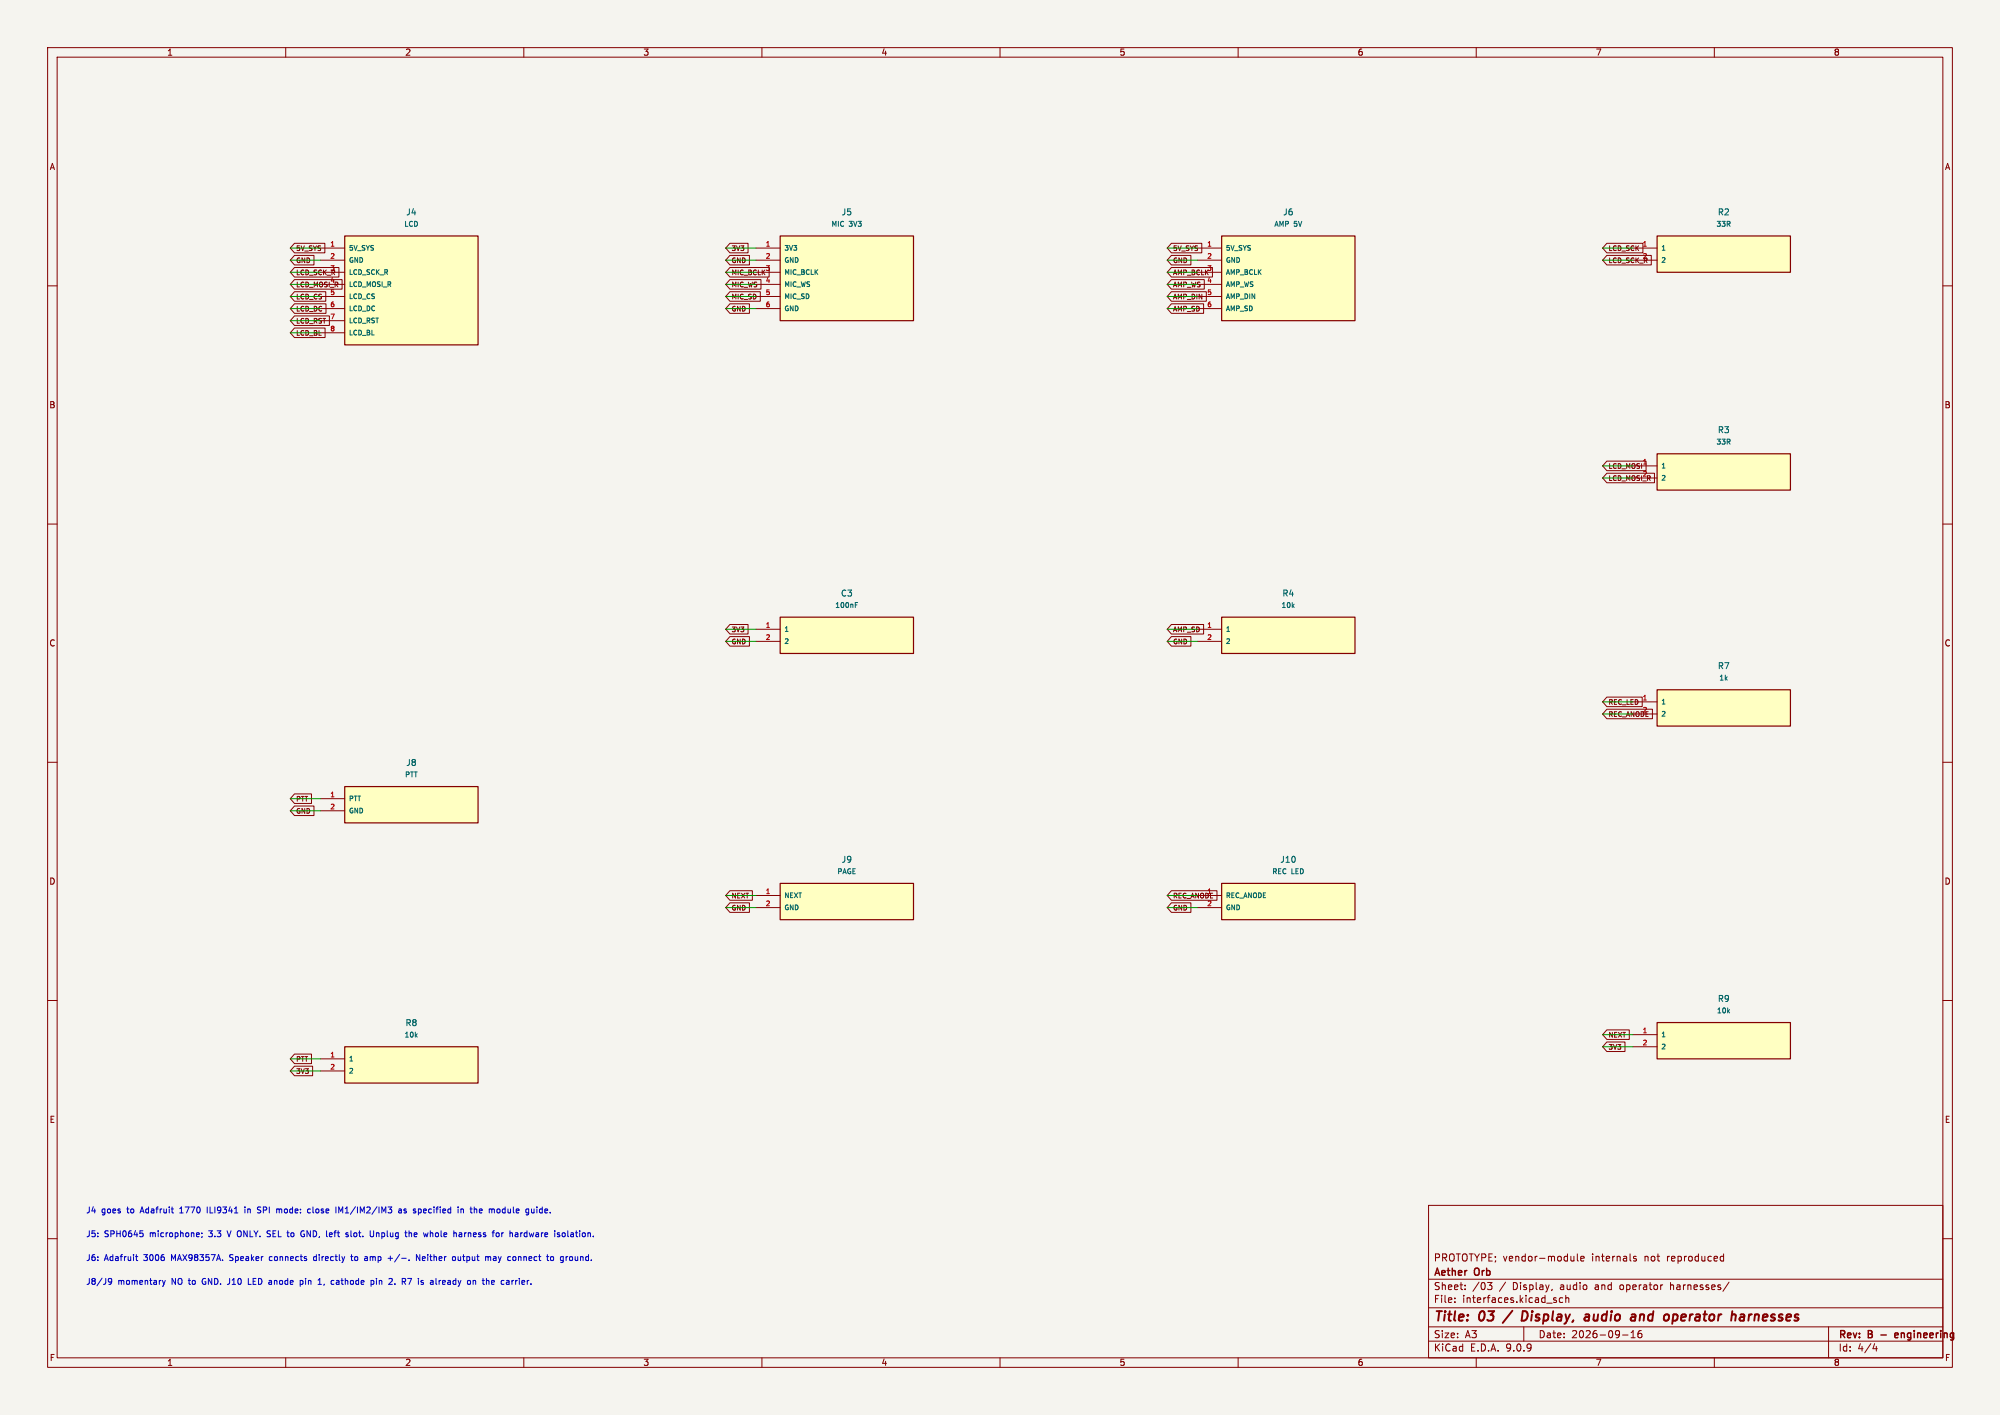
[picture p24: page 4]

Id: 4/4 Title: 03 / Display, audio and operator harnesses

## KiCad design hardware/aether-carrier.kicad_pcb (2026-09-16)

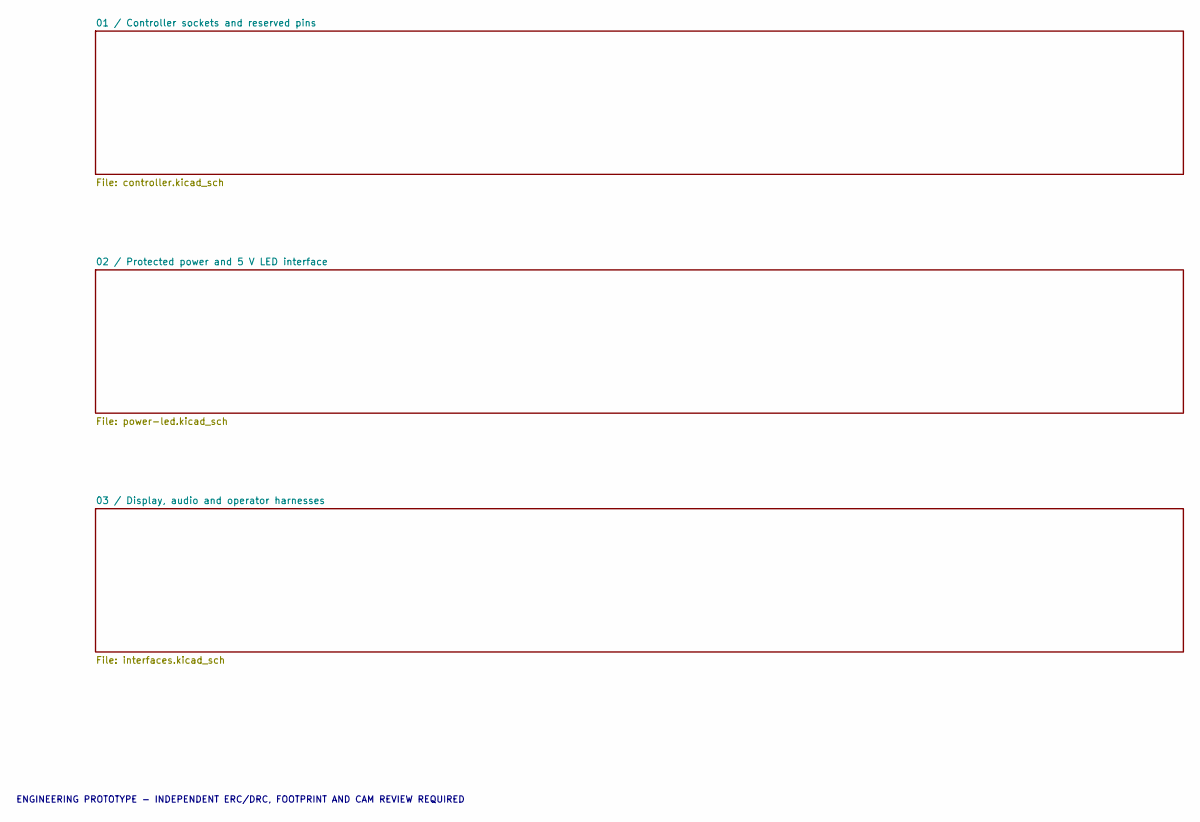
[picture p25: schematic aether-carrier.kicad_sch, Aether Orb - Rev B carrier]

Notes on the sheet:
ENGINEERING PROTOTYPE - INDEPENDENT ERC/DRC, FOOTPRINT AND CAM REVIEW REQUIRED

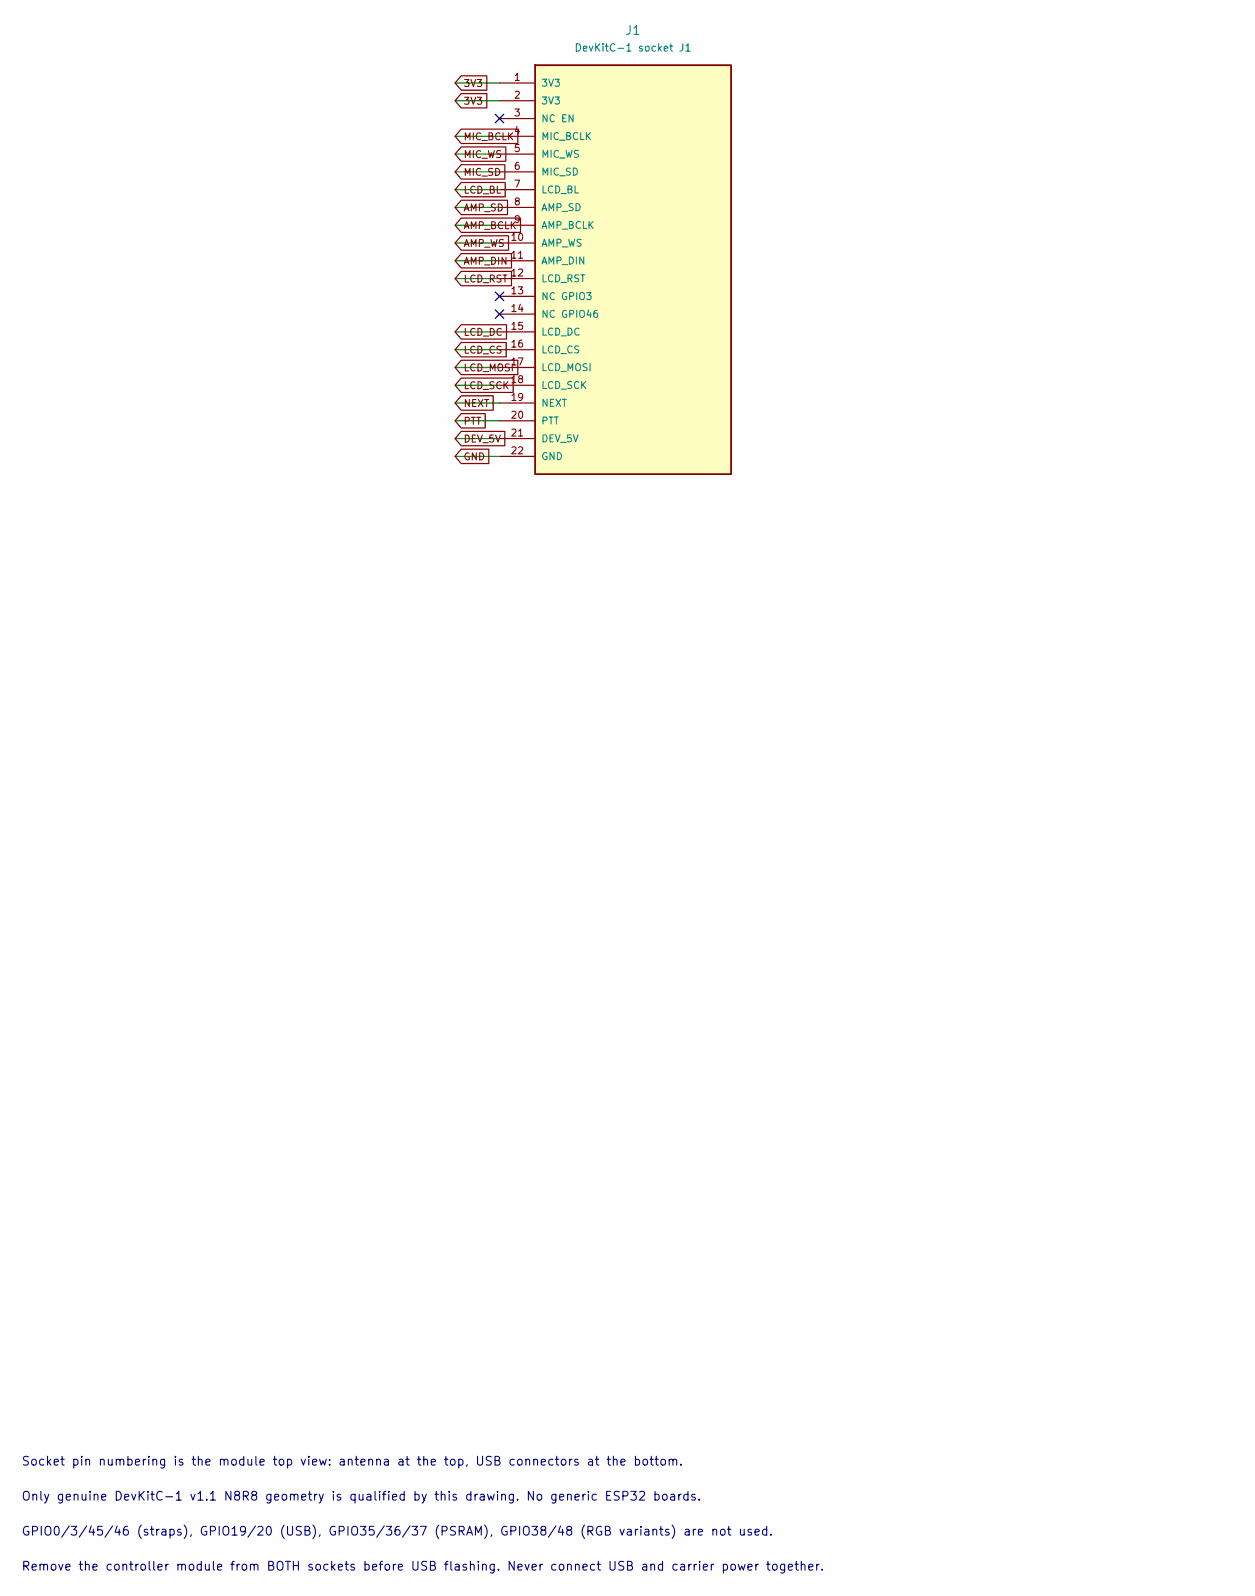
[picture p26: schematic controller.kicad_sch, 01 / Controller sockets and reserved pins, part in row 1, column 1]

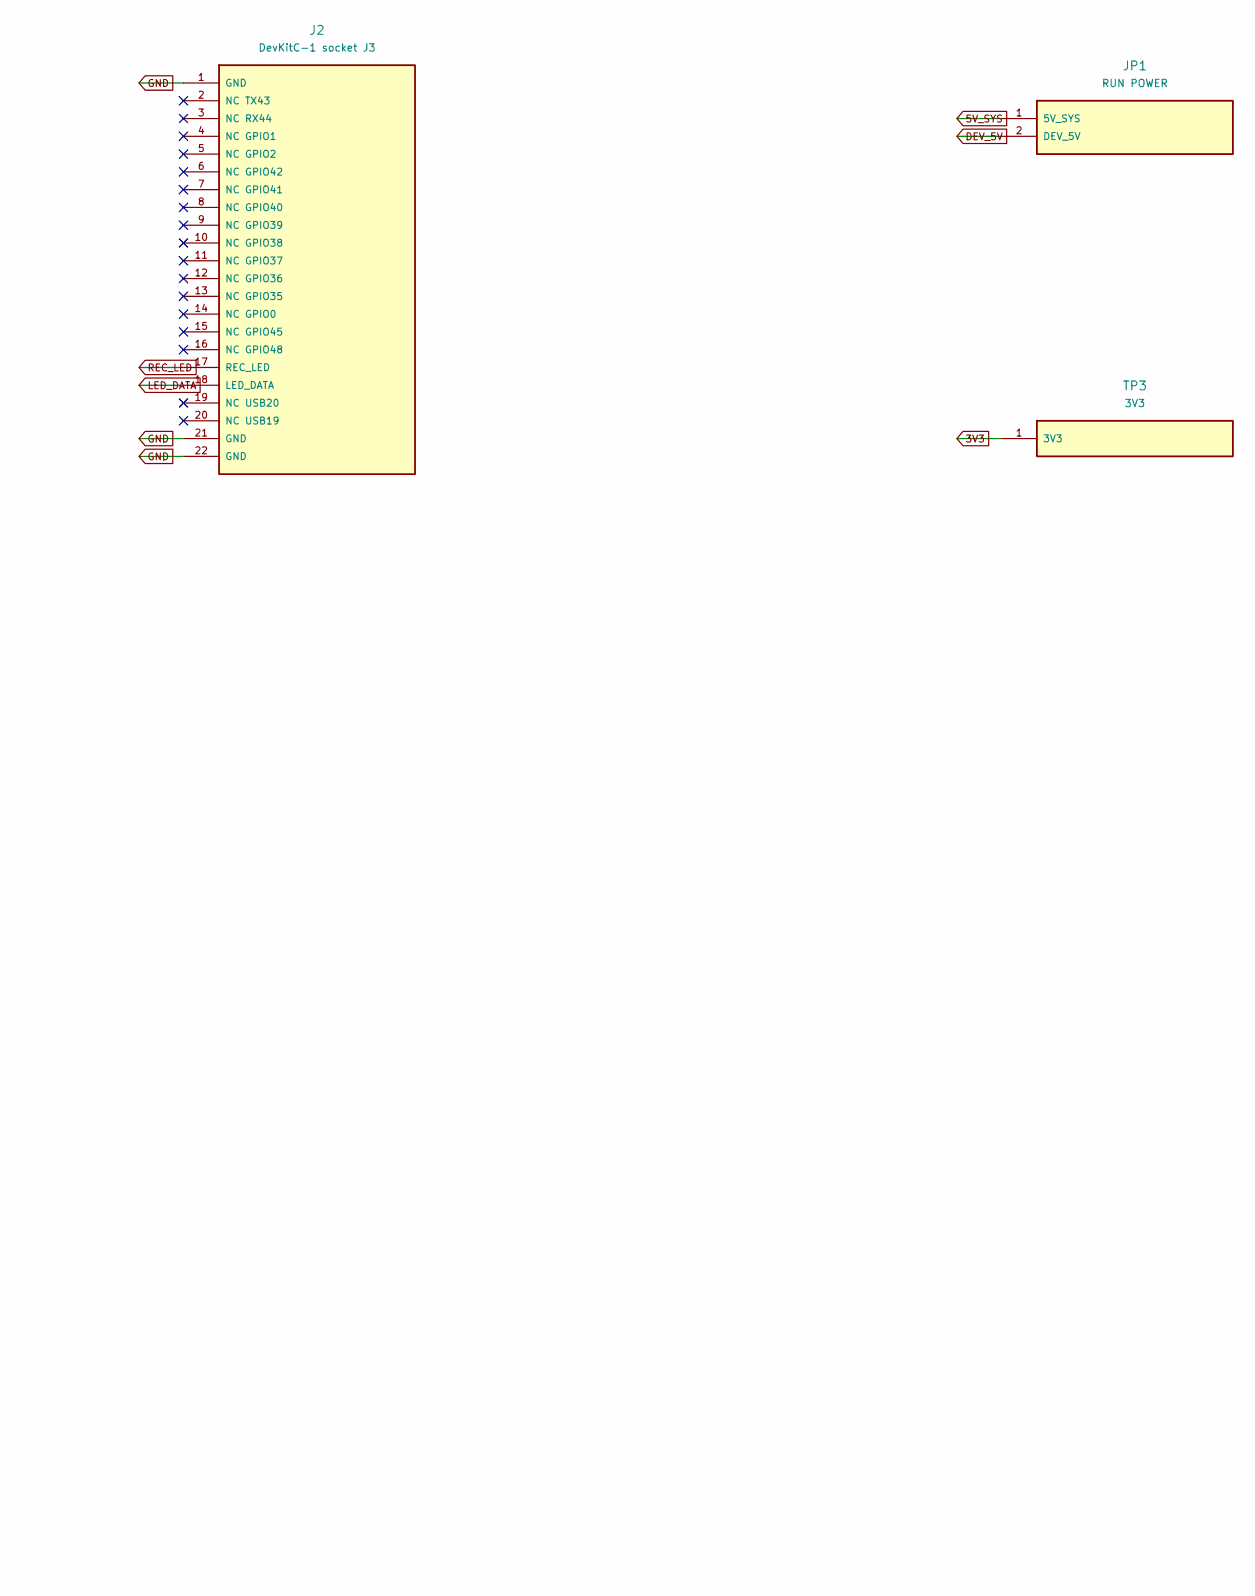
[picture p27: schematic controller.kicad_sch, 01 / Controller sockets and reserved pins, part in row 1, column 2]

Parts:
J1: DevKitC-1 socket J1; Socket_1x22_P2.54_J1
J2: DevKitC-1 socket J3; Socket_1x22_P2.54_J2
JP1: RUN POWER; PinHeader_1x02_P2.54_JP1
TP3: 3V3; TestPoint_THT_D2_TP3

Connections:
3V3: J1.1 (3V3), J1.2 (3V3), TP3.1; also elsewhere on the board
5V_SYS: JP1.1 (5V_SYS); also elsewhere on the board
AMP_BCLK: J1.9 (AMP_BCLK); also elsewhere on the board
AMP_DIN: J1.11 (AMP_DIN); also elsewhere on the board
AMP_SD: J1.8 (AMP_SD); also elsewhere on the board
AMP_WS: J1.10 (AMP_WS); also elsewhere on the board
DEV_5V: J1.21 (DEV_5V), JP1.2 (DEV_5V)
GND: J1.22 (GND), J2.1 (GND), J2.21 (GND), J2.22 (GND); also elsewhere on the board
LCD_BL: J1.7 (LCD_BL); also elsewhere on the board
LCD_CS: J1.16 (LCD_CS); also elsewhere on the board
LCD_DC: J1.15 (LCD_DC); also elsewhere on the board
LCD_MOSI: J1.17 (LCD_MOSI); also elsewhere on the board
LCD_RST: J1.12 (LCD_RST); also elsewhere on the board
LCD_SCK: J1.18 (LCD_SCK); also elsewhere on the board
LED_DATA: J2.18 (LED_DATA); also elsewhere on the board
MIC_BCLK: J1.4 (MIC_BCLK); also elsewhere on the board
MIC_SD: J1.6 (MIC_SD); also elsewhere on the board
MIC_WS: J1.5 (MIC_WS); also elsewhere on the board
NEXT: J1.19 (NEXT); also elsewhere on the board
PTT: J1.20 (PTT); also elsewhere on the board
REC_LED: J2.17 (REC_LED); also elsewhere on the board

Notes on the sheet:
Socket pin numbering is the module top view: antenna at the top, USB connectors at the bottom.
Only genuine DevKitC-1 v1.1 N8R8 geometry is qualified by this drawing. No generic ESP32 boards.
GPIO0/3/45/46 (straps), GPIO19/20 (USB), GPIO35/36/37 (PSRAM), GPIO38/48 (RGB variants) are not used.
Remove the controller module from BOTH sockets before USB flashing. Never connect USB and carrier power together.

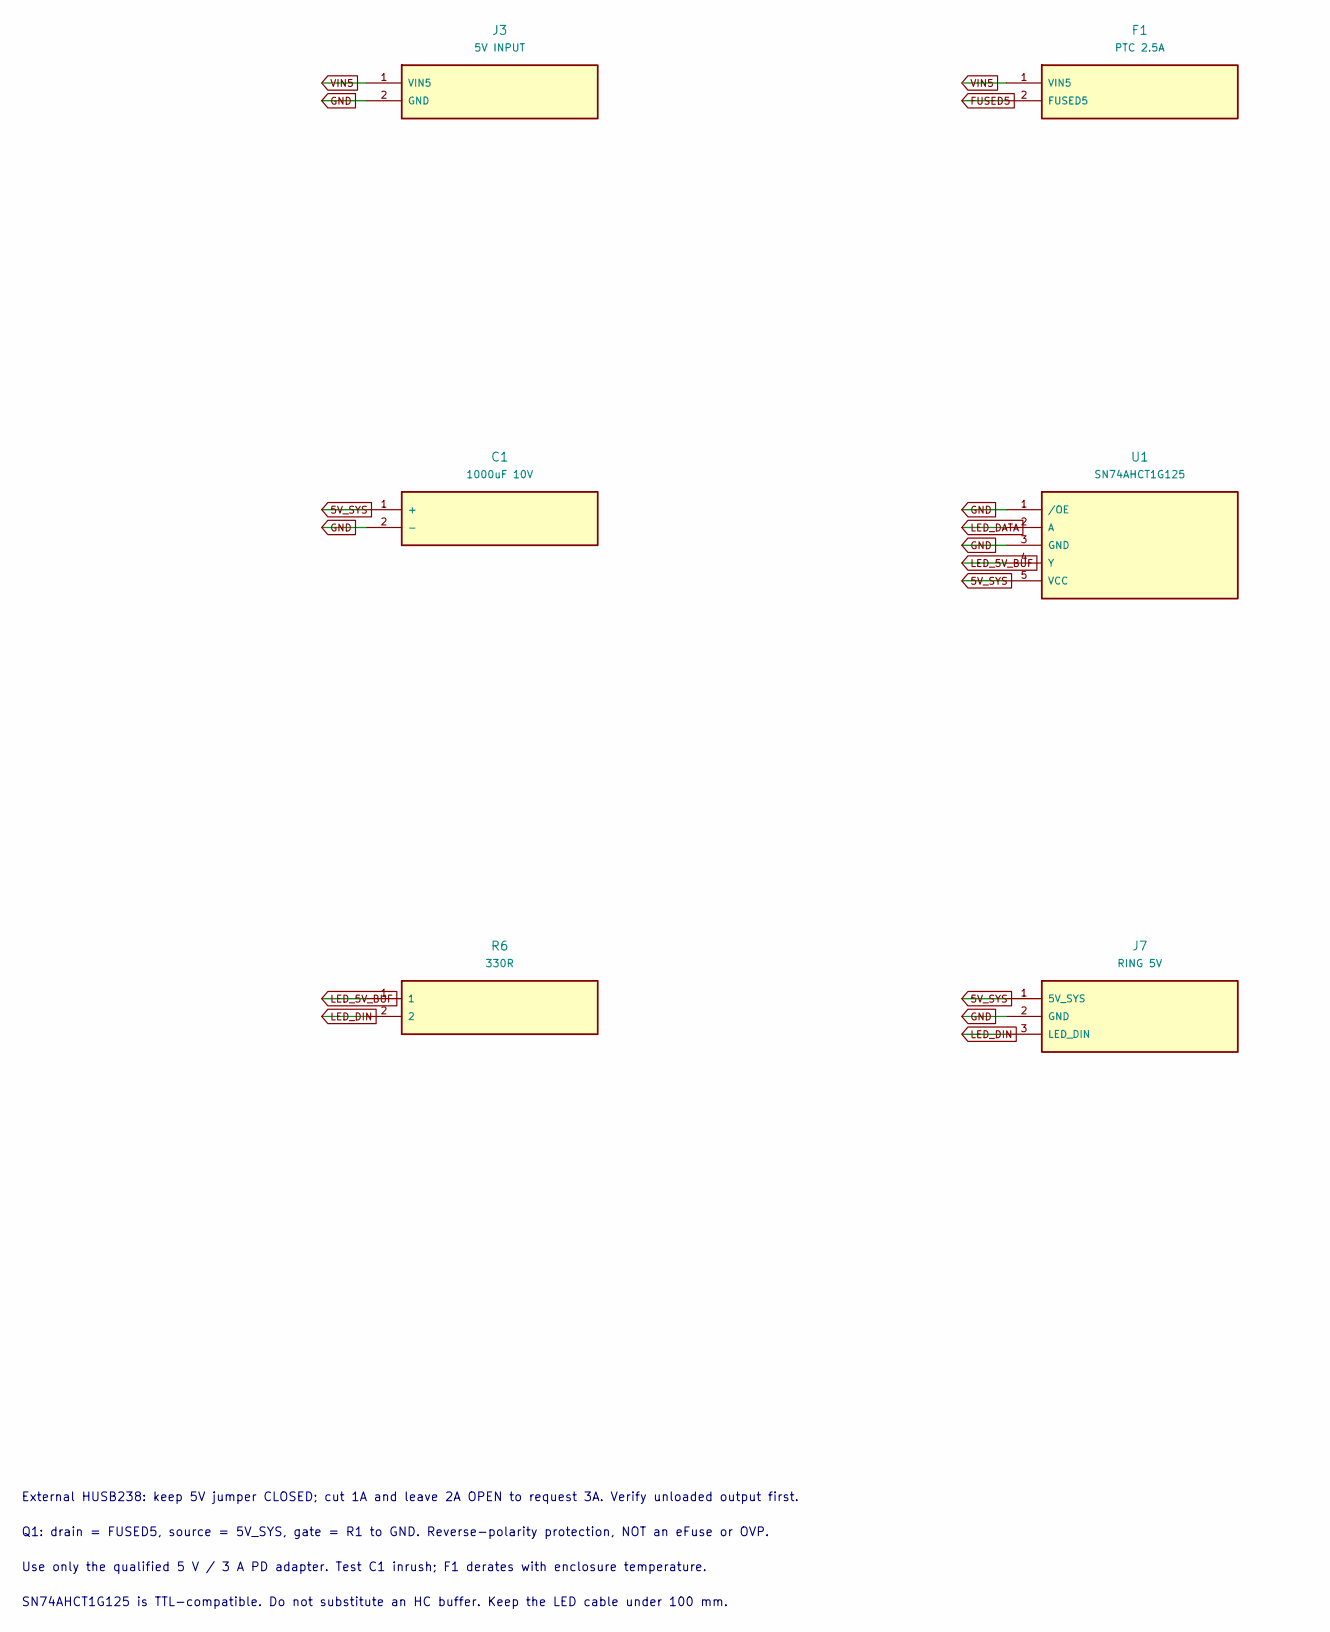
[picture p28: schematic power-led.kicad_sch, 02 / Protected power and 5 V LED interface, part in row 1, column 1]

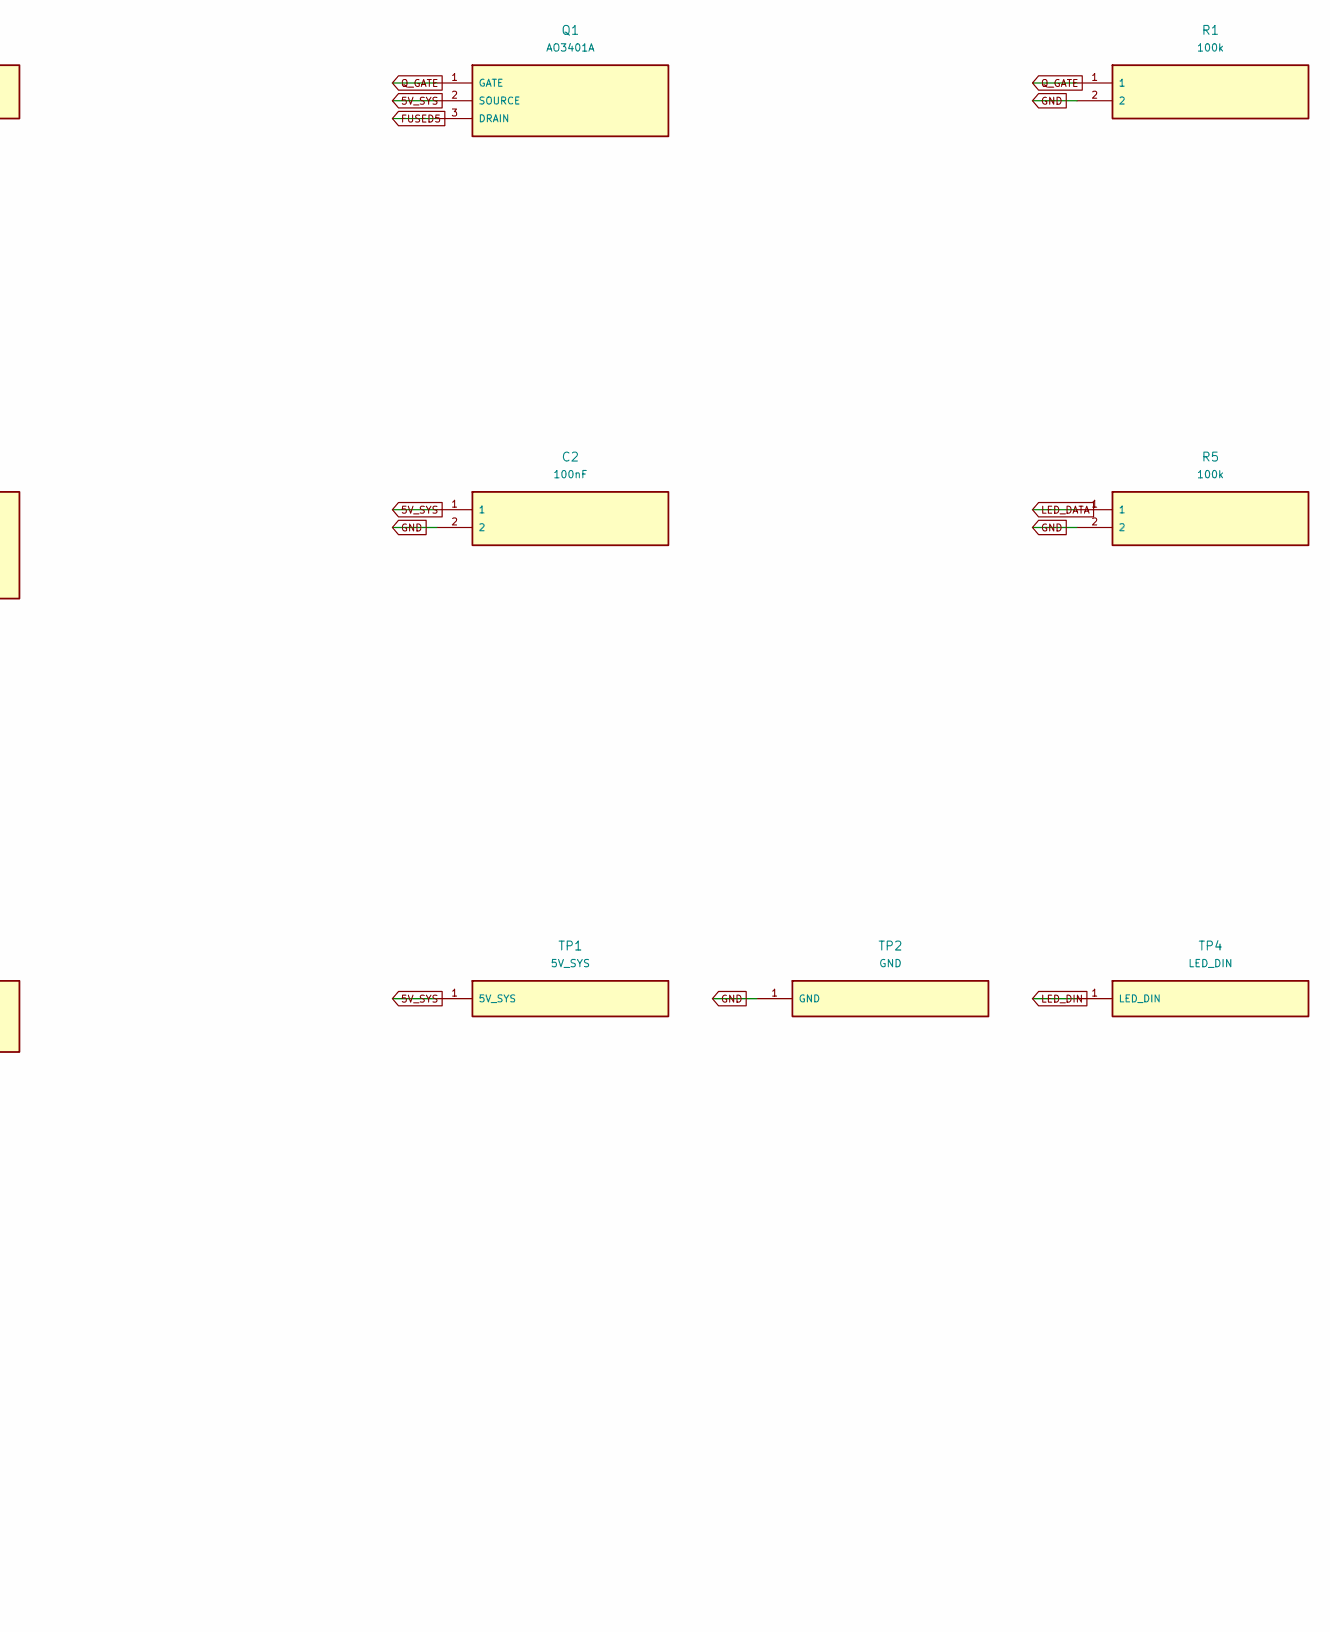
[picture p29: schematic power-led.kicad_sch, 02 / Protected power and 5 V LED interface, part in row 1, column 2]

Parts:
C1: 1000uF 10V; CP_Radial_D10_P5_C1
C2: 100nF; C_0805_2012Metric_C2
F1: PTC 2.5A; PTC_P5.08_F1
J3: 5V INPUT; Terminal_1x02_P5.08_J3
J7: RING 5V; XH_1x03_P2.50_J7
Q1: AO3401A; SOT-23_Q1
R1: 100k; R_0805_2012Metric_R1
R5: 100k; R_0805_2012Metric_R5
R6: 330R; R_0805_2012Metric_R6
TP1: 5V_SYS; TestPoint_THT_D2_TP1
TP2: GND; TestPoint_THT_D2_TP2
TP4: LED_DIN; TestPoint_THT_D2_TP4
U1: SN74AHCT1G125; SOT-23-5_U1

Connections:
5V_SYS: C1.1 (+), C2.1, J7.1 (5V_SYS), Q1.2 (SOURCE), TP1.1, U1.5 (VCC); also elsewhere on the board
FUSED5: F1.2 (FUSED5), Q1.3 (DRAIN)
GND: C1.2 (-), C2.2, J3.2 (GND), J7.2 (GND), R1.2, R5.2, TP2.1, U1.1 (/OE), U1.3 (GND); also elsewhere on the board
LED_5V_BUF: R6.1, U1.4 (Y)
LED_DATA: R5.1, U1.2 (A); also elsewhere on the board
LED_DIN: J7.3 (LED_DIN), R6.2, TP4.1
Q_GATE: Q1.1 (GATE), R1.1
VIN5: F1.1 (VIN5), J3.1 (VIN5)

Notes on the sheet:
External HUSB238: keep 5V jumper CLOSED; cut 1A and leave 2A OPEN to request 3A. Verify unloaded output first.
Q1: drain = FUSED5, source = 5V_SYS, gate = R1 to GND. Reverse-polarity protection, NOT an eFuse or OVP.
Use only the qualified 5 V / 3 A PD adapter. Test C1 inrush; F1 derates with enclosure temperature.
SN74AHCT1G125 is TTL-compatible. Do not substitute an HC buffer. Keep the LED cable under 100 mm.

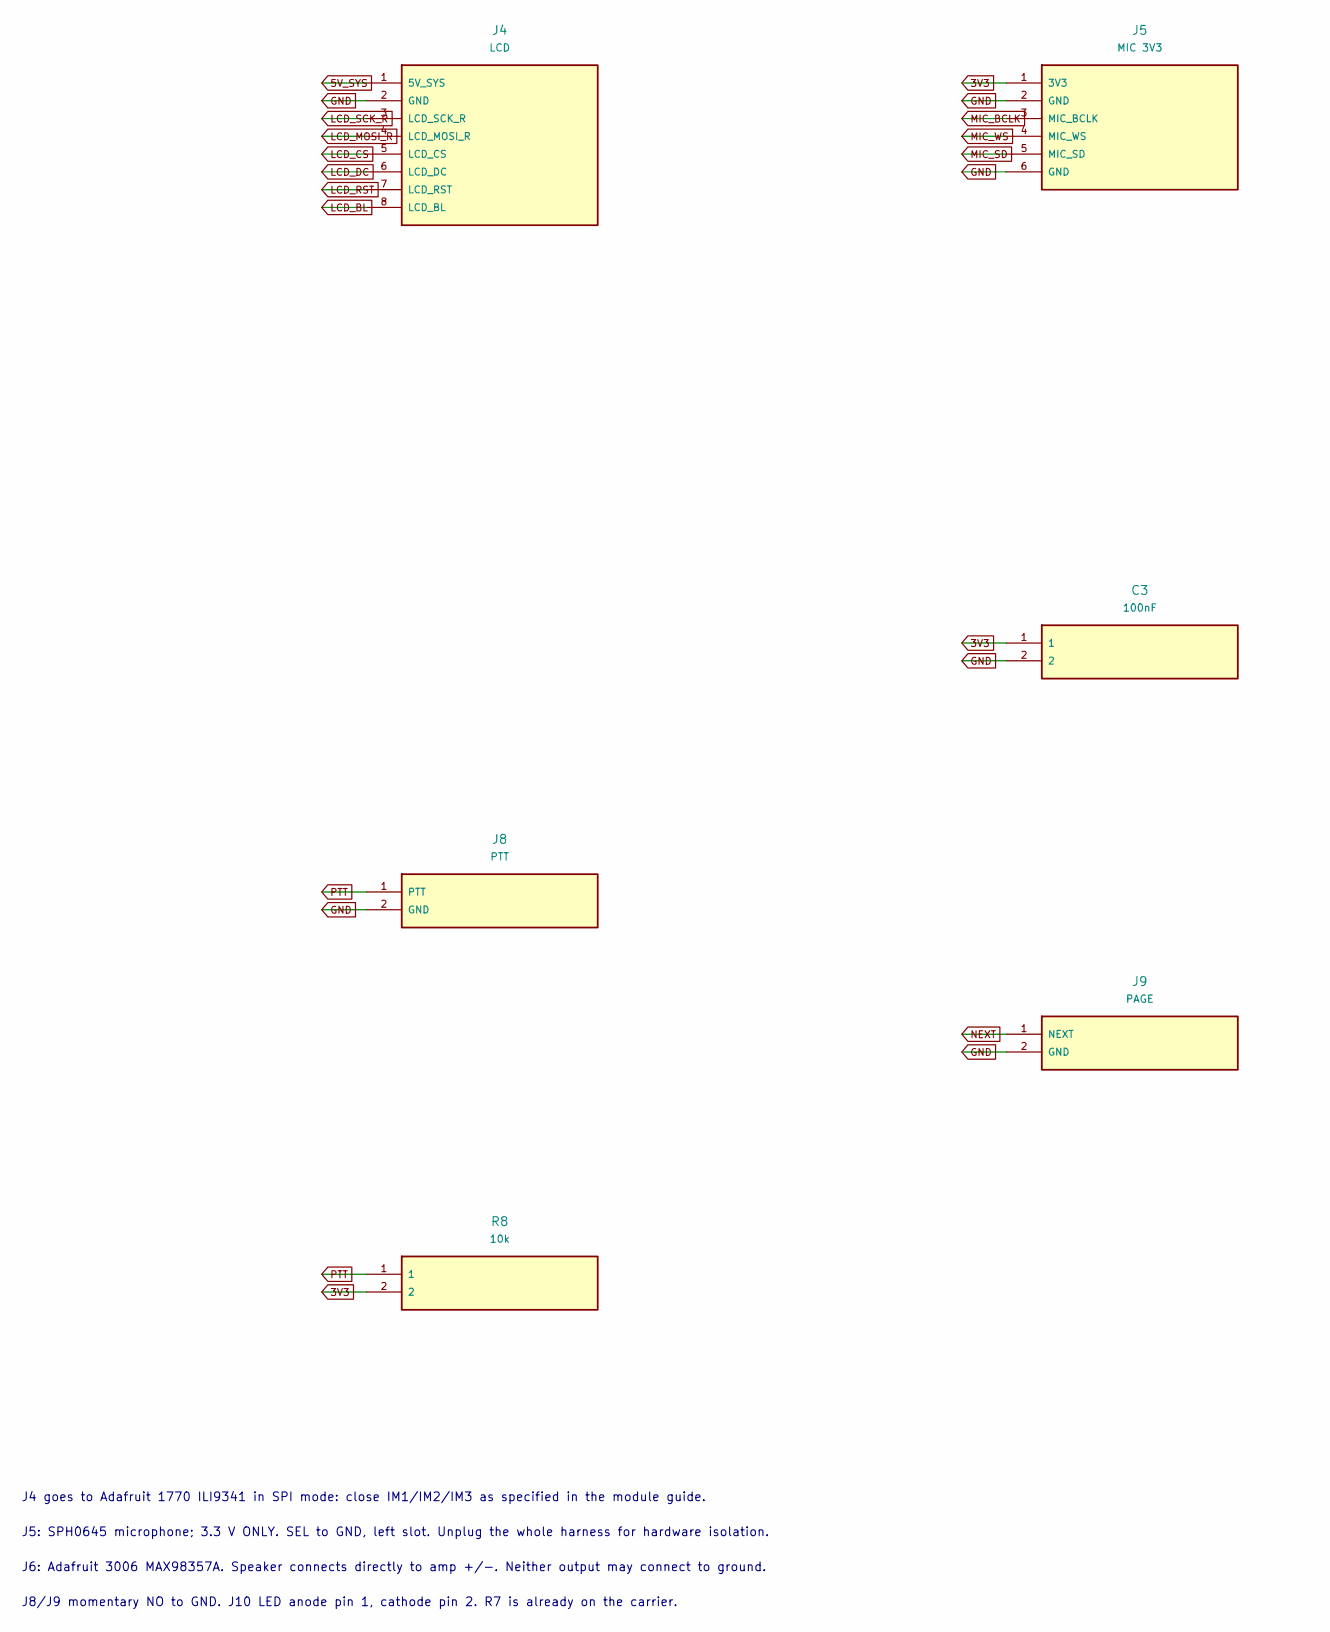
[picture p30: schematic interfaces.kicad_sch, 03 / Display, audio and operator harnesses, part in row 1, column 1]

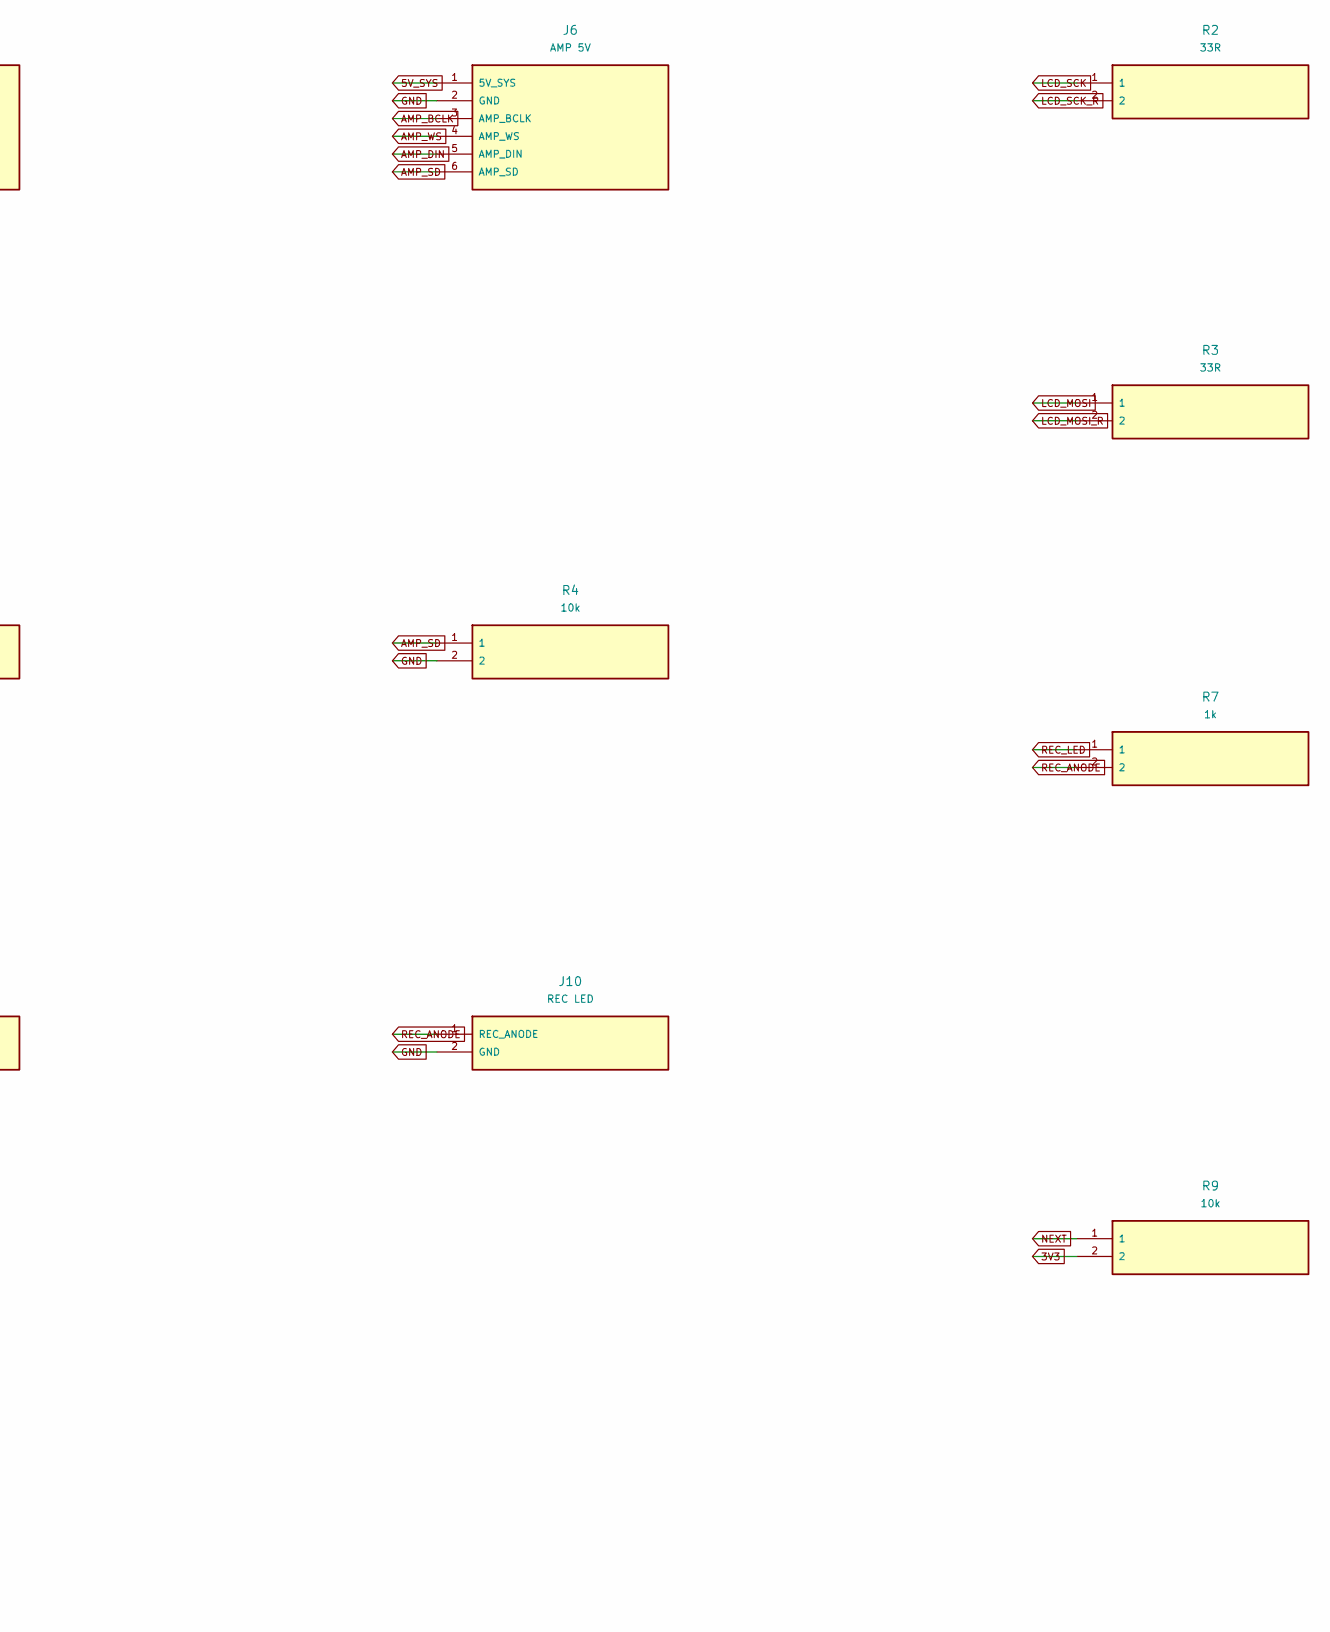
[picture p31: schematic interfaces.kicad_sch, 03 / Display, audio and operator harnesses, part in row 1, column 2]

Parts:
C3: 100nF; C_0805_2012Metric_C3
J4: LCD; XH_1x08_P2.50_J4
J5: MIC 3V3; XH_1x06_P2.50_J5
J6: AMP 5V; XH_1x06_P2.50_J6
J8: PTT; XH_1x02_P2.50_J8
J9: PAGE; XH_1x02_P2.50_J9
J10: REC LED; XH_1x02_P2.50_J10
R2: 33R; R_0805_2012Metric_R2
R3: 33R; R_0805_2012Metric_R3
R4: 10k; R_0805_2012Metric_R4
R7: 1k; R_0805_2012Metric_R7
R8: 10k; R_0805_2012Metric_R8
R9: 10k; R_0805_2012Metric_R9

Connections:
3V3: C3.1, J5.1 (3V3), R8.2, R9.2; also elsewhere on the board
5V_SYS: J4.1 (5V_SYS), J6.1 (5V_SYS); also elsewhere on the board
AMP_BCLK: J6.3 (AMP_BCLK); also elsewhere on the board
AMP_DIN: J6.5 (AMP_DIN); also elsewhere on the board
AMP_SD: J6.6 (AMP_SD), R4.1; also elsewhere on the board
AMP_WS: J6.4 (AMP_WS); also elsewhere on the board
GND: C3.2, J4.2 (GND), J5.2 (GND), J5.6 (GND), J6.2 (GND), J8.2 (GND), J9.2 (GND), J10.2 (GND), R4.2; also elsewhere on the board
LCD_BL: J4.8 (LCD_BL); also elsewhere on the board
LCD_CS: J4.5 (LCD_CS); also elsewhere on the board
LCD_DC: J4.6 (LCD_DC); also elsewhere on the board
LCD_MOSI: R3.1; also elsewhere on the board
LCD_MOSI_R: J4.4 (LCD_MOSI_R), R3.2
LCD_RST: J4.7 (LCD_RST); also elsewhere on the board
LCD_SCK: R2.1; also elsewhere on the board
LCD_SCK_R: J4.3 (LCD_SCK_R), R2.2
MIC_BCLK: J5.3 (MIC_BCLK); also elsewhere on the board
MIC_SD: J5.5 (MIC_SD); also elsewhere on the board
MIC_WS: J5.4 (MIC_WS); also elsewhere on the board
NEXT: J9.1 (NEXT), R9.1; also elsewhere on the board
PTT: J8.1 (PTT), R8.1; also elsewhere on the board
REC_ANODE: J10.1 (REC_ANODE), R7.2
REC_LED: R7.1; also elsewhere on the board

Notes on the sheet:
J4 goes to Adafruit 1770 ILI9341 in SPI mode: close IM1/IM2/IM3 as specified in the module guide.
J5: SPH0645 microphone; 3.3 V ONLY. SEL to GND, left slot. Unplug the whole harness for hardware isolation.
J6: Adafruit 3006 MAX98357A. Speaker connects directly to amp +/-. Neither output may connect to ground.
J8/J9 momentary NO to GND. J10 LED anode pin 1, cathode pin 2. R7 is already on the carrier.

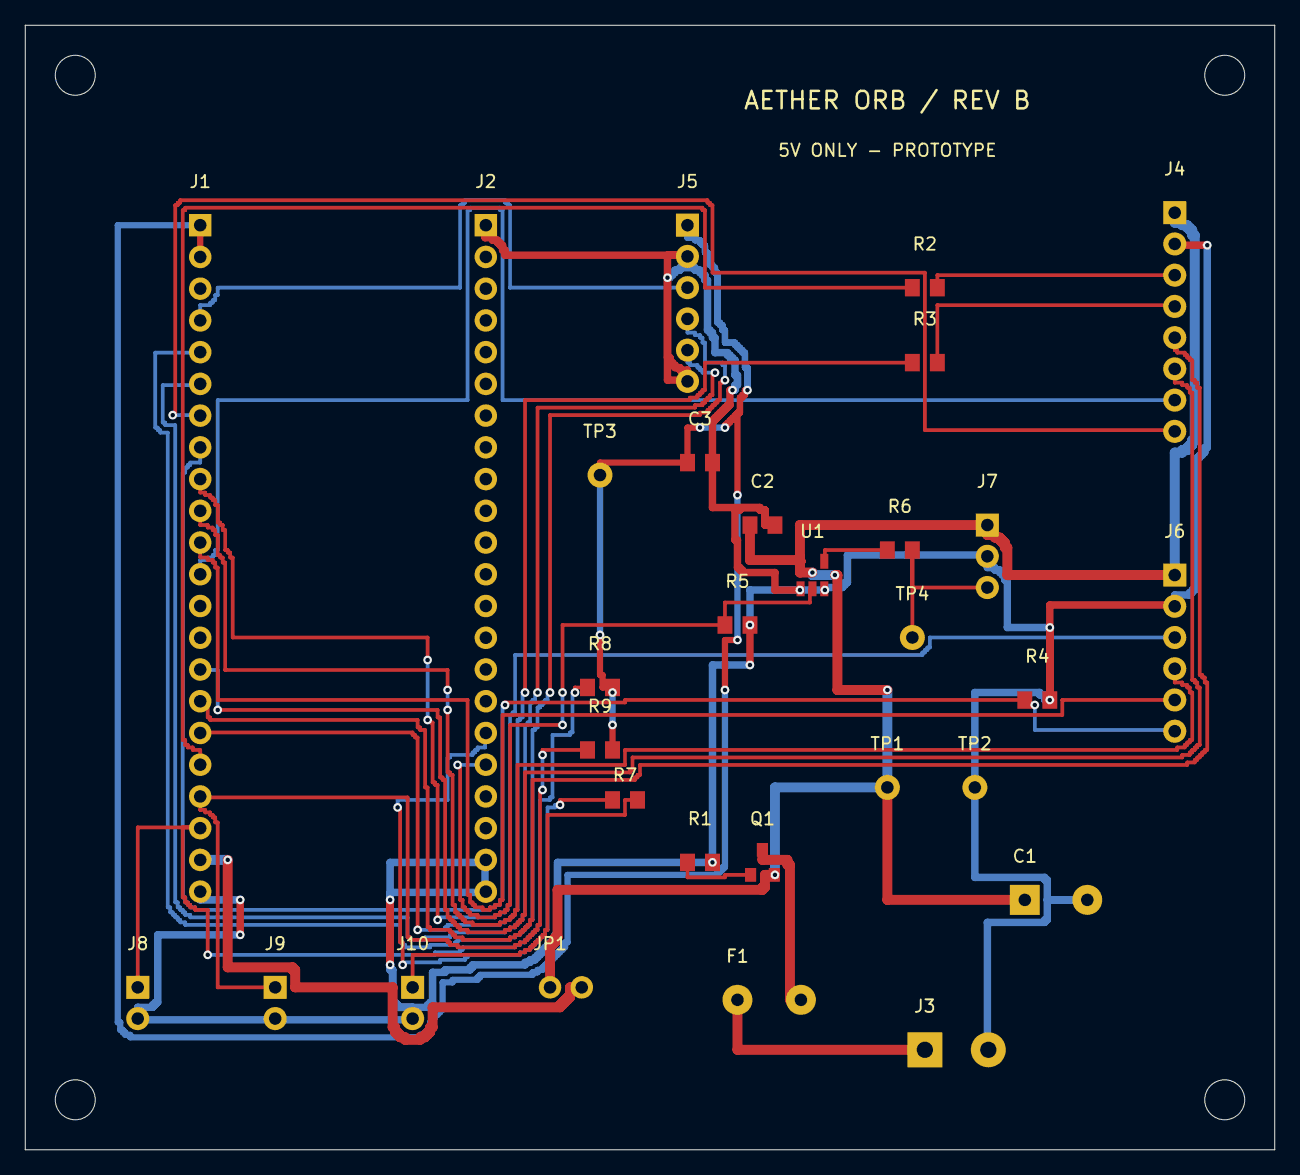
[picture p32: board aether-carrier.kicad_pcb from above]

Board: 2 copper layers, 100.0 x 90.0 mm, 34 parts (0 on the bottom side), 29 nets.

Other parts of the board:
H1, H2, H3, H4: MountingHole_3.2

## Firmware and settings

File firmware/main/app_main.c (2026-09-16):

#include "audio.h"
#include "config.h"
#include "display.h"
#include "halo.h"
#include "network.h"
#include "pins.h"
#include "sdkconfig.h"
#include "driver/gpio.h"
#include "esp_log.h"
#include "esp_timer.h"
#include "freertos/FreeRTOS.h"
#include "freertos/task.h"
#include <stdlib.h>
#include <string.h>
static orb_config_t config;
static char text[ORB_TEXT_MAX+1];
static void delay(unsigned ms){vTaskDelay(pdMS_TO_TICKS(ms));}
static bool pressed(int pin){if(gpio_get_level(pin))return false;delay(35);return !gpio_get_level(pin);}
static void fatal(const char *message){orb_audio_mute();(void)orb_halo_rgb(8,0,0);(void)orb_display_status("SERVICE REQUIRED",message);for(;;)delay(1000);}
void app_main(void){
    /* Never log SSIDs, tokens, audio, questions or generated text. */
    esp_log_level_set("HTTP_CLIENT",ESP_LOG_NONE);
    gpio_config_t inputs={.pin_bit_mask=(1ULL<<PIN_PTT)|(1ULL<<PIN_NEXT),.mode=GPIO_MODE_INPUT,.pull_up_en=GPIO_PULLUP_ENABLE};
    ESP_ERROR_CHECK(gpio_config(&inputs));
    ESP_ERROR_CHECK(orb_audio_init());ESP_ERROR_CHECK(orb_halo_init());ESP_ERROR_CHECK(orb_display_init());
#ifdef CONFIG_ORB_CALIBRATION_BOOT
    (void)orb_display_calibration();(void)orb_halo_rgb(0,0,0);for(;;)delay(1000);
#endif
    if(orb_config_load(&config)!=ESP_OK)fatal("NO VALID CONFIG. REMOVE DEVKIT FROM BOTH SOCKETS. PROVISION USB USING THE FACTORY TOOL.");
    (void)orb_display_status("CONNECTING","WAITING FOR WIFI AND A VALID CLOCK. MICROPHONE IS OFF.");
    /* Reconnect continues via event handler after timeout; main loop never skips TLS validation. */
    (void)orb_network_init(&config);
    (void)orb_display_status("AETHER ORB","AI ENTERTAINMENT. HOLD TALK TO RECORD. RELEASE TO ASK. PAGE CHANGES TEXT. VOICE IS OFF BY DEFAULT.");
    size_t offset=0,next=0;unsigned page=1;int64_t erase_at=0;bool disconnected=false;bool ptt_armed=true,page_armed=true;
    for(;;){
        /* Privacy deadline must run even while offline; never retain an old answer
           just because reconnect cannot complete. Clear immediately on disconnect. */
        if(erase_at && esp_timer_get_time() >= erase_at){
            orb_wipe(text,sizeof text);erase_at=0;offset=0;next=0;page=1;
            (void)orb_display_status("READY","LAST RESPONSE ERASED. HOLD TALK TO ASK.");
        }
        if(!orb_network_online()){
            if(!disconnected){orb_wipe(text,sizeof text);erase_at=0;offset=0;next=0;page=1;(void)orb_display_status("OFFLINE","CHECK WIFI, DNS AND CLOCK. NO AUDIO IS RECORDED OR QUEUED.");disconnected=true;}
            (void)orb_halo_rgb(6,2,0);delay(500);continue;
        }
        if(disconnected){(void)orb_display_status("READY","HOLD TALK TO ASK. AI ENTERTAINMENT ONLY.");disconnected=false;}
        if(gpio_get_level(PIN_PTT))ptt_armed=true;
        if(gpio_get_level(PIN_NEXT))page_armed=true;
        if(ptt_armed&&pressed(PIN_PTT)){
            ptt_armed=false;
            orb_wipe(text,sizeof text);erase_at=0;offset=0;next=0;page=1;
            (void)orb_display_status("RECORDING","RELEASE TALK TO SEND. MAXIMUM EIGHT SECONDS. RED PANEL LED INDICATES CAPTURE.");(void)orb_halo_rgb(6,0,1);
            uint8_t *wav=NULL;size_t bytes=0;esp_err_t e=orb_audio_record(&wav,&bytes);
            if(e==ESP_OK){
                (void)orb_display_status("CONSULTING","MICROPHONE IS OFF. REQUESTING AN AI-GENERATED REFLECTION.");(void)orb_halo_rgb(3,0,12);
                e=orb_fortune(wav,bytes,text);orb_wipe(wav,bytes);free(wav);
            }
            if(e==ESP_OK){
                char lines[ORB_ROWS][ORB_COLUMNS+1];next=orb_page(text,0,lines);orb_wipe(lines,sizeof lines);
                (void)orb_display_page(text,0,page);erase_at=esp_timer_get_time()+(int64_t)CONFIG_ORB_AUTO_ERASE_SECONDS*1000000;
                (void)orb_halo_rgb(1,0,3);
#ifdef CONFIG_ORB_PUBLIC_TTS
                uint8_t *pcm=NULL;size_t pcm_bytes=0;
                /* Do not leave private text visible during blocking speech I/O. */
                (void)orb_display_status("AI VOICE", "MICROPHONE OFF. TEXT HIDDEN DURING SPEECH. PRESS TALK TO STOP PLAYBACK.");
                if(orb_speech(text,&pcm,&pcm_bytes)==ESP_OK){(void)orb_audio_play(pcm,pcm_bytes);orb_wipe(pcm,pcm_bytes);free(pcm);}
                if(esp_timer_get_time()<erase_at)(void)orb_display_page(text,offset,page);
                else{orb_wipe(text,sizeof text);erase_at=0;(void)orb_display_status("READY","LAST RESPONSE ERASED.");}
#endif
            }else{
                (void)orb_display_status("PLEASE TRY AGAIN","RECORD AT LEAST HALF A SECOND. CHECK NETWORK AND GATEWAY. NOTHING WAS SAVED ON THE ORB.");(void)orb_halo_rgb(7,1,0);
            }
        }
        if(page_armed&&pressed(PIN_NEXT)){
            page_armed=false;
            if(text[0]){if(next>=strlen(text)){offset=0;page=1;}else{offset=next;page++;}
                char lines[ORB_ROWS][ORB_COLUMNS+1];next=orb_page(text,offset,lines);orb_wipe(lines,sizeof lines);(void)orb_display_page(text,offset,page);}
        }
        if(!text[0]){unsigned phase=(unsigned)(esp_timer_get_time()/200000)%24;unsigned glow=phase<12?phase:24-phase;(void)orb_halo_rgb(2+glow/3,0,4+glow);}
        delay(35);
    }
}

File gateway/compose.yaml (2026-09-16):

services:
  gateway:
    build:
      context: ..
      dockerfile: gateway/Dockerfile
    env_file: .env
    restart: unless-stopped
    read_only: true
    cap_drop: [ALL]
    security_opt: [no-new-privileges:true]
    tmpfs: [/tmp:size=16m,noexec,nosuid]
    volumes:
      - orb_budget:/var/lib/orb
    mem_limit: 256m
    pids_limit: 100
    expose: ["8080"]
    ulimits:
      core: 0
    healthcheck:
      test: ["CMD", "python", "-c", "import urllib.request; urllib.request.urlopen('http://127.0.0.1:8080/healthz', timeout=3).read()"]
      interval: 30s
      timeout: 5s
      retries: 3
      start_period: 10s
  tls:
    image: caddy:2
    environment:
      ORB_HOST: ${ORB_HOST:-orb-gateway.home.arpa}
    restart: unless-stopped
    depends_on:
      gateway:
        condition: service_healthy
    ports: ["443:443"]
    volumes:
      - ./Caddyfile:/etc/caddy/Caddyfile:ro
      - caddy_data:/data
      - caddy_config:/config
    security_opt: [no-new-privileges:true]
volumes:
  orb_budget:
  caddy_data:
  caddy_config:

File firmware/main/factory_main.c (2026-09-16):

#include "diagnostics.h"
#include "audio.h"
#include "display.h"
#include "halo.h"
#include "pins.h"
#include "driver/gpio.h"

/* Deliberately no configuration, NVS, network, time synchronization or API path. */
void app_main(void) {
    gpio_config_t inputs={.pin_bit_mask=(1ULL<<PIN_PTT)|(1ULL<<PIN_NEXT),
        .mode=GPIO_MODE_INPUT,.pull_up_en=GPIO_PULLUP_ENABLE};
    ESP_ERROR_CHECK(gpio_config(&inputs));
    ESP_ERROR_CHECK(orb_audio_init());
    ESP_ERROR_CHECK(orb_halo_init());
    ESP_ERROR_CHECK(orb_display_init());
    orb_diagnostics_run();
}

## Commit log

2026-09-16 chore: initialize CrystalBall and establish traceable Rev A import
2026-09-16 import: preserve 63 supplied Rev A files byte-for-byte (SHA-256 verified)
    [Aether_Orb_RevA_Assembly.step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]
2026-09-16 ci: add independent KiCad and ESP32-S3 target build gates
2026-09-16 fix(firmware): resolve lwIP symbol collision and erase private responses while offline
    [app_main.c]
2026-09-16 fix(firmware): resolve ESP-IDF 5.5.2 compiler failures and wipe display scratch text
    [display.c, halo.c]
2026-09-16 engineering: publish Rev B CAD corrections and reproducible native verification batch
    [local_libraries.py]
2026-09-16 engineering: Rev B zero-interference CAD, sealed STL meshes and carrier corrections
    [01_base_shell.step, 01_base_shell.stl, 02_bottom_cover.step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]
2026-09-16 feat: WebGPU crystal studio, CAD inspector and secured text/audio/realtime gateway
2026-09-16 fix: bound GPU submission, unlock mobile audio and harden private response lifetime
    [app_main.c]
2026-09-16 ci: pin KiCad 9.0.9, export native CAM and verify three firmware profiles plus Docker
2026-09-16 manufacturing: add traceable handbook sources, release gates and complete handoff packaging
2026-09-16 manufacturing: publish Rev B handbook, BOMs, harness, native CAM and verified evidence; production remains gated
    [acceptance-plan.csv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]
2026-09-16 deploy: stage browser-only GitHub Pages site with repository-subpath WebGPU verification
2026-09-16 fix(packaging): remove stale tracked Python build output and verify installed wheel source parity
2026-09-16 perf(web): bound render surfaces, idle CAD redraws and GPU lifetimes; add pinch and keyboard controls
2026-09-16 test(web): keep renderer polling CSP-safe and eliminate CAD packing temporaries
2026-09-16 fix(web): guard asynchronous workspace switches and keep fallback and motion controls accessible
